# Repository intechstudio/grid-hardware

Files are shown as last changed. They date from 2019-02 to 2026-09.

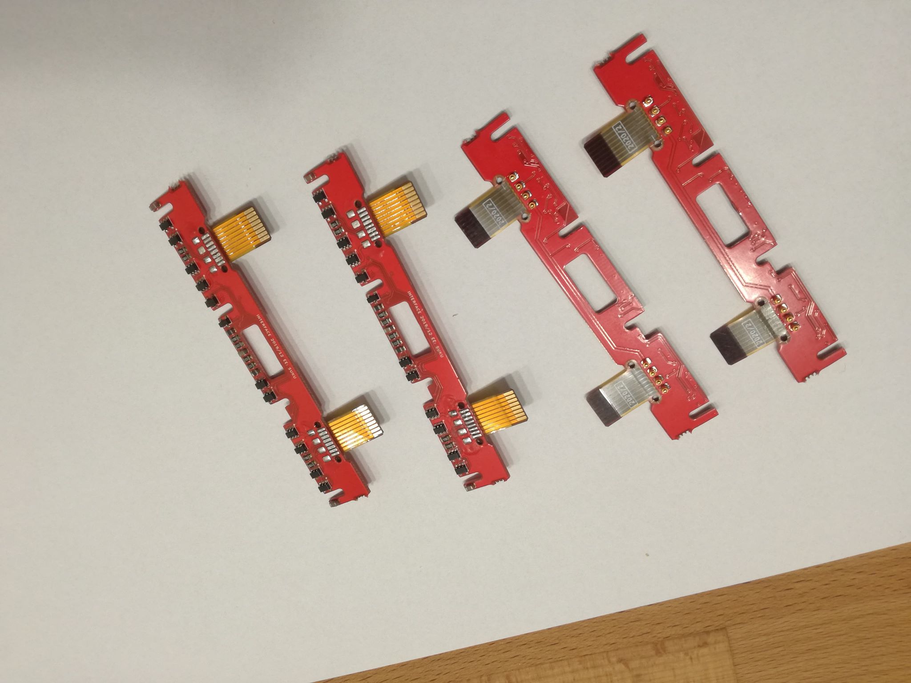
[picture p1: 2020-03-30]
Electrical/Bill Of Materials/Photos/interface.jpg

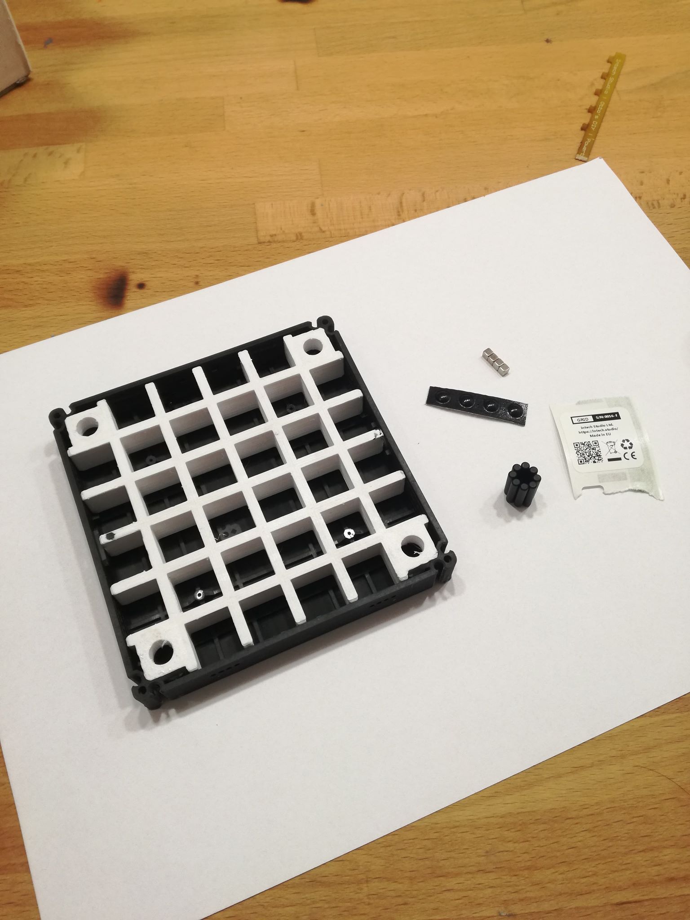
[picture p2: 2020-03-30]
Electrical/Bill Of Materials/Photos/canvas.jpg

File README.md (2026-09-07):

# Open-Source Hardware
https://certification.oshwa.org/hu000001.html

Licence: GPL3

# Mechanical components

| Component | Part number | Type | Preview | Links |
|---|---|---|---|---|
| Lower housing | PLASTIC-CANVAS | Fabricated |  | [[Model tree]](CANVAS.md) [[Download]](https://github.com/intechstudio/grid-hardware/releases/download/nightly-mechanical/PLASTIC-CANVAS.zip) |
| Mapmode button | PLASTIC-MAPMODE | Fabricated |  | [[Download]](https://github.com/intechstudio/grid-hardware/releases/download/nightly-mechanical/PLASTIC-MAPMODE.zip) | 
| Magnet cover | PLASTIC-MAGNET-COVER | Fabricated |  | [[Download]](https://github.com/intechstudio/grid-hardware/releases/download/nightly-mechanical/PLASTIC-MAGNET-COVER.zip) |  
| Rubber foot | RUBBER-FOOT | Fabricated |  | [[Download]](https://github.com/intechstudio/grid-hardware/releases/download/nightly-mechanical/RUBBER-FOOT.zip) |
| D3x14mm N52 neodymium | MAGNET-D3x14 | Fabricated |  | [[Download]](https://github.com/intechstudio/grid-hardware/releases/download/nightly-mechanical/MAGNET-D3x14.zip) |
| 3x3x3mm N52 neodymium | MAGNET-SQ3 | Fabricated |  | [[Download]](https://github.com/intechstudio/grid-hardware/releases/download/nightly-mechanical/MAGNET-SQ3.zip) |
| Crown | SPACER | Fabricated |  | [[Download]](https://github.com/intechstudio/grid-hardware/releases/download/nightly-mechanical/SPACER.zip) |
| Metric corner screw | SCREW-M1.6x16 | Purchased  |  | [[Download]](https://github.com/intechstudio/grid-hardware/releases/download/nightly-mechanical/SCREW-M1.6x16.zip) |
| Metric PCB screw | SCREW-M1.6x8 | Purchased  |  | [[Download]](https://github.com/intechstudio/grid-hardware/releases/download/nightly-mechanical/SCREW-M1.6x8.zip) |
| Metric PCB screw | SCREW-M1.6x5-C | Purchased  |  | [[Download]](https://github.com/intechstudio/grid-hardware/releases/download/nightly-mechanical/SCREW-M1.6x5-C.zip) |
| Brass threaded insert 3mm | INSERT-M1.6x2.5x3 | Purchased  |  | [[Download]](https://github.com/intechstudio/grid-hardware/releases/download/nightly-mechanical/INSERT-M1.6x2.5x3.zip) |
| Brass threaded insert 4mm | INSERT-M1.6x2.5x4 | Purchased  |  | [[Download]](https://github.com/intechstudio/grid-hardware/releases/download/nightly-mechanical/INSERT-M1.6x2.5x4.zip) |
| Lightpipe | PLASTIC-LIGHTPIPE | Purchased  |  | [[Download]](https://github.com/intechstudio/grid-hardware/releases/download/nightly-mechanical/PLASTIC-LIGHTPIPE.zip) |
| Encoder Knob Injection | PLASTIC-KNOB-ENC | Fabricated |  | [[Download]](https://github.com/intechstudio/grid-hardware/releases/download/nightly-mechanical/PLASTIC-KNOB-ENC.zip) |
| Potmeter Knob Injection | PLASTIC-KNOB-POT | Fabricated |  | [[Download]](https://github.com/intechstudio/grid-hardware/releases/download/nightly-mechanical/PLASTIC-KNOB-POT.zip) |
| Encoder | THT-ENC | Purchased  |  | [[Download]](https://github.com/intechstudio/grid-hardware/releases/download/nightly-mechanical/THT-ENC.zip) |
| Potmeter | THT-POT | Purchased  |  | [[Download]](https://github.com/intechstudio/grid-hardware/releases/download/nightly-mechanical/THT-POT.zip) |
| Fader | THT-FADER | Purchased  |  | [[Download]](https://github.com/intechstudio/grid-hardware/releases/download/nightly-mechanical/THT-FADER.zip) |
| Long Fader | THT-LONGFADER | Purchased  |  | [[Download]](https://github.com/intechstudio/grid-hardware/releases/download/nightly-mechanical/THT-LONGFADER.zip) |
| Fader Cap | PLASTIC-CAP-FADER | Purchased  |  | [[Download]](https://github.com/intechstudio/grid-hardware/releases/download/nightly-mechanical/PLASTIC-CAP-FADER.zip) |
| Fader Insert | INSERT-FADER | Fabricated  |  | [[Download]](https://github.com/intechstudio/grid-hardware/releases/download/nightly-mechanical/INSERT-FADER.zip) |
| Button | THT-BUTTON | Purchased  |  | [[Download]](https://github.com/intechstudio/grid-hardware/releases/download/nightly-mechanical/THT-BUTTON.zip) |
| Button Cap | PLASTIC-CAP-BUTTON | Purchased  |  | [[Download]](https://github.com/intechstudio/grid-hardware/releases/download/nightly-mechanical/PLASTIC-CAP-BUTTON.zip) |
| Hall Switch | THT-HALL-SWITCH | Purchased  |  | [[Download]](https://github.com/intechstudio/grid-hardware/releases/download/nightly-mechanical/THT-HALL-SWITCH.zip) |
| Low Profile Keycap | PLASTIC-LOW-PROFILE-KEYCAP | Purchased  |  | [[Download]](https://github.com/intechstudio/grid-hardware/releases/download/nightly-mechanical/PLASTIC-LOW-PROFILE-KEYCAP.zip) |
| Battery Connector | SMT-CONN-BATTERY | Purchased  |  | [[Download]](https://github.com/intechstudio/grid-hardware/releases/download/nightly-mechanical/SMT-CONN-BATTERY.zip) |
| Pogo Connector | SMT-CONN-POGO | Purchased  |  | [[Download]](https://github.com/intechstudio/grid-hardware/releases/download/nightly-mechanical/SMT-CONN-POGO.zip) |

# TEK2 specific components
| Component | Part number | Type | Preview | Links |
|---|---|---|---|---|
| Knob TEK2 | KNOB-TEK2 | Fabricated |  | [[Download]](https://github.com/intechstudio/grid-hardware/releases/download/nightly-mechanical/KNOB-TEK2.zip) |
| Knob interface TEK2 | PLASTIC-TEK2-KNOB-INTERFACE | Fabricated |  | [[Download]](https://github.com/intechstudio/grid-hardware/releases/download/nightly-mechanical/PLASTIC-TEK2-KNOB-INTERFACE.zip) |
| Endless potentiometer | THT-ENDLESSPOT | Purchased  |  | [[Download]](https://github.com/intechstudio/grid-hardware/releases/download/nightly-mechanical/THT-ENDLESSPOT.zip) |

# VSN1 specific components
| Component | Part number | Type | Preview | Links |
|---|---|---|---|---|
| VSN1 Display | SMT-VSN1-DISPLAY | Purchased |  | [[Download]](https://github.com/intechstudio/grid-hardware/releases/download/nightly-mechanical/SMT-VSN1-DISPLAY.zip) |
| VSN1 Display interface | PLASTIC-VSN1-DISPLAY-INTERFACE | Fabricated |  | [[Download]](https://github.com/intechstudio/grid-hardware/releases/download/nightly-mechanical/PLASTIC-VSN1-DISPLAY-INTERFACE.zip) |
| VSN1 Button | PLASTIC-VSN1-BUTTON | Fabricated |  | [[Download]](https://github.com/intechstudio/grid-hardware/releases/download/nightly-mechanical/PLASTIC-VSN1-BUTTON.zip) |

## PCB Frontpanel
| Component | Part number | Preview | Links |
|---|---|---|---|
| XX16 Frontpanel | FP-XX16 |  | [[STEP]](https://github.com/intechstudio/grid-hardware/releases/download/nightly-electrical/FP-XX16-3D.step) [[PCB3D]](https://github.com/intechstudio/grid-hardware/releases/download/nightly-electrical/FP-XX16-blender_export.pcb3d) [[Gerber]](https://github.com/intechstudio/grid-hardware/releases/download/nightly-electrical/FP-XX16-gerber.zip) |
| BU16 Frontpanel | FP-BU16 |  | [[STEP]](https://github.com/intechstudio/grid-hardware/releases/download/nightly-electrical/FP-BU16-3D.step) [[PCB3D]](https://github.com/intechstudio/grid-hardware/releases/download/nightly-electrical/FP-BU16-blender_export.pcb3d) [[Gerber]](https://github.com/intechstudio/grid-hardware/releases/download/nightly-electrical/FP-BU16-gerber.zip) |
| PBF4 Frontpanel | FP-PBF4 |  | [[STEP]](https://github.com/intechstudio/grid-hardware/releases/download/nightly-electrical/FP-PBF4-3D.step) [[PCB3D]](https://github.com/intechstudio/grid-hardware/releases/download/nightly-electrical/FP-PBF4-blender_export.pcb3d) [[Gerber]](https://github.com/intechstudio/grid-hardware/releases/download/nightly-electrical/FP-PBF4-gerber.zip) |
| EF44 Frontpanel | FP-EF44 |  | [[STEP]](https://github.com/intechstudio/grid-hardware/releases/download/nightly-electrical/FP-EF44-3D.step) [[PCB3D]](https://github.com/intechstudio/grid-hardware/releases/download/nightly-electrical/FP-EF44-blender_export.pcb3d) [[Gerber]](https://github.com/intechstudio/grid-hardware/releases/download/nightly-electrical/FP-EF44-gerber.zip) |
| TEK2 Frontpanel | FP-TEK2 |  | [[STEP]](https://github.com/intechstudio/grid-hardware/releases/download/nightly-electrical/FP-TEK2-3D.step) [[PCB3D]](https://github.com/intechstudio/grid-hardware/releases/download/nightly-electrical/FP-TEK2-blender_export.pcb3d) [[Gerber]](https://github.com/intechstudio/grid-hardware/releases/download/nightly-electrical/FP-TEK2-gerber.zip) |
| VSN1-L Frontpanel | FP-VSN1-L |  | [[STEP]](https://github.com/intechstudio/grid-hardware/releases/download/nightly-electrical/FP-VSN1-L-3D.step) [[PCB3D]](https://github.com/intechstudio/grid-hardware/releases/download/nightly-electrical/FP-VSN1-L-blender_export.pcb3d) [[Gerber]](https://github.com/intechstudio/grid-hardware/releases/download/nightly-electrical/FP-VSN1-L-gerber.zip) |
| VSN1-R Frontpanel | FP-VSN1-R |  | [[STEP]](https://github.com/intechstudio/grid-hardware/releases/download/nightly-electrical/FP-VSN1-R-3D.step) [[PCB3D]](https://github.com/intechstudio/grid-hardware/releases/download/nightly-electrical/FP-VSN1-R-blender_export.pcb3d) [[Gerber]](https://github.com/intechstudio/grid-hardware/releases/download/nightly-electrical/FP-VSN1-R-gerber.zip) |
| VSN2 Frontpanel | FP-VSN2 |  | [[STEP]](https://github.com/intechstudio/grid-hardware/releases/download/nightly-electrical/FP-VSN2-3D.step) [[PCB3D]](https://github.com/intechstudio/grid-hardware/releases/download/nightly-electrical/FP-VSN2-blender_export.pcb3d) [[Gerber]](https://github.com/intechstudio/grid-hardware/releases/download/nightly-electrical/FP-VSN2-gerber.zip) |
| OCTV Frontpanel | FP-OCTV |  | [[STEP]](https://github.com/intechstudio/grid-hardware/releases/download/nightly-electrical/FP-OCTV-3D.step) [[PCB3D]](https://github.com/intechstudio/grid-hardware/releases/download/nightly-electrical/FP-OCTV-blender_export.pcb3d) [[Gerber]](https://github.com/intechstudio/grid-hardware/releases/download/nightly-electrical/FP-OCTV-gerber.zip) |
| ZONA Frontpanel | FP-ZONA |  | [[STEP]](https://github.com/intechstudio/grid-hardware/releases/download/nightly-electrical/FP-ZONA-3D.step) [[PCB3D]](https://github.com/intechstudio/grid-hardware/releases/download/nightly-electrical/FP-ZONA-blender_export.pcb3d) [[Gerber]](https://github.com/intechstudio/grid-hardware/releases/download/nightly-electrical/FP-ZONA-gerber.zip) |
| ZONA SPACER Frontpanel | FP-ZONA-SPACER |  | [[STEP]](https://github.com/intechstudio/grid-hardware/releases/download/nightly-electrical/FP-ZONA-SPACER-3D.step) [[PCB3D]](https://github.com/intechstudio/grid-hardware/releases/download/nightly-electrical/FP-ZONA-SPACER-blender_export.pcb3d) [[Gerber]](https://github.com/intechstudio/grid-hardware/releases/download/nightly-electrical/FP-ZONA-SPACER-gerber.zip) |
| ZONA Decor Frontpanel | FP-ZONA-DECOR |  | [[STEP]](https://github.com/intechstudio/grid-hardware/releases/download/nightly-electrical/FP-ZONA-DECOR-3D.step) [[PCB3D]](https://github.com/intechstudio/grid-hardware/releases/download/nightly-electrical/FP-ZONA-DECOR-blender_export.pcb3d) [[Gerber]](https://github.com/intechstudio/grid-hardware/releases/download/nightly-electrical/FP-ZONA-DECOR-gerber.zip) |

## PCB Frontpanel Collaborations
| Component | Part number | Preview | Links |
|---|---|---|---|
| BU16 MIDIGrade Frontpanel | FP-BU16-MIDIGRADE |  | [[STEP]](https://github.com/intechstudio/grid-hardware/releases/download/nightly-electrical/FP-BU16-MIDIGRADE-3D.step) [[PCB3D]](https://github.com/intechstudio/grid-hardware/releases/download/nightly-electrical/FP-BU16-MIDIGRADE-blender_export.pcb3d) [[Gerber]](https://github.com/intechstudio/grid-hardware/releases/download/nightly-electrical/FP-BU16-MIDIGRADE-gerber.zip) |
| BU16 MIDIGrade Frontpanel | FP-EN16-MIDIGRADE |  | [[STEP]](https://github.com/intechstudio/grid-hardware/releases/download/nightly-electrical/FP-EN16-MIDIGRADE-3D.step) [[PCB3D]](https://github.com/intechstudio/grid-hardware/releases/download/nightly-electrical/FP-EN16-MIDIGRADE-blender_export.pcb3d) [[Gerber]](https://github.com/intechstudio/grid-hardware/releases/download/nightly-electrical/FP-EN16-MIDIGRADE-gerber.zip) |
| PBF4 Classic Frontpanel | FP-PBF4-CLASSIC |  | [[STEP]](https://github.com/intechstudio/grid-hardware/releases/download/nightly-electrical/FP-PBF4-CLASSIC-3D.step) [[PCB3D]](https://github.com/intechstudio/grid-hardware/releases/download/nightly-electrical/FP-PBF4-CLASSIC-blender_export.pcb3d) [[Gerber]](https://github.com/intechstudio/grid-hardware/releases/download/nightly-electrical/FP-PBF4-CLASSIC-gerber.zip) |
| TEK2 Classic Frontpanel | FP-TEK2-CLASSIC |  | [[STEP]](https://github.com/intechstudio/grid-hardware/releases/download/nightly-electrical/FP-TEK2-CLASSIC-3D.step) [[PCB3D]](https://github.com/intechstudio/grid-hardware/releases/download/nightly-electrical/FP-TEK2-CLASSIC-blender_export.pcb3d) [[Gerber]](https://github.com/intechstudio/grid-hardware/releases/download/nightly-electrical/FP-TEK2-CLASSIC-gerber.zip) |
| XX16 Test Frontpanel | FP-XX16-TEST |  | [[STEP]](https://github.com/intechstudio/grid-hardware/releases/download/nightly-electrical/FP-XX16-TEST-3D.step) [[PCB3D]](https://github.com/intechstudio/grid-hardware/releases/download/nightly-electrical/FP-XX16-TEST-blender_export.pcb3d) [[Gerber]](https://github.com/intechstudio/grid-hardware/releases/download/nightly-electrical/FP-XX16-TEST-gerber.zip) |

## Electrical components

| Component | Part number | Preview | Links |
|---|---|---|---|
| Debug Acessory | PCBA-DEBUG-ACCESSORY |  | [[Schematic]](https://github.com/intechstudio/grid-hardware/releases/download/nightly-electrical/PCBA-DEBUG-ACCESSORY_Schematic.pdf) [[STEP]](https://github.com/intechstudio/grid-hardware/releases/download/nightly-electrical/PCBA-DEBUG-ACCESSORY-3D.step) [[Gerber]](https://github.com/intechstudio/grid-hardware/releases/download/nightly-electrical/PCBA-DEBUG-ACCESSORY-gerber.zip)  [[PCB3D]](https://github.com/intechstudio/grid-hardware/releases/download/nightly-electrical/PCBA-DEBUG-ACCESSORY-blender_export.pcb3d)  |
| Debug UART | PCBA-DEBUG-UART |  | [[Schematic]](https://github.com/intechstudio/grid-hardware/releases/download/nightly-electrical/PCBA-DEBUG-UART_Schematic.pdf) [[STEP]](https://github.com/intechstudio/grid-hardware/releases/download/nightly-electrical/PCBA-DEBUG-UART-3D.step) [[Gerber]](https://github.com/intechstudio/grid-hardware/releases/download/nightly-electrical/PCBA-DEBUG-UART-gerber.zip)  [[PCB3D]](https://github.com/intechstudio/grid-hardware/releases/download/nightly-electrical/PCBA-DEBUG-UART-blender_export.pcb3d)  |
| Interface Board | PCBA-INTERFACE |  | [[Schematic]](https://github.com/intechstudio/grid-hardware/releases/download/nightly-electrical/PCBA-INTERFACE_Schematic.pdf) [[STEP]](https://github.com/intechstudio/grid-hardware/releases/download/nightly-electrical/PCBA-INTERFACE-3D.step) [[Gerber]](https://github.com/intechstudio/grid-hardware/releases/download/nightly-electrical/PCBA-INTERFACE-gerber.zip)  [[PCB3D]](https://github.com/intechstudio/grid-hardware/releases/download/nightly-electrical/PCBA-INTERFACE-blender_export.pcb3d)  |
| PO16/BU16 Motherboard | PCBA-PO16 |  | [[schematic]](https://github.com/intechstudio/grid-hardware/releases/download/nightly-electrical/PCBA-PO16_Schematic.pdf) [[STEP]](https://github.com/intechstudio/grid-hardware/releases/download/nightly-electrical/PCBA-PO16-3D.step) [[PCB3D]](https://github.com/intechstudio/grid-hardware/releases/download/nightly-electrical/PCBA-PO16-blender_export.pcb3d) [[Gerber]](https://github.com/intechstudio/grid-hardware/releases/download/nightly-electrical/PCBA-PO16-gerber.zip) |
| ZONA Motherboard | PCBA-ZONA |  | [[schematic]](https://github.com/intechstudio/grid-hardware/releases/download/nightly-electrical/PCBA-ZONA_Schematic.pdf) [[STEP]](https://github.com/intechstudio/grid-hardware/releases/download/nightly-electrical/PCBA-ZONA-3D.step) [[PCB3D]](https://github.com/intechstudio/grid-hardware/releases/download/nightly-electrical/PCBA-ZONA-blender_export.pcb3d) [[Gerber]](https://github.com/intechstudio/grid-hardware/releases/download/nightly-electrical/PCBA-ZONA-gerber.zip) |
| BU16 Motherboard | PCBA-BU16 |  | [[schematic]](https://github.com/intechstudio/grid-hardware/releases/download/nightly-electrical/PCBA-BU16_Schematic.pdf) [[STEP]](https://github.com/intechstudio/grid-hardware/releases/download/nightly-electrical/PCBA-BU16-3D.step) [[PCB3D]](https://github.com/intechstudio/grid-hardware/releases/download/nightly-electrical/PCBA-BU16-blender_export.pcb3d) [[Gerber]](https://github.com/intechstudio/grid-hardware/releases/download/nightly-electrical/PCBA-BU16-gerber.zip) |
| BU16 SPACER | PCBA-BU16-SPACER |  | [[schematic]](https://github.com/intechstudio/grid-hardware/releases/download/nightly-electrical/PCBA-BU16-SPACER_Schematic.pdf) [[STEP]](https://github.com/intechstudio/grid-hardware/releases/download/nightly-electrical/PCBA-BU16-SPACER-3D.step) [[PCB3D]](https://github.com/intechstudio/grid-hardware/releases/download/nightly-electrical/PCBA-BU16-SPACER-blender_export.pcb3d) [[Gerber]](https://github.com/intechstudio/grid-hardware/releases/download/nightly-electrical/PCBA-BU16-SPACER-gerber.zip) |
| BU16 PLATE | PCBA-BU16-PLATE |  | [[schematic]](https://github.com/intechstudio/grid-hardware/releases/download/nightly-electrical/PCBA-BU16-PLATE_Schematic.pdf) [[STEP]](https://github.com/intechstudio/grid-hardware/releases/download/nightly-electrical/PCBA-BU16-PLATE-3D.step) [[PCB3D]](https://github.com/intechstudio/grid-hardware/releases/download/nightly-electrical/PCBA-BU16-PLATE-blender_export.pcb3d) [[Gerber]](https://github.com/intechstudio/grid-hardware/releases/download/nightly-electrical/PCBA-BU16-PLATE-gerber.zip) |
| PBF4 SPACER | PCBA-PBF4-SPACER |  | [[schematic]](https://github.com/intechstudio/grid-hardware/releases/download/nightly-electrical/PCBA-PBF4-SPACER_Schematic.pdf) [[STEP]](https://github.com/intechstudio/grid-hardware/releases/download/nightly-electrical/PCBA-PBF4-SPACER-3D.step) [[PCB3D]](https://github.com/intechstudio/grid-hardware/releases/download/nightly-electrical/PCBA-PBF4-SPACER-blender_export.pcb3d) [[Gerber]](https://github.com/intechstudio/grid-hardware/releases/download/nightly-electrical/PCBA-PBF4-SPACER-gerber.zip) |
| PBF4 PLATE | PCBA-PBF4-PLATE |  | [[schematic]](https://github.com/intechstudio/grid-hardware/releases/download/nightly-electrical/PCBA-PBF4-PLATE_Schematic.pdf) [[STEP]](https://github.com/intechstudio/grid-hardware/releases/download/nightly-electrical/PCBA-PBF4-PLATE-3D.step) [[PCB3D]](https://github.com/intechstudio/grid-hardware/releases/download/nightly-electrical/PCBA-PBF4-PLATE-blender_export.pcb3d) [[Gerber]](https://github.com/intechstudio/grid-hardware/releases/download/nightly-electrical/PCBA-PBF4-PLATE-gerber.zip) |
| PBF4 Motherboard | PCBA-PBF4 |  | [[schematic]](https://github.com/intechstudio/grid-hardware/releases/download/nightly-electrical/PCBA-PBF4_Schematic.pdf) [[STEP]](https://github.com/intechstudio/grid-hardware/releases/download/nightly-electrical/PCBA-PBF4-3D.step) [[PCB3D]](https://github.com/intechstudio/grid-hardware/releases/download/nightly-electrical/PCBA-PBF4-blender_export.pcb3d) [[Gerber]](https://github.com/intechstudio/grid-hardware/releases/download/nightly-electrical/PCBA-PBF4-gerber.zip) |
| EN16 Motherboard | PCBA-EN16 |  | [[schematic]](https://github.com/intechstudio/grid-hardware/releases/download/nightly-electrical/PCBA-EN16_Schematic.pdf) [[STEP]](https://github.com/intechstudio/grid-hardware/releases/download/nightly-electrical/PCBA-EN16-3D.step) [[PCB3D]](https://github.com/intechstudio/grid-hardware/releases/download/nightly-electrical/PCBA-EN16-blender_export.pcb3d) [[Gerber]](https://github.com/intechstudio/grid-hardware/releases/download/nightly-electrical/PCBA-EN16-gerber.zip) |
| EF44 Motherboard | PCBA-EF44 |  | [[schematic]](https://github.com/intechstudio/grid-hardware/releases/download/nightly-electrical/PCBA-EF44_Schematic.pdf) [[STEP]](https://github.com/intechstudio/grid-hardware/releases/download/nightly-electrical/PCBA-EF44-3D.step) [[PCB3D]](https://github.com/intechstudio/grid-hardware/releases/download/nightly-electrical/PCBA-EF44-blender_export.pcb3d) [[Gerber]](https://github.com/intechstudio/grid-hardware/releases/download/nightly-electrical/PCBA-EF44-gerber.zip) |
| VSNX Motherboard | PCBA-VSNX |  | [[schematic]](https://github.com/intechstudio/grid-hardware/releases/download/nightly-electrical/PCBA-VSNX_Schematic.pdf) [[STEP]](https://github.com/intechstudio/grid-hardware/releases/download/nightly-electrical/PCBA-VSNX-3D.step) [[PCB3D]](https://github.com/intechstudio/grid-hardware/releases/download/nightly-electrical/PCBA-VSNX-blender_export.pcb3d) [[Gerber]](https://github.com/intechstudio/grid-hardware/releases/download/nightly-electrical/PCBA-VSNX-gerber.zip) |
| VSNX SPACER | PCBA-VSNX-SPACER |  | [[schematic]](https://github.com/intechstudio/grid-hardware/releases/download/nightly-electrical/PCBA-VSNX-SPACER_Schematic.pdf) [[STEP]](https://github.com/intechstudio/grid-hardware/releases/download/nightly-electrical/PCBA-VSNX-SPACER-3D.step) [[PCB3D]](https://github.com/intechstudio/grid-hardware/releases/download/nightly-electrical/PCBA-VSNX-SPACER-blender_export.pcb3d) [[Gerber]](https://github.com/intechstudio/grid-hardware/releases/download/nightly-electrical/PCBA-VSNX-SPACER-gerber.zip) |
| VSNX PLATE | PCBA-VSNX-PLATE |  | [[schematic]](https://github.com/intechstudio/grid-hardware/releases/download/nightly-electrical/PCBA-VSNX-PLATE_Schematic.pdf) [[STEP]](https://github.com/intechstudio/grid-hardware/releases/download/nightly-electrical/PCBA-VSNX-PLATE-3D.step) [[PCB3D]](https://github.com/intechstudio/grid-hardware/releases/download/nightly-electrical/PCBA-VSNX-PLATE-blender_export.pcb3d) [[Gerber]](https://github.com/intechstudio/grid-hardware/releases/download/nightly-electrical/PCBA-VSNX-PLATE-gerber.zip) |
| VSNX LCD MOUNT | PCBA-VSNX-LCDMOUNT |  | [[schematic]](https://github.com/intechstudio/grid-hardware/releases/download/nightly-electrical/PCBA-VSNX-LCDMOUNT_Schematic.pdf) [[STEP]](https://github.com/intechstudio/grid-hardware/releases/download/nightly-electrical/PCBA-VSNX-LCDMOUNT-3D.step) [[PCB3D]](https://github.com/intechstudio/grid-hardware/releases/download/nightly-electrical/PCBA-VSNX-LCDMOUNT-blender_export.pcb3d) [[Gerber]](https://github.com/intechstudio/grid-hardware/releases/download/nightly-electrical/PCBA-VSNX-LCDMOUNT-gerber.zip) |
| OCTV Motherboard | PCBA-OCTV |  | [[schematic]](https://github.com/intechstudio/grid-hardware/releases/download/nightly-electrical/PCBA-OCTV_Schematic.pdf) [[STEP]](https://github.com/intechstudio/grid-hardware/releases/download/nightly-electrical/PCBA-OCTV-3D.step) [[PCB3D]](https://github.com/intechstudio/grid-hardware/releases/download/nightly-electrical/PCBA-OCTV-blender_export.pcb3d) [[Gerber]](https://github.com/intechstudio/grid-hardware/releases/download/nightly-electrical/PCBA-OCTV-gerber.zip) |
| OCTV SPACER | PCBA-OCTV-SPACER |  | [[schematic]](https://github.com/intechstudio/grid-hardware/releases/download/nightly-electrical/PCBA-OCTV-SPACER_Schematic.pdf) [[STEP]](https://github.com/intechstudio/grid-hardware/releases/download/nightly-electrical/PCBA-OCTV-SPACER-3D.step) [[PCB3D]](https://github.com/intechstudio/grid-hardware/releases/download/nightly-electrical/PCBA-OCTV-SPACER-blender_export.pcb3d) [[Gerber]](https://github.com/intechstudio/grid-hardware/releases/download/nightly-electrical/PCBA-OCTV-SPACER-gerber.zip) |
| OCTV PLATE | PCBA-OCTV-PLATE |  | [[schematic]](https://github.com/intechstudio/grid-hardware/releases/download/nightly-electrical/PCBA-OCTV-PLATE_Schematic.pdf) [[STEP]](https://github.com/intechstudio/grid-hardware/releases/download/nightly-electrical/PCBA-OCTV-PLATE-3D.step) [[PCB3D]](https://github.com/intechstudio/grid-hardware/releases/download/nightly-electrical/PCBA-OCTV-PLATE-blender_export.pcb3d) [[Gerber]](https://github.com/intechstudio/grid-hardware/releases/download/nightly-electrical/PCBA-OCTV-PLATE-gerber.zip) |

## Packaging
| Component | Part number | Preview | Links |
|---|---|---|---|
| PO16 Sleeve | PACKAGING-SLEEVE-PO16 |  | [[PDF]](../master/Packaging/PACKAGING-SLEEVE-PO16.pdf) |
| BU16 Sleeve | PACKAGING-SLEEVE-BU16 |  | [[PDF]](../master/Packaging/PACKAGING-SLEEVE-BU16.pdf) |
| PBF4 Sleeve | PACKAGING-SLEEVE-PBF4 |  | [[PDF]](../master/Packaging/PACKAGING-SLEEVE-PBF4.pdf) |
| EN16 Sleeve | PACKAGING-SLEEVE-EN16 |  | [[PDF]](../master/Packaging/PACKAGING-SLEEVE-EN16.pdf) |
| EF44 Sleeve | PACKAGING-SLEEVE-EF44 |  | [[PDF]](../master/Packaging/PACKAGING-SLEEVE-EF44.pdf) |
| TEK2 Sleeve | PACKAGING-SLEEVE-TEK2 |  | [[PDF]](../master/Packaging/PACKAGING-SLEEVE-TEK2.pdf) |
| VSN1-L Sleeve | PACKAGING-SLEEVE-VSN1-L |  | [[PDF]](../master/Packaging/PACKAGING-SLEEVE-VSN1-L.pdf) |
| VSN1-R Sleeve | PACKAGING-SLEEVE-VSN1-R |  | [[PDF]](../master/Packaging/PACKAGING-SLEEVE-VSN1-R.pdf) |

# Desktop Tools Used
- FreeCAD
- KiCAD
# Command-Line Tools Used
- PytonOCC
- OpenSCAD
- KiBOT

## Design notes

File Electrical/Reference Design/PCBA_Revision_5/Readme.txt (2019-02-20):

Filelist:
SAME54_Xplained_Pro_layer_plots_release_rev5.pdf : PCB Layer Plots
BOM\Bill of Materials Print- SAME54_Xplained_Pro_release_rev5.xls : BOM, fitted components
ExportSTEP\SAME54_Xplained_Pro_release_rev5.step : 3D Model of PCBA
NC Drill\SAME54_Xplained_Pro_release_rev5.drl : Drill files, gerber
NC Drill\SAME54_Xplained_Pro_release_rev5.drr : Drill Files Report
Pick Place\Pick Place for SAME54_Xplained_Pro_release_rev5.txt : Pick and Place file, component placement
Test Points\Assembly Testpoint Report for SAME54_Xplained_Pro_release_rev5.txt : Assembly Testpoint report, txt
Test Points\Assembly Testpoint Report for SAME54_Xplained_Pro_release_rev5.csv : Assembly Testpoint report, csv
NC Drill\SAME54_Xplained_Pro_-SlotHoles_release_rev5.txt : Drill files, ASCII-SlotHoles
NC Drill\SAME54_Xplained_Pro_-RoundHoles_release_rev5.txt : Drill files, ASCII-RoundHoles
SAME54_Xplained_Pro_design_documentation_release_rev5.pdf : Design Documentation with Bom
Gerber\SAME54_Xplained_Pro_release_rev5.GP1 : Gerber files for GND
Gerber\SAME54_Xplained_Pro_release_rev5.GP2 : Gerber files for POWER
Gerber\SAME54_Xplained_Pro_release_rev5.GM1 : Gerber files for Board (M1)
Gerber\SAME54_Xplained_Pro_release_rev5.GBO : Gerber files for Bottom Overlay
Gerber\SAME54_Xplained_Pro_release_rev5.GBL : Gerber files for Bottom Layer LF-signals
Gerber\SAME54_Xplained_Pro_release_rev5.GBS : Gerber files for Bottom Solder
Gerber\SAME54_Xplained_Pro_release_rev5.GBP : Gerber files for Bottom Paste
Gerber\SAME54_Xplained_Pro_release_rev5.GTP : Gerber files for Top Paste
Gerber\SAME54_Xplained_Pro_release_rev5.GTS : Gerber files for Top Solder
Gerber\SAME54_Xplained_Pro_release_rev5.GTL : Gerber files for Top Layer LF-signals
Gerber\SAME54_Xplained_Pro_release_rev5.GTO : Gerber files for Top Overlay
NC Drill\SAME54_Xplained_Pro_release_rev5.LDP : Layer Pairs Definition

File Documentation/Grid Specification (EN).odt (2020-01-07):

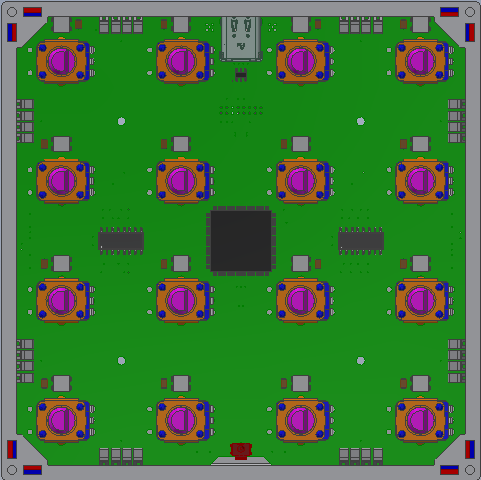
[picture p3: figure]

Grid4 Specification

# Specification Summery

## Grid Features

- Ultra-mobile MIDI controller solution
- Extendable control surface (Grid magnetic interface)
- USB C receptacle
- USB Bus powered device (5V 3A, optional PD)
- USB2.0 compliant composite device (Audio Device Midi, CDC Serial, DFU Bootloader)
- Compatible with Windows, Mac and Linux (No drivers needed)
- Tactile user interface
- Aluminum front-panel
- Full-color RGB LEDs
- Compact size: 106mm x 106mm x 16mm (4.2” x 4.2” x 0.6”)
- Light weight: 200g (7oz)
- Eurorack compatible (21HP)

# Mechanical design

## Form factor

The nominal module dimensions are 106.6mm*106.6mm*16mm.

106.68mm = 21HP = 4.2in

## Plastic housing

The injection molded plastic housing is 106.6mm*106.6mm*14.4mm.

Outer draft angle: 0°

Inner draft angle: 2.5° nominal

Material: ABS or PP

Color: White

## PCB

The main printed circuit-board is 100mm*100mm*1.6mm.

Material: FR4 (TG130-140)

Layer count: 4-layer

Stackup: TBA

Surface: Immersion Gold.

RoHS

# Interface design

The for sides of the controllers have identical interfaces for communication. These are referred to as North, East, South and West going clockwise around the controller.

## Magnets

The modules are held together by the magnets. This provides the mechanical stability of the control surface. Two neodymium magnets are installed on each side of the controller.

Each magnet has a North and South pole (not to be confused with the sides of the controller.) North pole is usually Red, the South pole is usually (Blue or Green)

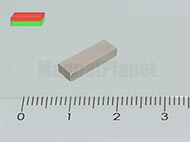
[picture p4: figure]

Illustration 1: B-12-4-2N38 from MagnetPlanet

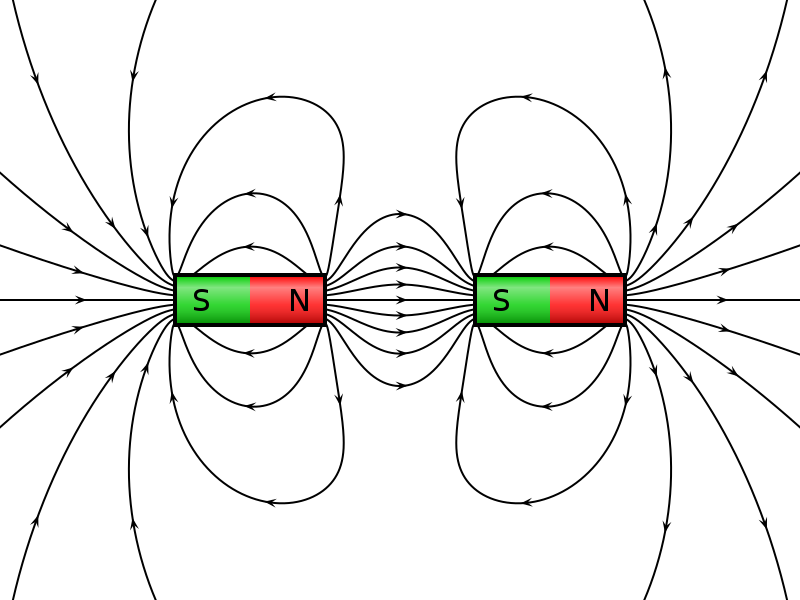
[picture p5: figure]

Illustration 3: Interaction of two permanent magnets (Wiki commons)

NORTH
WEST EAST
SOUTHIllustration 2: Top view of the plastic housing with the magnets installed.

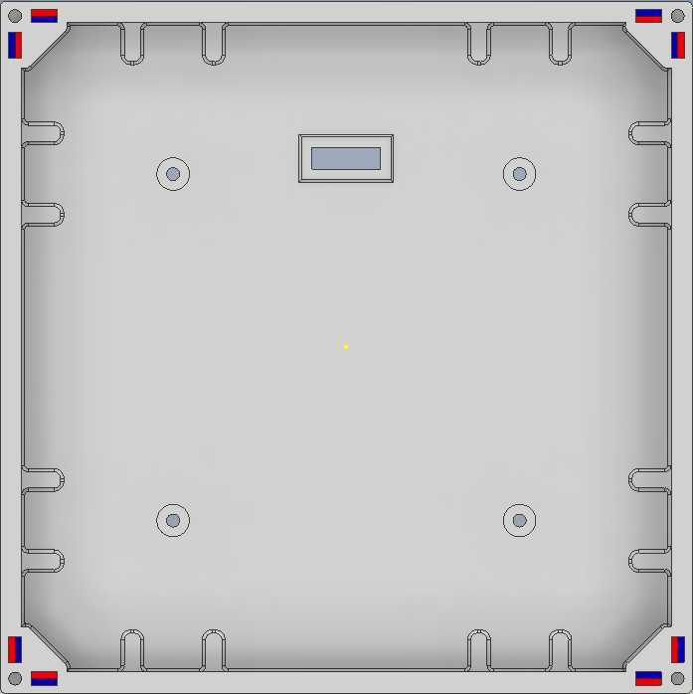
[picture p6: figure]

## Pogo pins

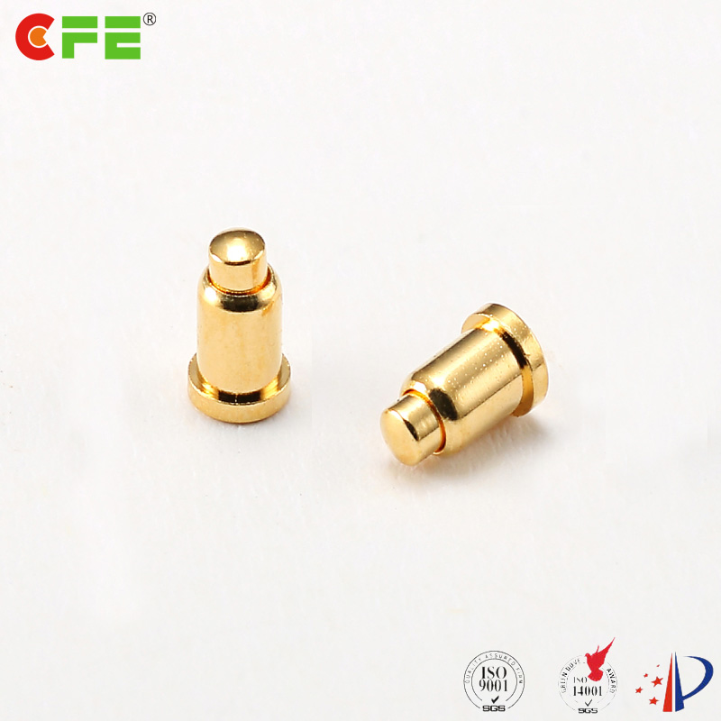
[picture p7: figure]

Illustration 4: Male pogo pin connector

Spring loaded pogo pin connector are used to electrically interface two neighboring module. These connectors provide bidirectional data and power throughout the Grid. Each side of the module has eight pins. All of the pins are spring loaded (male type). Working height has to be as short as possible to reduce the overall stress on the pin during mating.

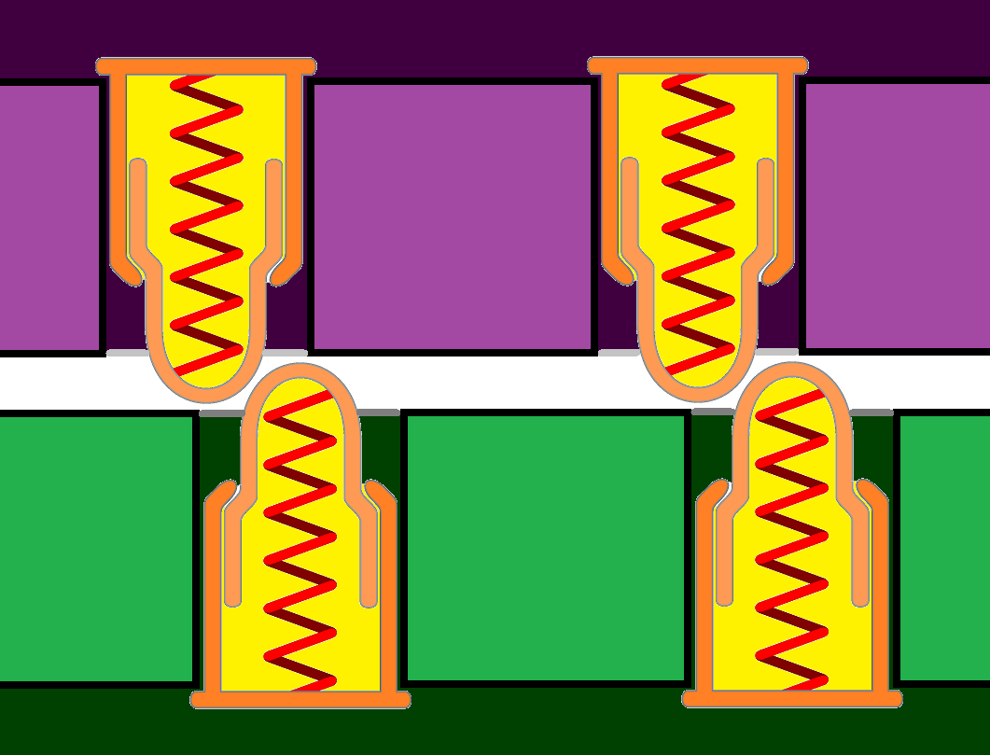
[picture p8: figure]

Illustration 5: Worst case stress on the pogo pins

## Physical composition

Each component in the Grid ecosystem is carefully designed to be reusable in the upcoming designs.

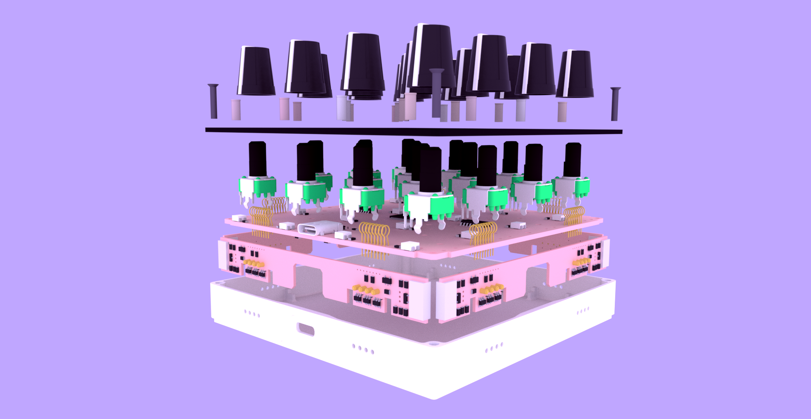
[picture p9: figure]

1 2 3 4 5

1. Injection molded plastic housing

2. Aluminum front-panel

3. Main PCB accommodating the user interface and the main application processor

4. Interface PCB designed to connect to the neighboring modules

5. Potentiometer caps and other tactile components

## Main PCB

There are a number of components on the main PCB that are common across all Grid modules. This allows the reuse of the housing and most of the firmware components.

2 1 3 4 5

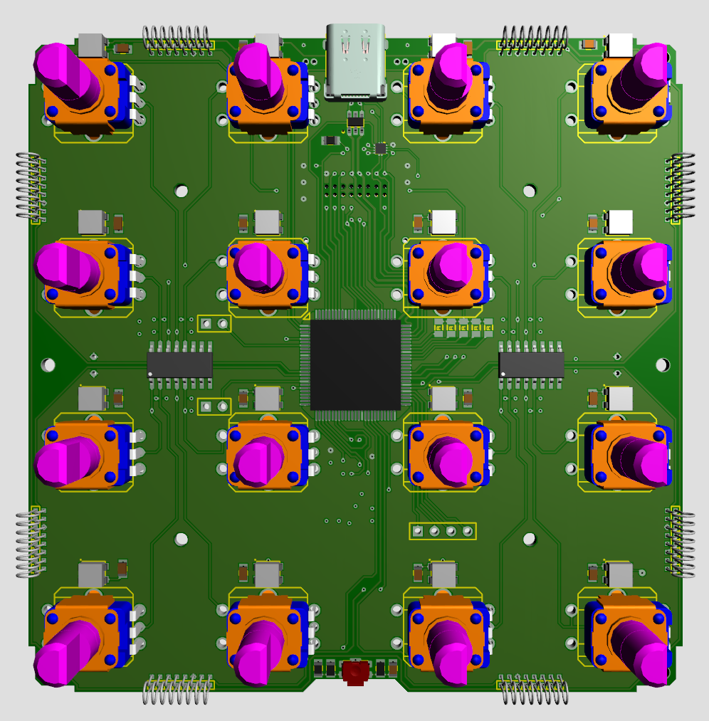
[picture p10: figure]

Figure 1: Main PCB of the P16 module

1. Main application processor

2. USB C connector and support circuitry

3. RGB LEDs

4. Bottom entry docking connector (eurorack)

5. Map mode button

## Interface Board (Sub-assembly) [HW Component]

Source: G4 Project → G4 Elec / Design

Every module has four interface boards designed to accommodate the signal switching, ESD protections and field detection circuitry. The installed pogo pins make contact with the neighboring modules, while the elongated pads on the other side mate with the spring loaded thest points on the modules main PCB.

Nominal parameters of the board:

- 12mm * 96mm dimensions

Requirements for the interface board:

- The finished FR4 PCB must be 1mm thick
- It must fit one 10mm * 6mm * 3mm neodymium magnet on each side
- The SMD components must be on one side of the board (facing away from the module)
- The SMD components must not be higher than 1mm (always check boundary box)
- For production the board must be Lead-Free (RoHS)
- For production the pads must be gold plated (immersion gold)

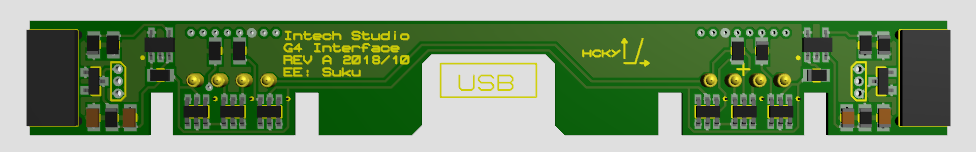
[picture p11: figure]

## Pogo Pin (External) [HW Component]

Source: Grid / Mechanical / Design / Pogo

The Spring loaded connectors that are used on all four sides of the controllers are custom designed by Intech Studio. Design files and requirements can be found in the Mechanical submodule of the Grid4 repository.

Each interface board has 8 pogo pins, a total of 24 pins are required for each Grid4 module. The pins are THT (Through-Hole), but they are only 1mm long so they are flush with the solder side of the Interface board. They can be hand soldered or reflowed (pin-in-paste).

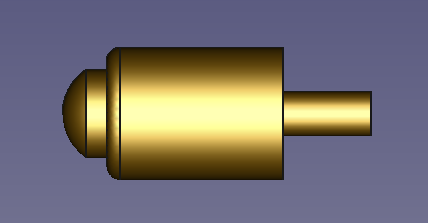
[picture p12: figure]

Figure 2: CFE: Custom manufactured component.

## Pogo Pin (Internal) [HW Component]

Source: Grid / Mechanical / Design / Pogo

Pogo pins are used to connect the interface boards to the main PCB. This allows quick, non-destructive replacement of the interface board (ideal for testing and servicing). Designed for SMD reflow soldering. For production this pins can be replaced with solder fillets to save cost.

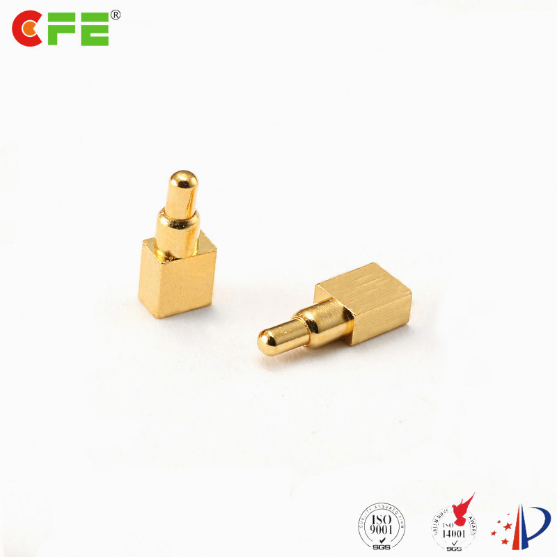
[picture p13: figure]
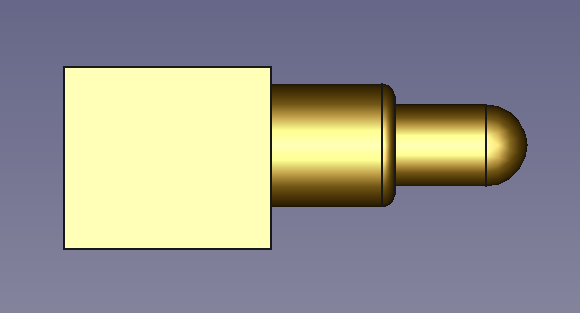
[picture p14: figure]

Figure 3: CFC: BP109621

## Grid Protocol [FW Component]

Source: G4 Project

Grid4 Modules use the Grid protocol to communicate through the magnetic interface. The Grid protocol is optimized for high data throughput, efficient error detection and low latency. The data has to be formatted by the host module (the one connected to the USB port) to match the format of various USB Classes, most importantly the USB Hid MIDI Specification. All addresses and commands have to be mapped to a supported Midi parameter. The Grid4 USB Translation strategy can be configured by the user from the Grid4 Configurator.

## Grid4 USB Composite Device (FW Component)

## Source: G4 Project

## When connected to a USB Host, a Grid4 module shows up as a USB Composite device by default. If the Mapmode button is pressed during the startup, the module enters bootloader mode and enumerates as a USB Mass Storage Device. The binary firmware file can be directly copied to the device.

## Grid4 USB Translator (FW Component)

## Source: G4 Project

## The Grid Translator takes the Grid4 Protocol communication and converts the messages the fit the supported USB Classes and vice versa.

Grid 4 Protocol USB Stack CDC Serial
(Grid4 Protocol) HID Midi
(Translated) HID Keyboard
(Translated)

### CDC Serial (Raw Grid4 Protocol)

The Grid4 Protocol is directly sent over USB through the CDC Serial driver. This allows the most flexible software integration, can be used by a custom Driver Utility to control non MIDI applications like Adobe Photoshop, Premier Pro and More.

### Audio Device - (Translated)

The Midi driver can by used by any Midi compatible application. This does not require additional drivers. The challenge is to map the Grid4 Protocol’s addressing scheme to fit the USB Midistreaming specification.

## Grid4 Configurator (SW Component)

Source: G4 Project

Addressing

- Fixed address (Saved on module)
  - Set CC number per controller
- Relative address (Based on position)
  - CC number is also relative

Input modes

- Button
  - Note On / Not Off (momentary)
  - Note On / Not Off (toggle)
  - Note On / Not Off (stepping increment range)
  - Control Change (on / off = high / low value)
  - Control Change (stepping increment range)
- Potentiometer
  - Control Change (0-127)
  - Control Change (Center dent calibration)
  - Note On / Not Off (Voltage comperator)
- Encoder
  - Button: Note On / Not Off (momentary)
  - Button: Note On / Not Off (toggle)
  - Note On / Not Off (stepping increment range)
  - Rotation: Control Change (Relative/Incremental)
- Analog input
  - CV input: Control Change (Sample rate limiter, resolution limiter, smart noise AI)
  - Gate input: Note On / Note Off (Logic -level comperator)
  - Audio input: Soundcard Driver (Sample rate, Bit depth)

Output modes

- LED
  - Actuator (TBA)
  - Animator (TBA)
- Analog output
  - CV Output: TBA Midi Mode
  - GATE Output: TBA Midi Mode

Intech Studio: Grid4 Specification (Internal use only)

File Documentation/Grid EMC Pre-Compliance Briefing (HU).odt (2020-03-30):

Grid EMC tájékoztató

Grid moduláris vezérlő

# Rövid összefoglaló

A Grid egy USB csatlakozású szorakoztató-elektronikai eszköz, mely kreatív szoftverek hatékony vezérlésére lett kifejlesztve. Több, műszakilag azonos, azonban eltérő felhasználói felülettel (gombok, tolópotméterek, enkóderek) ellátott modul csatlakozik egymáshoz. Így alakul ki egy összefüggő, egységes, a felhasználó aktuális igényeinek megfelelő kezelőfelület. A modulokat a gyors szerelhetőség miatt mágnesek pozícionálják és tartják össze. Az adatátvitelt és tápellátást a modulok oldalán elhelyezett rugós csatlakozósorok biztosítják. A számítógéphez elég egy modult csatlakoztatni, a rendszerben lévő többi modul ezen keresztül tartja a kapcsolatot.

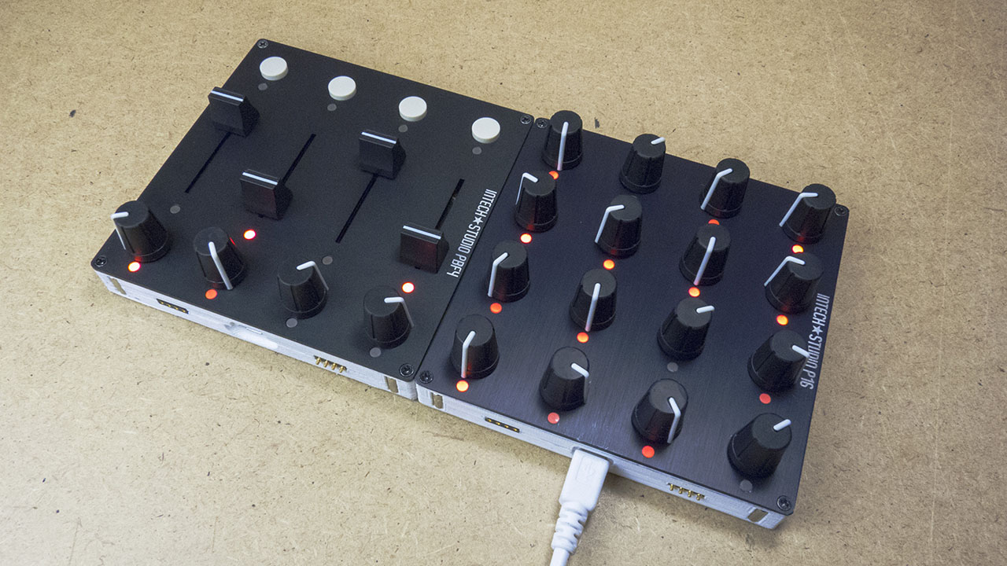
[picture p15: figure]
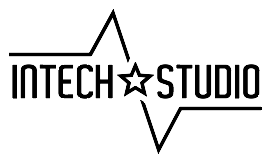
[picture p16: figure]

Céges információk: Kapcsolattartó:

Intech Studio kft Sövény Gergely Máté (technológiai felelős)

6640 Csongrád, Tanya 40 soveny@intech.studio

# A termék relaizációjára vonatkozó műszaki megoldások

## Készülékház

A készülék funkcionális részei egy műanyag alsó héjba vannak beszerelve, a végső összeszereléskor kap a termék egy alumínium fedlapot, mely elektromos kapcsolatban nincs a termékben lévő áramkörökkel.

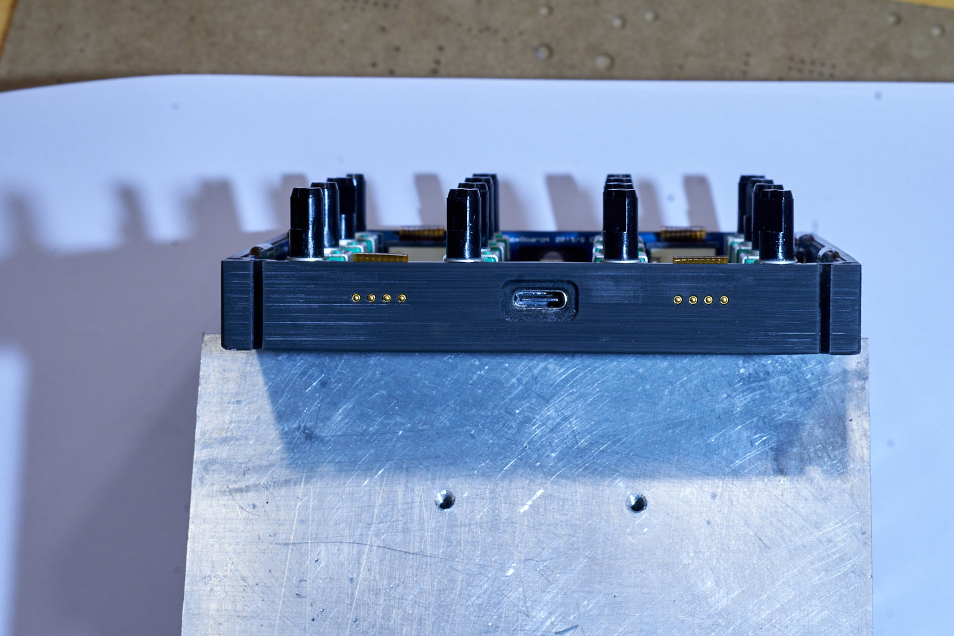
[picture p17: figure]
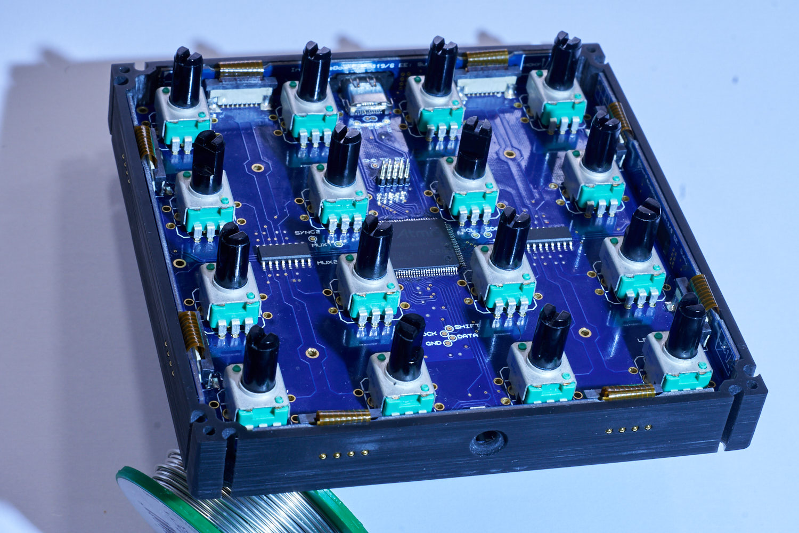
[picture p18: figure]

## Tápellátás

A készüléken USB-C aljzat található, melyen keresztül 5V feszültséget kap a hoszt számítógéptől. A termék áramfelvétele függ a csatlakoztatott kiegészítő modulok számától, az áramfelvétel az USB-C specifikációban feltüntetett 3A-ben van korlátozva.

A termékben akkumulátor vagy egyéb beépített energiaforrás nem található.

## Processzor

A termékben egy darab ATSAMD51N20A (http://ww1.microchip.com/downloads/en/DeviceDoc/60001507C.pdf) típusú Cortex®-M4-es Atmel/Microchip gyártmányú mikrokontroller található. A processzor 120MHz-es órajelen működik, melynek a PLL-eken keresztül történő előállításához egy 32.768kHz-es külső kerámia rezonátort haszál frekvencia referenciaként.

## USB kommunikáció

Az termék USB-C csatlakozón keresztül USB 2.0 Full Speed (12Mbps) kommunikációt folytat a hoszt számítógéppel.

## Egyéb nagysebességű perifériák és buszok

A termék négy irányban 3 Mbaud sebességű full-duplex UART interfésszel van ellátva, mely lehetővé teszi az egymáshoz csatlakoztatott modulok közötti adatáramlást.

A terméken WS2812C-2020 (https://www.tme.eu/Document/e9a11cb1285d7850e97c7bf4ed162c64/WS2812C-2020.pdf) típusú címezhető RGB LED-ek adnak visszajelzést a felhasználó számára. Egy készüléken 12-16 db LED kerül egy láncra fűzve. A 800kbps szimbólumsebességű NZR jelsorozatot egy 3.2Mbps sebességű SPI periféria állítja elő.

A terméken helyet kap egy Winbond W25Q16JVSSIQ (https://datasheet.lcsc.com/szlcsc/Winbond-Elec-W25Q16JVSSIQ_C82317.pdf) 16Mbit-es külső flash memória, mely QSPI interfésszel csatlakozik a processzorhoz, maximális órajele 133MHz.

## ESD Védelem

A termék kívülrűl érinthető, táp- és jelvezetékein SESRV05-4 (https://datasheet.lcsc.com/szlcsc/1812101631_SEMIWARE-SESRV05-4_C294963.pdf) típusú ESD védelemi áramkör végzi a tranziens elnyomást.

# PCB Specifikáció

## Main PCB

A termék processzora, a hozzá tartozó kiegészítő áramkörök és a felhasználói kezelőfelület egy 100mm*100mm-es 1.6mm vastagságú négyrétegű FR4 típusú nyomtatott huzalozású lemezen kap helyet.

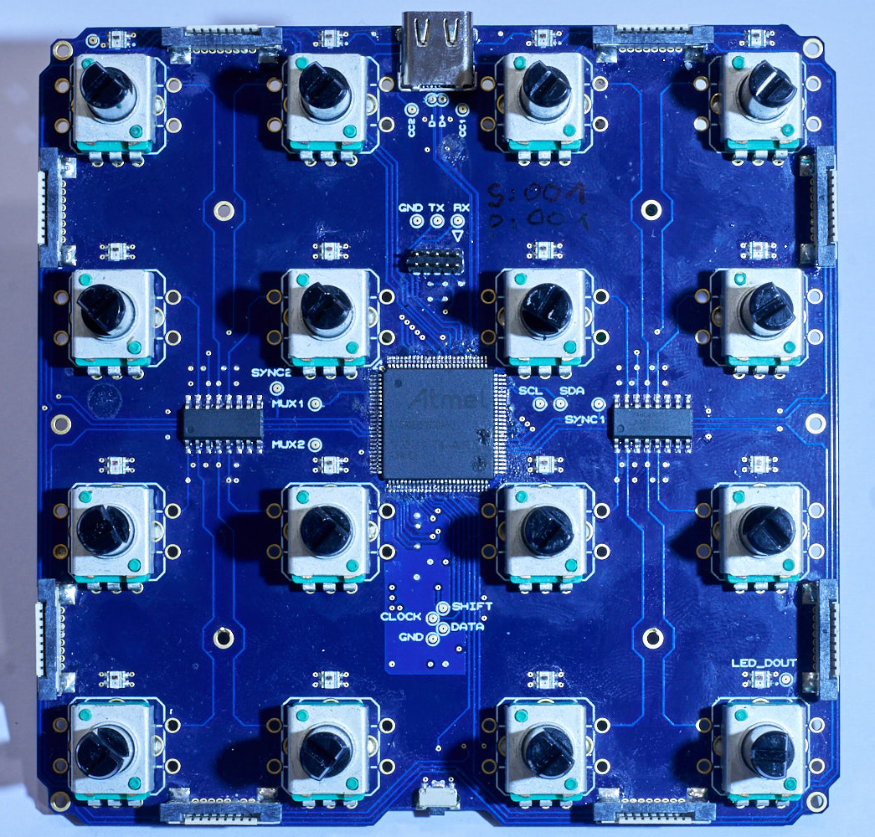
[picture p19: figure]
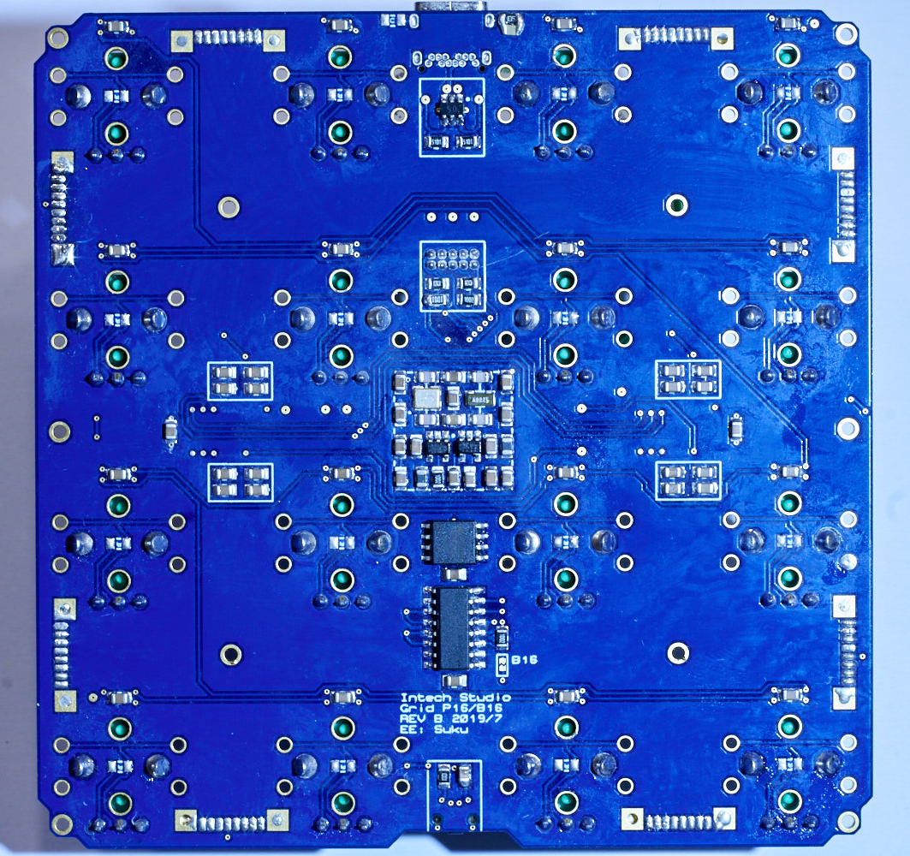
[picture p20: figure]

Réteg kiosztás

Copper Top | 18 um-- plating to 35um | Signal (UART, USB2.0… stb)
Dielectric | 0.11 mm (Er = 4.29)
Copper | 35 um | GND
Dielectric | 1.13 mm (Er = 3.96)
Copper | 35 um | +3V3_UI (Kezelőfelület tápja)
Dielectric | 0.11 mm (Er = 4.29)
Copper | 18 um-- plating to 35um | +5V (USB_VBUS)

A mikrokontrollert ellátó pozitív tápsín (+3V3_UC) a felső rézrétegen kap helyet a processzor körül és alatt.

## Interface PCB

Termék négy oldalán található csatlakozók, illetve az ahhoz tartozó védelmi és szakaszoló áramkörök egy-egy függőlegesen beszerelt interfaceboard-on helyezkednek el. A termékben található szerelt áramköri lemezek 1mm raszterű FFC szalagkábellel és csatlakozóval vannak összekötve.

Az interface board 96mm*12mm-es kétrétegű 1mm vastagságú FR4 típusú hordozón kerül kialakításra.

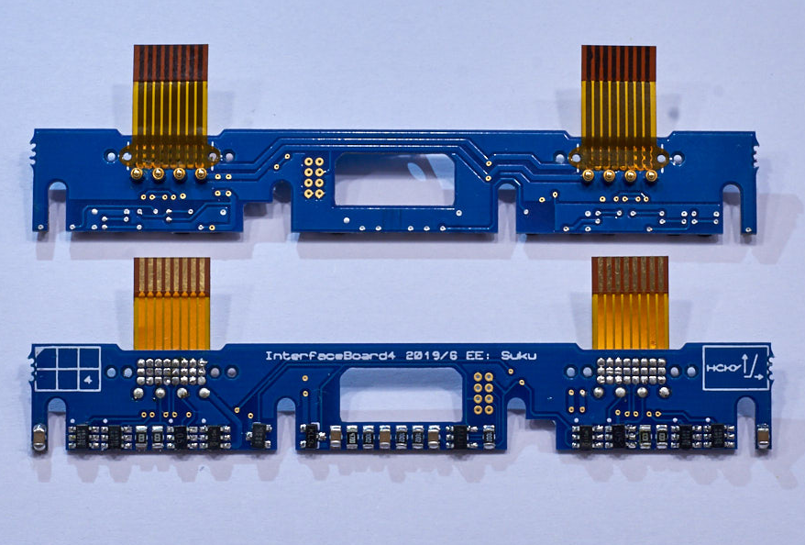
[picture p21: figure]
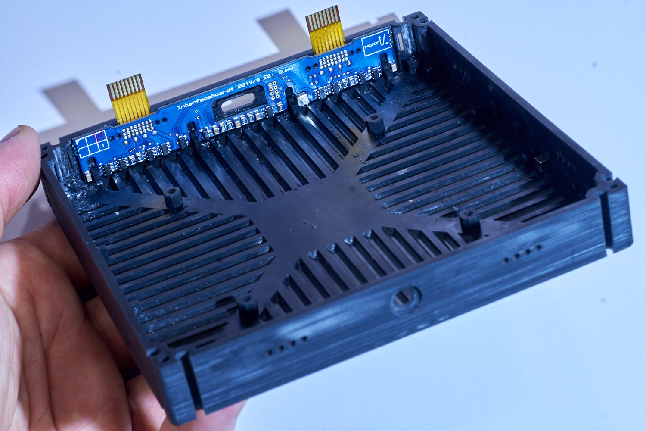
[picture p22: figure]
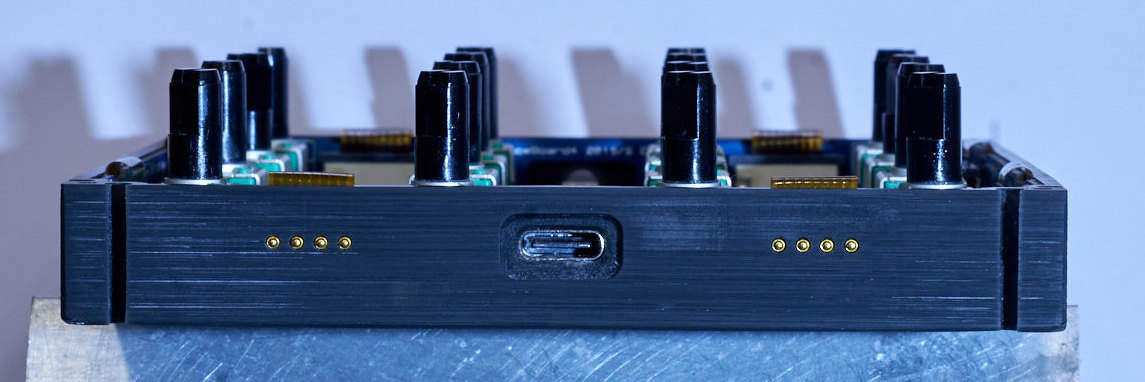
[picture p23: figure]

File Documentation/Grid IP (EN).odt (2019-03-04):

Intech Grid Specification

Top-level Design Overview

## Grid Modules

The Grid Modules are Human Interface Devices designed to provide an affirmative, tactile user experience, allowing creatives to interact with the computer more naturally and efficiently. Grid Modules are 4.2” wide, while user interface components are placed in a 1.05” raster layout. This allows multiple modules to create one seamless user interface. The modules can be connected in any order and orientation using a custom designed magnetic interface. Grid is designed to be portable, affordable and flexible, following the requirements set by the creative community.

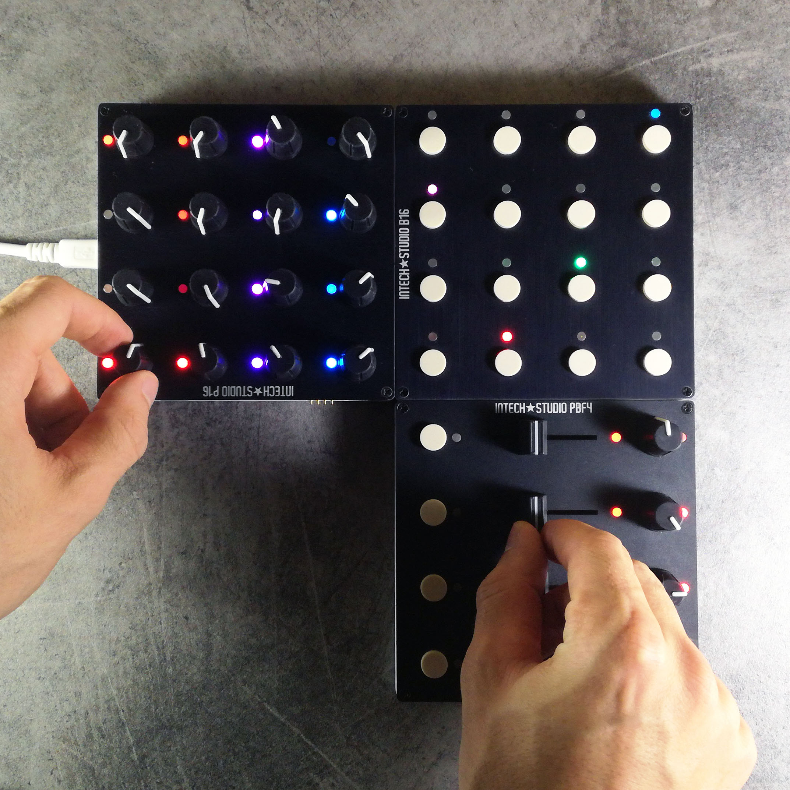
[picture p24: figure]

Figure 1: P16, B16 and PBF4 prototype modules in use.

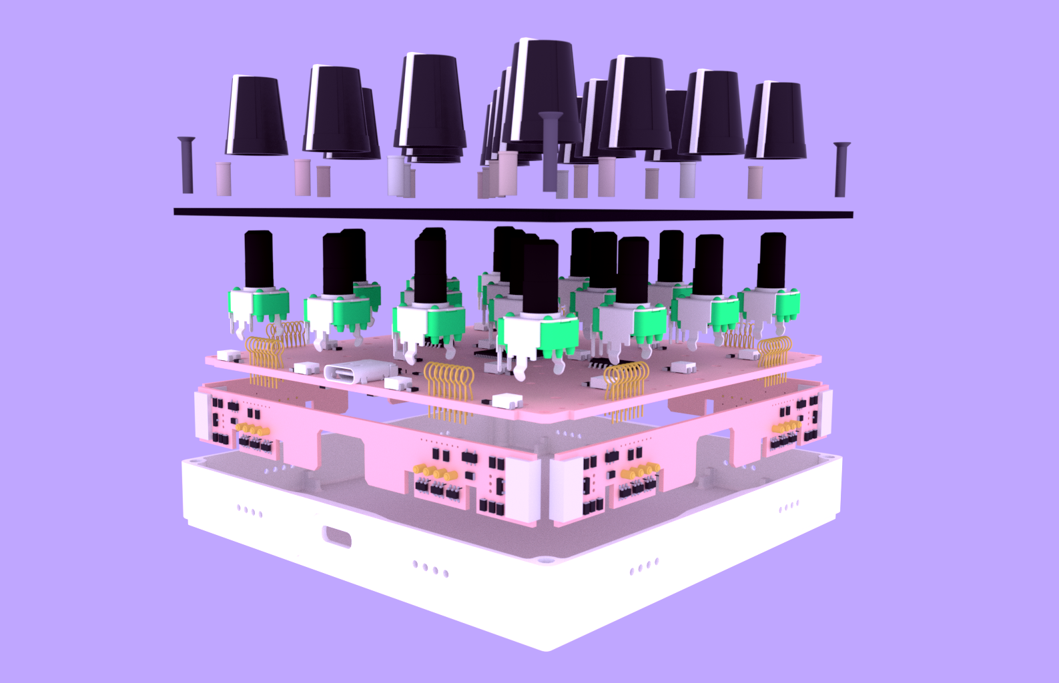
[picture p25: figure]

Figure 2: Assembly drawing of the P16 module.

The modules are designed to be compatible with any other modules that we release in the future, regardless of the user interface. The control surface can be extended as the users needs change.

The challenges in creating Grid ecosystem include:

- Meeting strict design tolerances to ensure reliable functionality
- Maintaining backwards compatibility with new module
- Optimizing the cost of production and logistics
- Building a scalable product ecosystem

## Grid Interface

The modules in the control surface connect to each other using the Grid Interface. Neodymium magnets are place in the corner of the modules, these allow the modules to snap together, making the control surface easy to reconfigure. Spring-loaded pogo pin connectors are installed on the sides of the modules, these provide power and data communication between the modules.


Figure 3: Custom manufactured spring-loaded pogo pin connector.

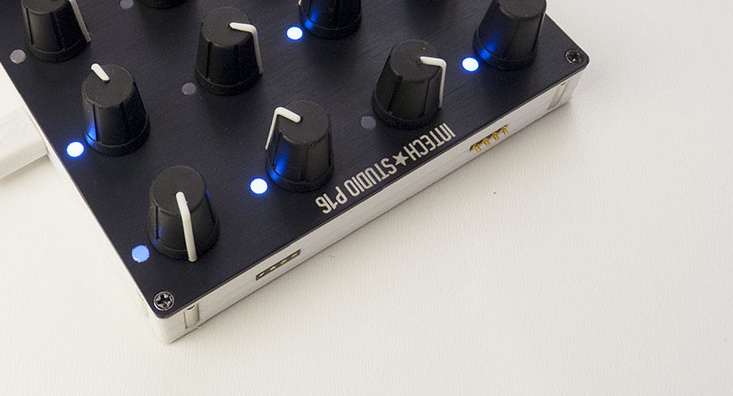
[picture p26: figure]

Figure 4: Pogo pins and magnets on the side of the P16 prototype.

This wired point-to-point data and power interface allows neighboring modules to communicate independently. The Grid Interface also provides two global data lines for timing critical signaling. On this port the modules can broadcast messages to communicate to every other module simultaneously.

The Grid interface is automatically disabled when there is no neighboring module connected. This eliminates the chance of accidentally short circuiting the power supply. The interface detects a connection by recognizing the specific magnetic field produced by the neighboring module. This allows the user to reconfigure the control surface during use.

The Grid control surface connects to a host device via a single USB C cable. The power provided by the host has to be distributed throughout the Grid. Up to 20 modules can be connected to the host using a single USB C cable. The control surface can be extended further by connecting a USB C phone charger as secondary power source to the Grid.

The challenges in creating Grid Interface include:

- Designing suitable pogo pin connectors meeting the bandwidth and current requirements
- Ensuring long term reliability of the product
- Ensuring repeatability in the production.

## Grid Protocol

The Grid Modules communicate using the Grid Protocol over the point-to-point network of full-duplex serial ports that run at 4Mbps. This is the primary data delivery network for the Grid.

The communication between the modules introduces inherent latency. This has to be low enough for the user to be unnoticeable, currently specified to be less than 1ms/link. The module farthest away from the USB Host will have the most round-trip latency, around 4-5ms in a typical configuration.

Two auxiliary channels are provided in the specification. These are half-duplex global data lines reserved for transmitting timing-critical messages, synchronization and global settings.

The challenges in creating such protocol include:

- Delivering all of the messages to every connected module in the control surface
- Implementing the network stack in a memory constrained embedded processor
- Achieving maximum possible data throughput while maintaining minimal latency
- Providing highly reliable error detection and error correction for every interface

## Technical Specification Summery


- Modular control surface
- Tactile user interface
- Full-color RGB LEDs
- High resolution inputs: 10 bit effective
- Aluminum front-panel
- Compact: 106mm x 106mm x 16mm
- 21 HP Eurorack compatible
- Light weight: 200g (7oz)
- USB C bus-powered device
- USB2.0 compliant (Audio Device Midi, CDC Serial, DFU)
- Compatible with Windows, Mac and Linux

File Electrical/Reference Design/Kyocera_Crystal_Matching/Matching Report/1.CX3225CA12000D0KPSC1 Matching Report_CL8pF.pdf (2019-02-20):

TO: Microchip Corporation | Report No． | UKY1C-C3-16833-00(43)N 1/4
| Date Issued

Dear Sirs,
We are pleased to submit a report on the above subject as follows:

Yours faithfully

Board name | SAME54 Xplained Pro kit
IC name | ATSAME54P20A
Specification | CX3225CA12000D0KPSC1
Specification NO. | --
Crystal unit type | CX3225CA
Frequency | 12000 kHz
Frequency tolerance | ±30 PPM
Temperature | -40～+85 ℃
Temperature characteristic | ±50 PPM
Equivalent series resistance | 200 Ω
Load capacitance | 8 pF
Drive level | 200 uW

Circuit examination history
2016.11.25 | First edition UKY1C-C3-16833-00(43)N

The reference about the above
KYOCERA Crystal Device Corporation | Marketing Division
5850 Higashine-koh , Higashine-shi , Yamagata 999-3701 | Tel:+81-237-43-5747 | Fax:+81-237-43-5651

Note:The characteristics of crystal oscillating circuits vary according to a circuit constant, installed condition,etc.
Before use,please conflem matching of the crystal unit with the crystal oscillator circuits.Please also note that the resuits of reviewing the circuits may not meet the characteristics of your product.
Crystal Units design section | Crystal oscillation circuit evaluation section
Approved by Checked by Approved by Checked by | | | | Prepared
T.Nitobe | - | A.Hisako | Y.Yuki | M.Tanigawa

25-Nov-16

## Crystal oscillation circuits report

○Measurement Circuit Diagram | SAME54 Xplained Pro kit
| IC：　 ATSAME54P20A
| Vcc：　 USB (V)
ATSAME54P20A | Xtal(XC301)： CX3225CA 12000kHz | CL= 8pF
XIN | XOUT
Cin(C303) | Xtal(XC301) | Cout(C302)

## ○Characteristics at Present Constants

CL= 8pF

Circuit Constants | Power Voltage (V) | Automatic Loop Control | Negative Resistance （Ω ） | Circuit load Capacitance （pF） | Frequency Deviation (PPM) | Drive Level （μ W） | 3rd Negative Resistance （Ω ）
Cin(C303) | Cout(C302)
12pF | 12pF | USB | Enabled | -3865 | 10.47 | -19.50 | 7 | -410
12pF | 12pF | USB | Disabled | -3864 | 13.02 | -32.17 | 270 | -420
・Negative ｒesistance
<Automatic loop control enabled>
The negative resistance for 12000kHz at the present circuit constants is -3865Ω , ｗhich is enough to assure stable operation of the circuits.
<Automatic loop control disabled>
The negative resistance for 12000kHz at the present circuit constants is -3864Ω , ｗhich is enough to assure stable operation of the circuits.
・Circuit load capacitance and Frequency tolerance
<Automatic loop control enabled>
The load capacitance of the oscillator circuit is 10.47pF with a frequency deviation of -19.50PPM. This is based on the fact that this quartz crystal has a frequency deviation of +/-0
by using a load capacitance of 8pF.
<Automatic loop control disabled>
The load capacitance of the oscillator circuit is 13.02pF with a frequency deviation of -32.17PPM. This is based on the fact that this quartz crystal has a frequency deviation of +/-0
by using a load capacitance of 8pF.
・Drive level
<Automatic loop control enabled>
The drive level of the oscillation circuit is 7μ W.
When a quartz crystal unit with 58.76Ω equivalent series resistance and 64.89Ω load resonance resistance is used. This is a good value without the possibility to cause trouble.
<Automatic loop control disabled>
The drive level of the oscillation circuit is 270μ W.
When a quartz crystal unit with 58.76Ω equivalent series resistance and 63.67Ω load resonance resistance is used. This value is large. This may become the problem.
・3rd Over tone Negative resistance
<Automatic loop control enabled>
The 3rd over tone (= 36000kHz) negative resistance of the oscillation circuit is -410Ω . The value is guaranteed to stable oscillation in the circuit.
<Automatic loop control disabled>
The 3rd over tone (= 36000kHz) negative resistance of the oscillation circuit is -420Ω .
The value is guaranteed to stable oscillation in the circuit.
・Conclusion
Constant and Load Capacitance change is needed because center frequency is at minus side and drive level with automatic loop control disabled is large.
Date Issued | Circuit Diagram | Report No.
Present constants | UKY1C-C3-16833-00(43)N | 2/4
KYOCERA Crystal Device Corporation | 2016.11.25
Measurement Item | Instrument
Frequency | Anritsu MS2661C Spectrum Analyzer
Negative Resistance Anritsu MS2661C Spectrum Analyzer
| Tektronix Digital Oscilloscope TDS5052B Tektronix AC Current Probe P6022 Drive Level

Measurement Point

EXT2 pin 8 (PB15)

○Measurement Circuit Diagram | SAME54 Xplained Pro kit
| IC：　 ATSAME54P20A
| Vcc：　 USB (V)
ATSAME54P20A | Xtal(XC301)： CX3225CA 12000kHz | CL= 8pF
XIN | XOUT
Cin(C303) | Xtal(XC301) | Cout(C302)

## ○Characteristics at Recommended Constants

CL= 8pF

Circuit Constants | Power Voltage (V) | Automatic Loop Control | Negative Resistance （Ω ） | Circuit load Capacitance （pF） | Frequency Deviation (PPM) | Drive Level （μ W） | 3rd Negative Resistance （Ω ）
Cin(C303) | Cout(C302)
5pF | 5pF | USB | Enabled | -7268 | 7.16 | +9.50 | 4.4 | -920
5pF | 5pF | USB | Disabled | -7266 | 8.90 | -8.25 | 192 | -920
・Negative ｒesistance
<Automatic loop control enabled>
The negative resistance for 12000kHz at the present circuit constants is -7268Ω , ｗhich is enough to assure stable operation of the circuits.
<Automatic loop control disabled>
The negative resistance for 12000kHz at the present circuit constants is -7266Ω , ｗhich is enough to assure stable operation of the circuits.
・Circuit load capacitance and Frequency tolerance
<Automatic loop control enabled>
The load capacitance of the oscillator circuit is 7.16pF with a frequency deviation of +9.50PPM. This is based on the fact that this quartz crystal has a frequency deviation of +/-0
by using a load capacitance of 8pF.
<Automatic loop control disabled>
The load capacitance of the oscillator circuit is 8.90pF with a frequency deviation of -8.25PPM. This is based on the fact that this quartz crystal has a frequency deviation of +/-0
by using a load capacitance of 8pF.
・Drive level
<Automatic loop control enabled>
The drive level of the oscillation circuit is 4.4μ W.
When a quartz crystal unit with 58.76Ω equivalent series resistance and 67.84Ω load resonance resistance is used. This is a good value without the possibility to cause trouble.
<Automatic loop control disabled>
The drive level of the oscillation circuit is 192μ W.
When a quartz crystal unit with 58.76Ω equivalent series resistance and 66.01Ω load resonance resistance is used. This is a good value without the possibility to cause trouble.
・3rd Over tone Negative resistance
<Automatic loop control enabled>
The 3rd over tone (= 36000kHz) negative resistance of the oscillation circuit is -920Ω . The value is guaranteed to stable oscillation in the circuit.
<Automatic loop control disabled>
The 3rd over tone (= 36000kHz) negative resistance of the oscillation circuit is -920Ω . The value is guaranteed to stable oscillation in the circuit.
・Conclusion
We recommend use of the product at the present constants.
However, please check whether it is satisfactory enough in your company.
Recommended constants | UKY1C-C3-16833-00(43)N | 3/4
Measurement Item | Instrument
Frequency | Anritsu MS2661C Spectrum Analyzer
Negative Resistance Anritsu MS2661C Spectrum Analyzer
Drive Level | Tektronix Digital Oscilloscope TDS5052B
Tektronix AC Current Probe P6022

KYOCERA Crystal Device Corporation 2016.11.25

Measurement Point

EXT2 pin 8 (PB15)

## ○Temperature Characteristics at Recommended Constants

Circuit Constants | Power Voltage (V) | Temperature (℃) | Automatic Loop Control | Negative Resistance （Ω ） | Drive Level （μ W） | 3rd Negative Resistance （Ω ）
Cin(C303) | Cout(C302)
5pF | 5pF | USB | -40 | Enabled | -7268 | 3 | -910
5pF | 5pF | USB | -40 | Disabled | -7266 | 198 | -910
5pF | 5pF | USB | +85 | Enabled | -7168 | 3 | -900
5pF | 5pF | USB | +85 | Disabled | -7166 | 189 | -900

The results of testing the mounted board we borrowed from you this time are as described above. Please also check and review them on your side before use.

KYOCERA Crystal Device Corporation | 2016.11.25 | Recommended constants | UKY1C-C3-16833-00(43)N | 4/4

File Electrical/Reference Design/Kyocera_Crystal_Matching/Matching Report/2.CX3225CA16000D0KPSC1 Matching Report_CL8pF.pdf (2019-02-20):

TO: Microchip Corporation | Report No． | UKY1C-C3-16834-00(43)N 1/2
| Date Issued

Dear Sirs,
We are pleased to submit a report on the above subject as follows:

Yours faithfully

Board name | SAME54 Xplained Pro kit
IC name | ATSAME54P20A
Specification | CX3225CA16000D0KPSC1
Specification NO. | --
Crystal unit type | CX3225CA
Frequency | 16000 kHz
Frequency tolerance | ±30 PPM
Temperature | -40～+85 ℃
Temperature characteristic | ±50 PPM
Equivalent series resistance | 100 Ω
Load capacitance | 8 pF
Drive level | 200 uW

Circuit examination history
2016.11.25 | First edition UKY1C-C3-16834-00(43)N

The reference about the above
KYOCERA Crystal Device Corporation | Marketing Division
5850 Higashine-koh , Higashine-shi , Yamagata 999-3701 | Tel:+81-237-43-5747 | Fax:+81-237-43-5651

Note:The characteristics of crystal oscillating circuits vary according to a circuit constant, installed condition,etc.
Before use,please conflem matching of the crystal unit with the crystal oscillator circuits.Please also note that the resuits of reviewing the circuits may not meet the characteristics of your product.
Crystal Units design section | Crystal oscillation circuit evaluation section
Approved by Checked by Approved by Checked by | | | | Prepared
T.Nitobe | - | A.Hisako | Y.Yuki | M.Tanigawa

25-Nov-16

## Crystal oscillation circuits report

○Measurement Circuit Diagram | SAME54 Xplained Pro kit
| IC：　 ATSAME54P20A
| Vcc：　 USB (V)
ATSAME54P20A | Xtal(XC301)： CX3225CA 16000kHz | CL= 8pF
XIN | XOUT
Cin(C303) | Xtal(XC301) | Cout(C302)

## ○Characteristics at Recommended Constants

CL= 8pF

Circuit Constants | Power Voltage (V) | Automatic Loop Control | Negative Resistance （Ω ） | Circuit load Capacitance （pF） | Frequency Deviation (PPM) | Drive Level （μ W） | 3rd Negative Resistance （Ω ）
Cin(C303) | Cout(C302)
4pF | 4pF | USB | Enabled | -5230 | 6.68 | +17.75 | 0.3 | -610
4pF | 4pF | USB | Disabled | -5229 | 8.87 | -9.00 | 125 | -610
・Negative ｒesistance
<Automatic loop control enabled>
The negative resistance for 16000kHz at the present circuit constants is -5230Ω , ｗhich is enough to assure stable operation of the circuits.
<Automatic loop control disabled>
The negative resistance for 16000kHz at the present circuit constants is -5229Ω , ｗhich is enough to assure stable operation of the circuits.
・Circuit load capacitance and Frequency tolerance
<Automatic loop control enabled>
The load capacitance of the oscillator circuit is 6.68pF with a frequency deviation of +17.75PPM. This is based on the fact that this quartz crystal has a frequency deviation of +/-0
by using a load capacitance of 8pF.
<Automatic loop control disabled>
The load capacitance of the oscillator circuit is 8.87pF with a frequency deviation of -9.00PPM. This is based on the fact that this quartz crystal has a frequency deviation of +/-0
by using a load capacitance of 8pF.
・Drive level
<Automatic loop control enabled>
The drive level of the oscillation circuit is 0.3μ W.
When a quartz crystal unit with 24.32Ω equivalent series resistance and 29.97Ω load resonance resistance is used. This is a good value without the possibility to cause trouble.
<Automatic loop control disabled>
The drive level of the oscillation circuit is 125μ W.
When a quartz crystal unit with 24.32Ω equivalent series resistance and 28.52Ω load resonance resistance is used. This is a good value without the possibility to cause trouble.
・3rd Over tone Negative resistance
<Automatic loop control enabled>
The 3rd over tone (= 48000kHz) negative resistance of the oscillation circuit is -610Ω . The value is guaranteed to stable oscillation in the circuit.
<Automatic loop control disabled>
The 3rd over tone (= 48000kHz) negative resistance of the oscillation circuit is -610Ω . The value is guaranteed to stable oscillation in the circuit.
・Conclusion
We recommend use of the product at the present constants.
However, please check whether it is satisfactory enough in your company.

The results of testing the mounted board we borrowed from you this time are as described above.
Please also check and review them on your side before use.
| Date Issued | Circuit Diagram | Report No.
KYOCERA Crystal Device Corporation | 2016.11.25 | Recommended constants | UKY1C-C3-16834-00(43)N | 2/2

Tektronix AC Current Probe P6022

Measurement Item | Instrument
Frequency | Anritsu MS2661C Spectrum Analyzer
Negative Resistance Anritsu MS2661C Spectrum Analyzer
Drive Level | Tektronix Digital Oscilloscope TDS5052B

Measurement Point

EXT2 pin 8 (PB15)

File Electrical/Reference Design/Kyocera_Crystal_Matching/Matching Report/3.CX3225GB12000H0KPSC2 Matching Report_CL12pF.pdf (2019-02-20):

TO: Microchip Corporation | Report No． | UKY1C-C3-16832-00(43)N 1/4
| Date Issued

Dear Sirs,
We are pleased to submit a report on the above subject as follows:

Yours faithfully

Board name | SAME54 Xplained Pro kit
IC name | ATSAME54P20A
Specification | CX3225GB12000H0KPSC1
Specification NO. | --
Crystal unit type | CX3225GB
Frequency | 12000 kHz
Frequency tolerance | ±30 PPM
Temperature | -40～+85 ℃
Temperature characteristic | ±50 PPM
Equivalent series resistance | 150 Ω
Load capacitance | 12 pF
Drive level | 100 uW

Circuit examination history
2016.11.25 | First edition UKY1C-C3-16832-00(43)N

The reference about the above
KYOCERA Crystal Device Corporation | Marketing Division
5850 Higashine-koh , Higashine-shi , Yamagata 999-3701 | Tel:+81-237-43-5747 | Fax:+81-237-43-5651

Note:The characteristics of crystal oscillating circuits vary according to a circuit constant, installed condition,etc.
Before use,please conflem matching of the crystal unit with the crystal oscillator circuits.Please also note that the resuits of reviewing the circuits may not meet the characteristics of your product.
Crystal Units design section | Crystal oscillation circuit evaluation section
Approved by Checked by Approved by Checked by | | | | Prepared
T.Nitobe | - | A.Hisako | Y.Yuki | M.Tanigawa

25-Nov-16

## Crystal oscillation circuits report

○Measurement Circuit Diagram | SAME54 Xplained Pro kit
| IC：　 ATSAME54P20A
| Vcc：　 USB (V)
ATSAME54P20A | ： CX3225GB 12000kHz | CL= 12pF
XIN | XOUT
Cin(C303) | Xtal(XC301) | Cout(C302)

## ○Characteristics at Present Constants

CL= 12pF

Circuit Constants | Power Voltage (V) | Automatic Loop Control | Negative Resistance （Ω ） | Circuit load Capacitance （pF） | Frequency Deviation (PPM) | Drive Level （μ W） | 3rd Negative Resistance （Ω ）
Cin(C303) | Cout(C302)
12pF | 12pF | USB | Enabled | -3865 | 10.45 | +8.33 | 7 | -410
12pF | 12pF | USB | Disabled | -3864 | 12.99 | -4.33 | 270 | -420
・Negative ｒesistance
<Automatic loop control enabled>
The negative resistance for 12000kHz at the present circuit constants is -3865Ω , ｗhich is enough to assure stable operation of the circuits.
<Automatic loop control disabled>
The negative resistance for 12000kHz at the present circuit constants is -3864Ω , ｗhich is enough to assure stable operation of the circuits.
・Circuit load capacitance and Frequency tolerance
<Automatic loop control enabled>
The load capacitance of the oscillator circuit is 10.45pF with a frequency deviation of +8.33PPM. This is based on the fact that this quartz crystal has a frequency deviation of +/-0
by using a load capacitance of 12pF.
<Automatic loop control disabled>
The load capacitance of the oscillator circuit is 12.99pF with a frequency deviation of -4.33PPM. This is based on the fact that this quartz crystal has a frequency deviation of +/-0
by using a load capacitance of 12pF.
・Drive level
<Automatic loop control enabled>
The drive level of the oscillation circuit is 7μ W.
When a quartz crystal unit with 58.76Ω equivalent series resistance and 64.91Ω load resonance resistance is used. This is a good value without the possibility to cause trouble.
<Automatic loop control disabled>
The drive level of the oscillation circuit is 270μ W.
When a quartz crystal unit with 58.76Ω equivalent series resistance and 63.68Ω load resonance resistance is used. This value is large. This may become the problem.
・3rd Over tone Negative resistance
<Automatic loop control enabled>
The 3rd over tone (= 36000kHz) negative resistance of the oscillation circuit is -410Ω . The value is guaranteed to stable oscillation in the circuit.
<Automatic loop control disabled>
The 3rd over tone (= 36000kHz) negative resistance of the oscillation circuit is -420Ω .
The value is guaranteed to stable oscillation in the circuit.
・Conclusion
Constant and Load Capacitance change is needed because drive level with automatic loop control disabled is large.
| Date Issued | Circuit Diagram | Report No.
KYOCERA Crystal Device Corporation | 2016.11.25 | Present constants | UKY1C-C3-16832-00(43)N | 2/4

Tektronix AC Current Probe P6022

Measurement Item | Instrument
Frequency | Anritsu MS2661C Spectrum Analyzer
Negative Resistance Anritsu MS2661C Spectrum Analyzer
Drive Level | Tektronix Digital Oscilloscope TDS5052B

Measurement Point

EXT2 pin 8 (PB15)

○Measurement Circuit Diagram | SAME54 Xplained Pro kit
| IC：　 ATSAME54P20A
| Vcc：　 USB (V)
ATSAME54P20A | ： CX3225GB 12000kHz | CL= 12pF
XIN | XOUT
Cin(C303) | Xtal(XC301) | Cout(C302)

## ○Characteristics at Recommended Constants

CL= 12pF

Circuit Constants | Power Voltage (V) | Automatic Loop Control | Negative Resistance （Ω ） | Circuit load Capacitance （pF） | Frequency Deviation (PPM) | Drive Level （μ W） | 3rd Negative Resistance （Ω ）
Rd | Cin(C303) | Cout(C302)
1500Ω | 15pF | 15pF | USB | Enabled | -1764 | 12.04 | -0.17 | 9 | -20
1500Ω | 15pF | 15pF | USB | Disabled | -1765 | 11.14 | +4.33 | 95 | -20
・Negative ｒesistance
<Automatic loop control enabled>
The negative resistance for 12000kHz at the present circuit constants is -1764Ω , ｗhich is enough to assure stable operation of the circuits.
<Automatic loop control disabled>
The negative resistance for 12000kHz at the present circuit constants is -1765Ω , ｗhich is enough to assure stable operation of the circuits.
・Circuit load capacitance and Frequency tolerance
<Automatic loop control enabled>
The load capacitance of the oscillator circuit is 12.04pF with a frequency deviation of -0.17PPM. This is based on the fact that this quartz crystal has a frequency deviation of +/-0
by using a load capacitance of 12pF.
<Automatic loop control disabled>
The load capacitance of the oscillator circuit is 11.14pF with a frequency deviation of +4.33PPM. This is based on the fact that this quartz crystal has a frequency deviation of +/-0
by using a load capacitance of 12pF.
・Drive level
<Automatic loop control enabled>
The drive level of the oscillation circuit is 9μ W.
When a quartz crystal unit with 58.76Ω equivalent series resistance and 64.08Ω load resonance resistance is used. This is a good value without the possibility to cause trouble.
<Automatic loop control disabled>
The drive level of the oscillation circuit is 95μ W.
When a quartz crystal unit with 58.76Ω equivalent series resistance and 64.52Ω load resonance resistance is used. This value is large. This may become the problem.
・3rd Over tone Negative resistance
<Automatic loop control enabled>
The 3rd over tone (= 36000kHz) negative resistance of the oscillation circuit is -20Ω . The value is guaranteed to stable oscillation in the circuit.
<Automatic loop control disabled>
The 3rd over tone (= 36000kHz) negative resistance of the oscillation circuit is -20Ω . The value is guaranteed to stable oscillation in the circuit.
・Conclusion
We recommend use of the product at the present constants.
However, please check whether it is satisfactory enough in your company.
KYOCERA Crystal Device Corporation | 2016.11.25 | Recommended constants | UKY1C-C3-16832-00(43)N | 3/4

Tektronix AC Current Probe P6022

Measurement Item | Instrument
Frequency | Anritsu MS2661C Spectrum Analyzer
Negative Resistance Anritsu MS2661C Spectrum Analyzer
Drive Level | Tektronix Digital Oscilloscope TDS5052B

Measurement Point

EXT2 pin 8 (PB15)

Rd

## ○Temperature Characteristics at Recommended Constants

Circuit Constants | Power Voltage (V) | Temperature (℃) | Automatic Loop Control | Negative Resistance （Ω ） | Drive Level （μ W） | 3rd Negative Resistance （Ω ）
Rd | Cin(C303) | Cout(C302)
1500Ω | 15pF | 15pF | USB | -40 | Enabled | -1764 | 9 | -20
1500Ω | 15pF | 15pF | USB | -40 | Disabled | -1764 | 93 | -20
1500Ω | 15pF | 15pF | USB | +85 | Enabled | -1665 | 12 | -20
1500Ω | 15pF | 15pF | USB | +85 | Disabled | -1665 | 93 | -20

The results of testing the mounted board we borrowed from you this time are as described above. Please also check and review them on your side before use.

Recommended constants | UKY1C-C3-16832-00(43)N | 4/4
KYOCERA Crystal Device Corporation | 2016.11.25

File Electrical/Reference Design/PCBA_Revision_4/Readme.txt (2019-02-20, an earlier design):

Filelist:
SAME54_Xplained_Pro_layer_plots_release_rev4.pdf : PCB Layer Plots
BOM\Bill of Materials Print- SAME54_Xplained_Pro_release_rev4.xls : BOM, fitted components
ExportSTEP\SAME54_Xplained_Pro_release_rev4.step : 3D Model of PCBA
NC Drill\SAME54_Xplained_Pro_release_rev4.drl : Drill files, gerber
NC Drill\SAME54_Xplained_Pro_release_rev4.drr : Drill Files Report
Pick Place\Pick Place for SAME54_Xplained_Pro_release_rev4.txt : Pick and Place file, component placement
Test Points\Assembly Testpoint Report for SAME54_Xplained_Pro_release_rev4.txt : Assembly Testpoint report, txt
Test Points\Assembly Testpoint Report for SAME54_Xplained_Pro_release_rev4.csv : Assembly Testpoint report, csv
NC Drill\SAME54_Xplained_Pro_-SlotHoles_release_rev4.txt : Drill files, ASCII-SlotHoles
NC Drill\SAME54_Xplained_Pro_-RoundHoles_release_rev4.txt : Drill files, ASCII-RoundHoles
SAME54_Xplained_Pro_design_documentation_release_rev4.pdf : Design Documentation with Bom
Gerber\SAME54_Xplained_Pro_release_rev4.GP1 : Gerber files for GND
Gerber\SAME54_Xplained_Pro_release_rev4.GP2 : Gerber files for POWER
Gerber\SAME54_Xplained_Pro_release_rev4.GM1 : Gerber files for Board (M1)
Gerber\SAME54_Xplained_Pro_release_rev4.GBO : Gerber files for Bottom Overlay
Gerber\SAME54_Xplained_Pro_release_rev4.GBL : Gerber files for Bottom Layer LF-signals
Gerber\SAME54_Xplained_Pro_release_rev4.GBS : Gerber files for Bottom Solder
Gerber\SAME54_Xplained_Pro_release_rev4.GBP : Gerber files for Bottom Paste
Gerber\SAME54_Xplained_Pro_release_rev4.GTP : Gerber files for Top Paste
Gerber\SAME54_Xplained_Pro_release_rev4.GTS : Gerber files for Top Solder
Gerber\SAME54_Xplained_Pro_release_rev4.GTL : Gerber files for Top Layer LF-signals
Gerber\SAME54_Xplained_Pro_release_rev4.GTO : Gerber files for Top Overlay
NC Drill\SAME54_Xplained_Pro_release_rev4.LDP : Layer Pairs Definition

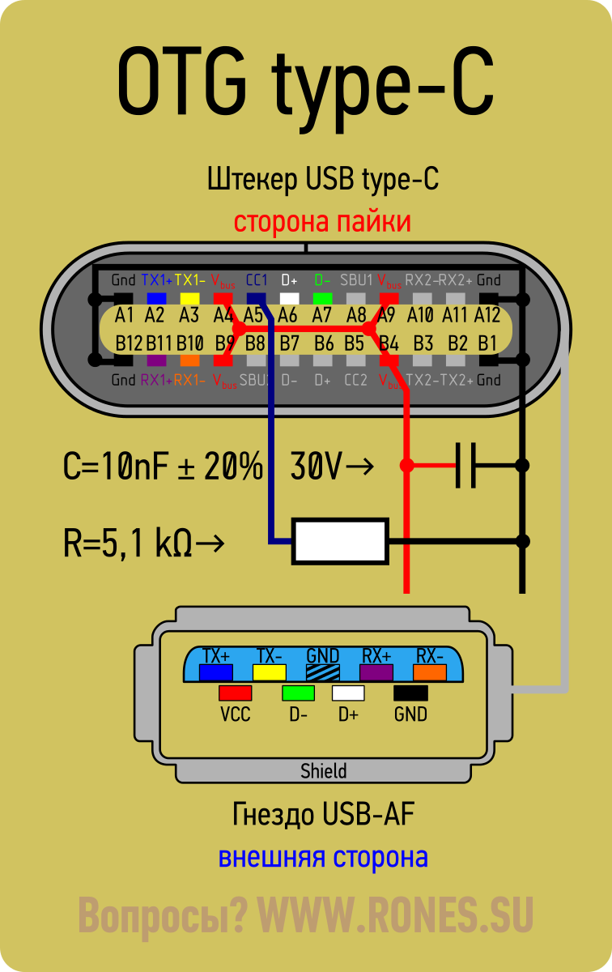
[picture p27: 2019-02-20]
Electrical/Knowledge/Type-C OTG Pinout.png

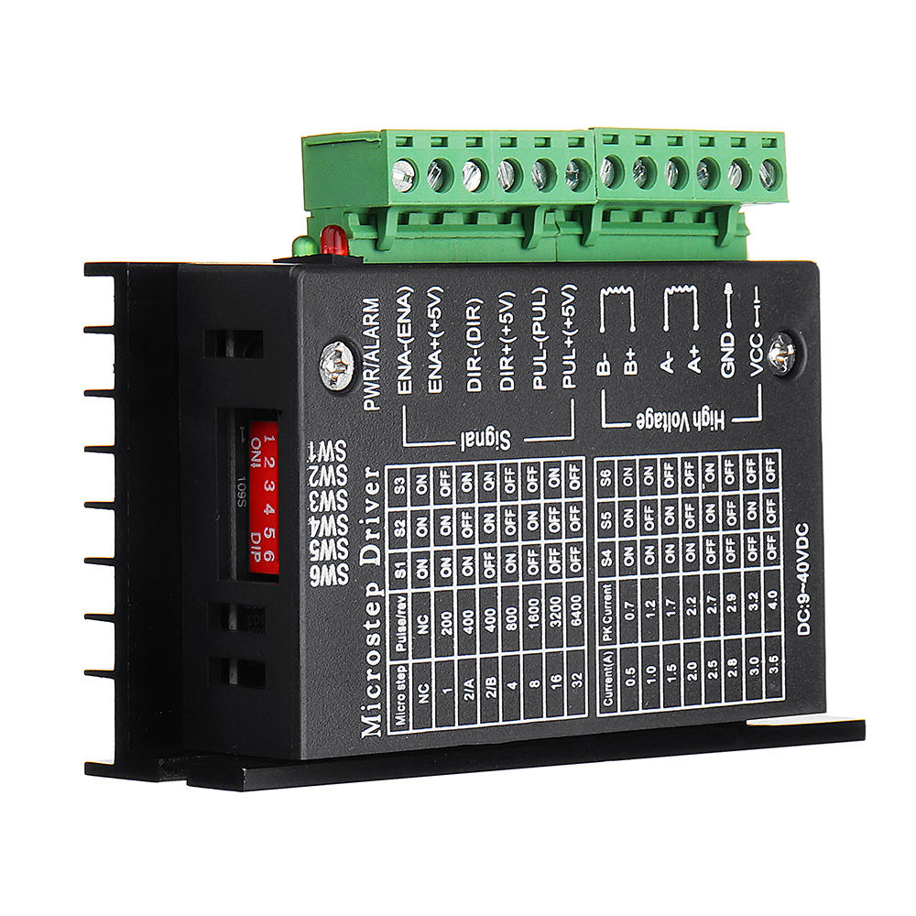
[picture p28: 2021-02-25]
Manufacturing/CNC/Electronics/3c6c15f7-b77c-48b7-af1c-c30efe6068fb.jpg

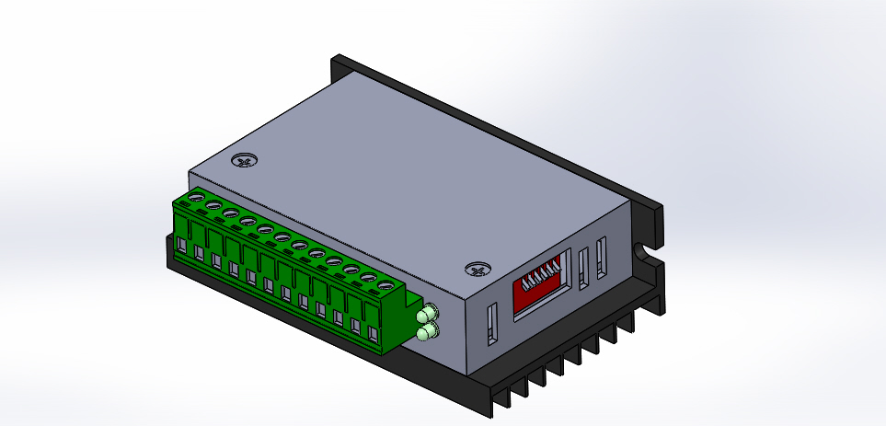
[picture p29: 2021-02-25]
Manufacturing/CNC/Electronics/Driver-3.5A.JPG

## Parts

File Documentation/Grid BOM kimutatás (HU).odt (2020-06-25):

Intech Studio

Grid BOM kimutatás és tervezett

változtatások a következő 12 hónapban.

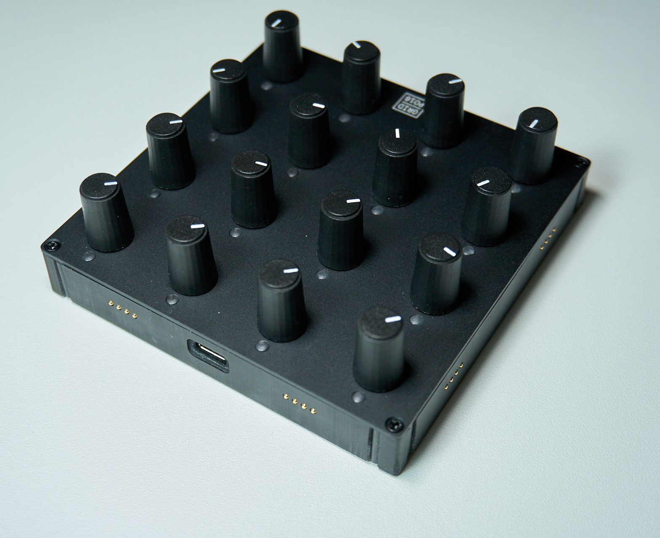
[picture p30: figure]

# Bevezetés

A dokumentum a PO16 típusú termékünk jelenlegi (2020/Q2) előállítási költségét mutatja be részletesen. Terveink szerint a következő 12 hónap DFM/BOM optimalizációs törekvéseink eredményeként a mostani 69 USD előállítási költség lemegy 54 USD-ra.

Az előállítási költségek csökkenése és az Editor kiadását követő áremelés hatására a Gross Margin 30,8 %-ról 50,5%-ra emelkedik majd a PO16 típus esetén.

Előállítási költségek (összefoglaló)

# Canvas [7,62 USD]

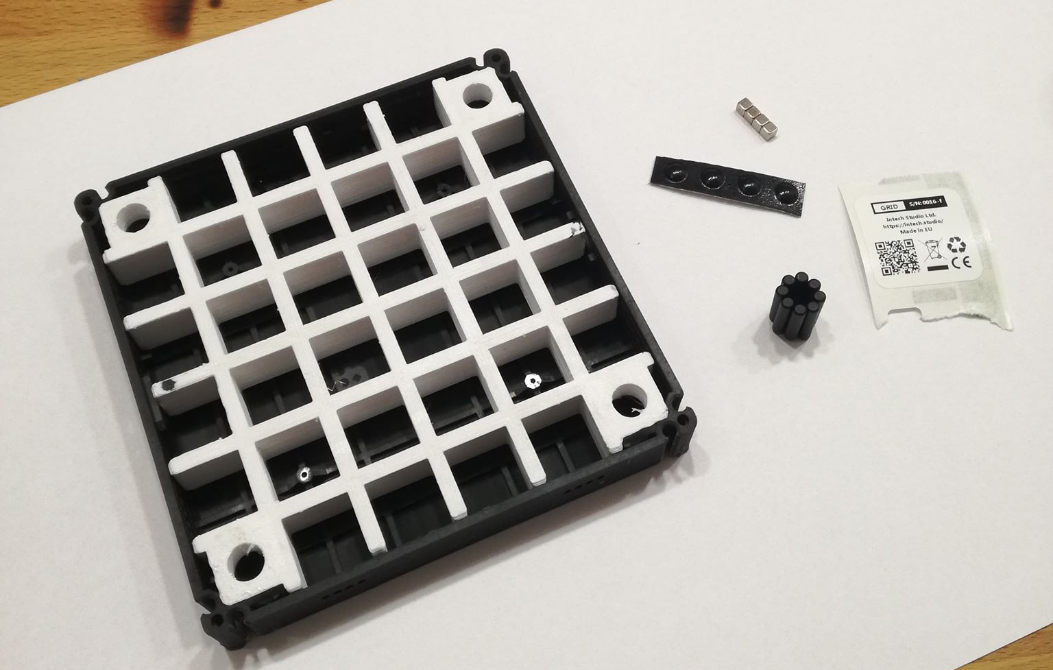
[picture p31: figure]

Az összes típusnál közös műanyag készülékház, és a hozzá tartozó kiegészítő alkatrészek alkotják a Canvas részegységet. A műanyag alkatrész házon belül MSLA 3D nyomtatással készül, a kétféle mágnest egy magyar- és egy kínai beszállítótól szerezzük be. Ebben a részegységben a legnagyobb költség a 3D nyomtatás alapanyagaként használt műgyanta ára, és a hozzá kapcsoló manuális utómunka költsége.

Típus | Beszállító | Darabszám | Darabár [USD] | Ár [USD]
Magnet 3x15mm | NingBu Riseng | 8 | 0.17 | 1.34
Magnet C-3N52 | Magnetplanet | 4 | 0.13 | 0.52
Sticker | Dymobolt | 1 | 0.05 | 0.05
Foot | Mouser | 4 | 0.07 | 0.3
Resin | 3D Prima | 0.04 | 64.9 | 2.27
Print Time | Intech Studio | 2.2 | 0 | 0
Routing | Intech Studio (Manual) | 0.15 | 3.3 | 0.5
Cleaning | Intech Studio (Manual) | 0.15 | 3.3 | 0.5
Magnet/Interface Gluing | Intech Studio (Manual) | 0.25 | 3.3 | 0.83
Testing | Intech Studio (Manual) | 0.2 | 3.3 | 0.66
Motherboard Installation | Intech Studio (Manual) | 0.2 | 3.3 | 0.66

Ragasztás, tisztítás

és tesztelés

Műgyanta

# Interface [12,19 USD]

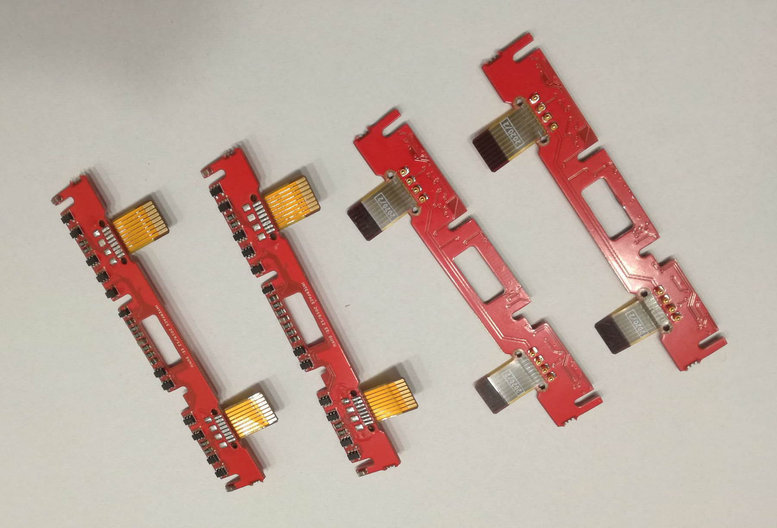
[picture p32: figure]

A modulok négy oldali csatlakozását biztosító Interface részegység jelenleg kézi összeszereléssel készül, 2020 júliusától azonban JLCPCB nevű partnerünk végzi majd az összeszerelését. Várhatóan modulonként 1,5 USD költségcsökkenést eredményez majd az átállás. További javulást az alkatrészek nagyobb tételben történő beszerzése jelent majd, főként a pogo pin rugós csatlakozó árát kell optimalizálni, hiszen ebből 32db kell egy modulba.

Típus | Beszállító | Darabszám | Darabár [USD] | Ár [USD]
LMV321 | LCSC | 8 | 0.06 | 0.46
470R | LCSC | 20 | 0.02 | 0.30
74HC1G66GV | LCSC | 16 | 0.04 | 0.63
WST2011 | LCSC | 8 | 0.11 | 0.87
HALL 39E | LCSC | 4 | 0.17 | 0.70
SESRV05-4 | LCSC | 8 | 0.04 | 0.32
10k | LCSC | 12 | 0.02 | 0.18
BAT54C | LCSC | 4 | 0.02 | 0.07
10u | LCSC | 4 | 0.02 | 0.06
100n | LCSC | 8 | 0.02 | 0.12
1u | LCSC | 8 | 0.02 | 0.12
FFC | PCBWAY | 8 | 0.18 | 1.40
POGO | CFE | 32 | 0.11 | 3.52
PCB | JLCPCB | 1 | 0.64 | 0.64
SMTA | Intech Studio (Manual) | 0.5 | 3.30 | 1.65
THTA | Intech Studio (Manual) | 0.25 | 3.30 | 0.83
TESTING | Intech Studio (Manual) | 0.1 | 3.30 | 0.33

Pogo Pin

Manuális
összeszerelés

# Motherboard [15,06 USD]

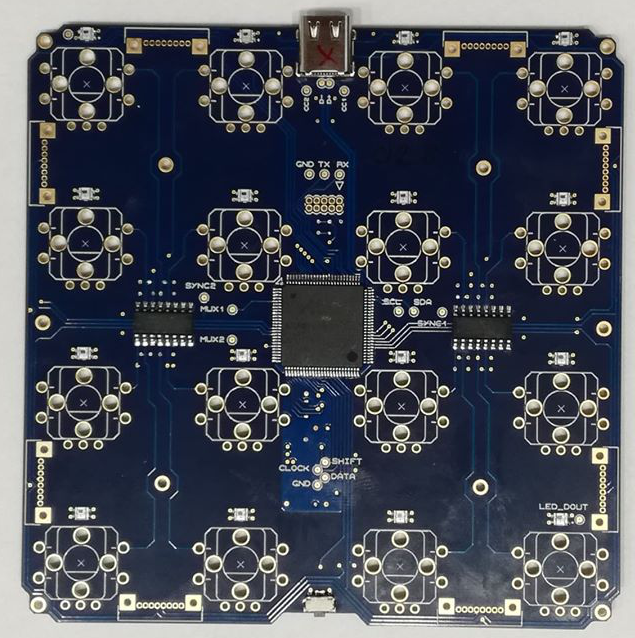
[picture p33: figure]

A Motherboard részegység tekinthető a Grid agyának, a felhasználói interakciók feldolgozását végzi, valamint a modulok közötti kommunikációért felelős. Kiemelkedő költséget ezen a részegységen a SAMD51 típusú processzor és a manuális összeszerelés/tesztelés jelent. Terveink szerint ennek a részegységnek az összeszerelését is JLCPCB nevű partnerünk végzi majd.

Típus | Beszállító | Darabszám | Darabár [USD] | Ár [USD]
100n | LCSC | 44 | 0.01 | 0.44
4n7 | LCSC | 1 | 0.01 | 0.01
10u | LCSC | 2 | 0.01 | 0.02
1u | LCSC | 4 | 0.01 | 0.04
FERRIT | LCSC | 2 | 0.00 | 0.01
USB_C | LCSC | 1 | 0.72 | 0.72
Conn_01x08 | LCSC | 8 | 0.05 | 0.38
5k1 | LCSC | 2 | 0.01 | 0.02
10k | LCSC | 9 | 0.01 | 0.09
1M | LCSC | 1 | 0.01 | 0.01
1k | LCSC | 21 | 0.01 | 0.21
Mapmode | LCSC | 1 | 0.03 | 0.03
74HC165 | LCSC | 1 | 0.06 | 0.06
U_ESD_4ch | LCSC | 1 | 0.04 | 0.04
U_REGULATOR | LCSC | 2 | 0.02 | 0.05
SAMD51N20A | Mouser | 1 | 4.65 | 4.65
U_FLASH | LCSC | 1 | 0.19 | 0.19
PCB | JLCPCB | 1 | 2.32 | 2.32
SMTA | Intech Studio (Manual) | 1 | 3.30 | 3.30
THTA | Intech Studio (Manual) | 0.5 | 3.30 | 1.65
TESTING | Intech Studio (Manual) | 0.25 | 3.30 | 0.83

Processzor

Szerelés/Teszt

# User Interface [30,19 USD]

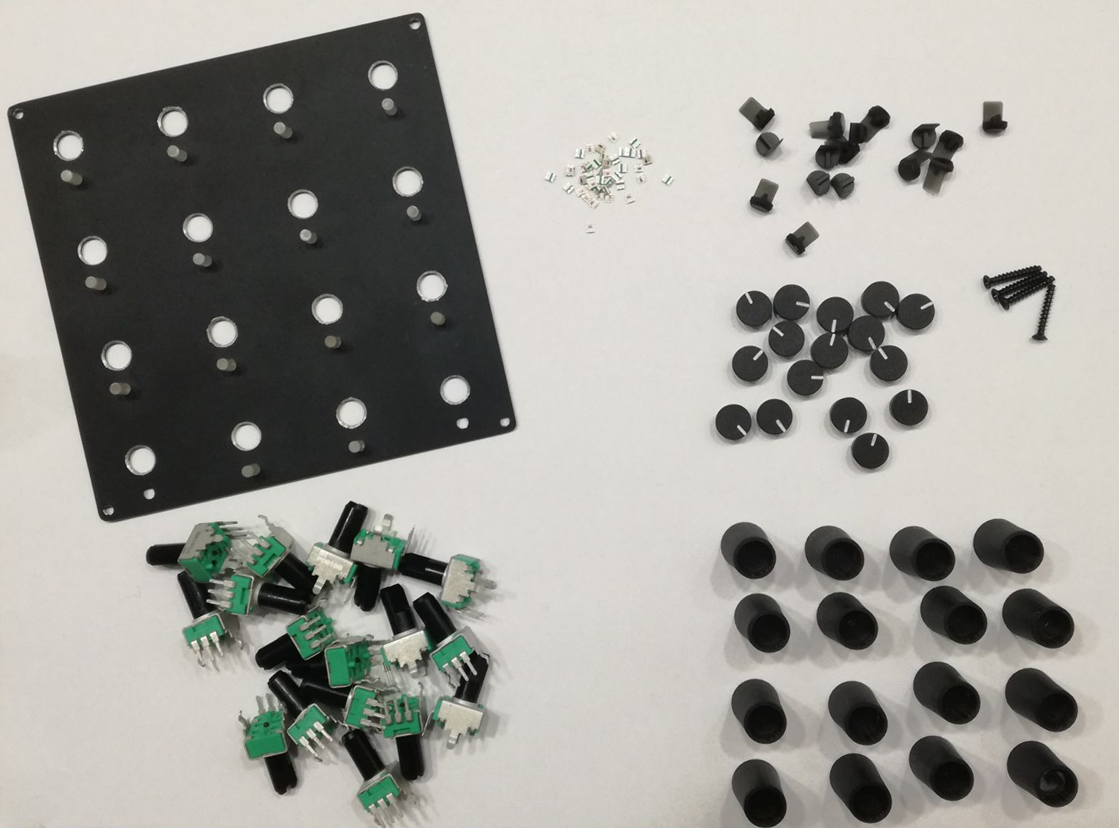
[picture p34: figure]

A User Interface az a részegységbe beletartozik az összes kezelőszerv, a hozzá tartozó műanyag sapkák, LED-ek, optikai alkatrészek, és a termék előlapját képező fémtető. Ennek a részegységnek az előállítási költsége a legnagyobb, itt van legnagyobb lehetőség az optimalizálásra. Első körben fémtető- és a lightpipe beszállítót váltunk, ezt követően kell olcsóbb alternatívát találni a potméterekre és a műanyag potmétersapkákra.

Típus | Beszállító | Darabszám | Darabár [USD] | Ár [USD]
Alu Frontpanel | Starrapid | 1 | 12.2 | 12.20
PZ1 Screw | TME | 4 | 0.03 | 0.10
Lighpipe | Mouser | 16 | 0.17 | 2.67
WS2812C-2020 | TME | 16 | 0.1 | 1.60
Heatshrink | Intech Studio | 16 | 0.02 | 0.32
Potentiometer | Mouser | 16 | 0.35 | 5.58
Pot Cap Body | TME | 16 | 0.21 | 3.36
Pot Cap Top | TME | 16 | 0.19 | 3.04
Pot Cap Insert | Intech Studio | 16 | 0.02 | 0.32
Assembly | Intech Studio (Manual) | 0.3 | 3.3 | 0.99

Potméter sapka

Potméter

Fémtető

# Csomagolás [3,36 USD]

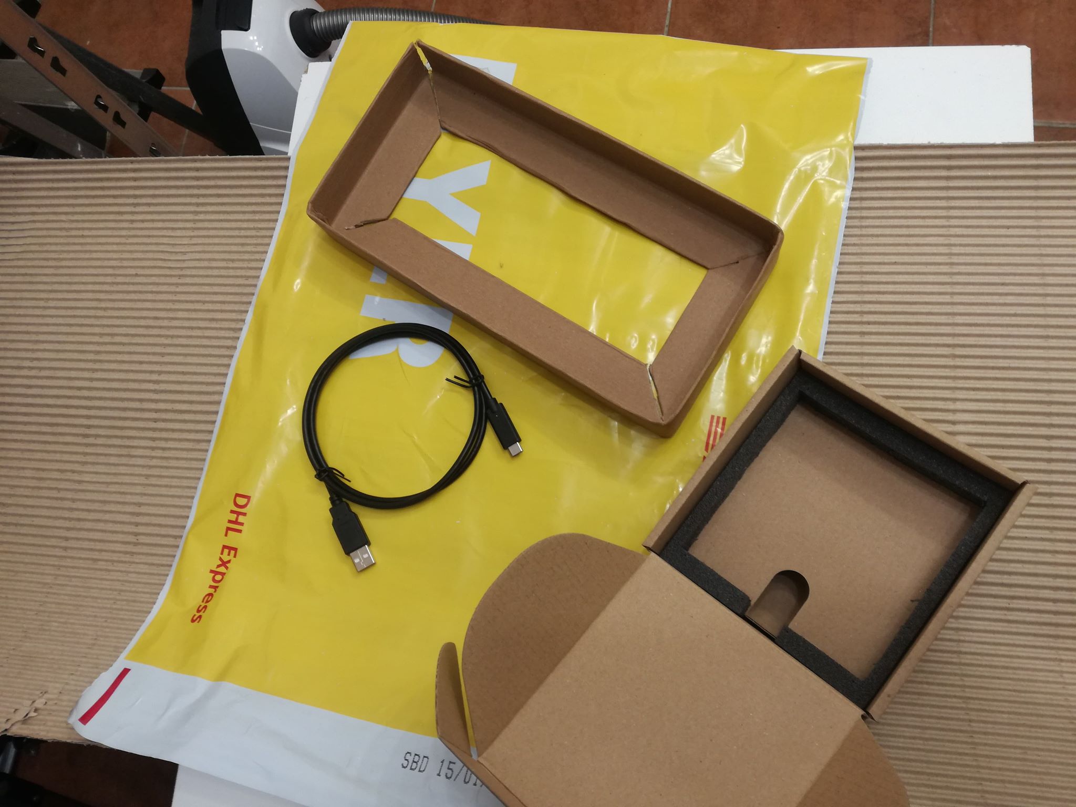
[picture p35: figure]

A csomagoláshoz használt kartondobozt, a bele kerülő habbetétet, a védőcsomagolásként használt élkartont és hullámkartont jelenleg is magyar beszállítóktól vásároljuk. Ennek legfőbb oka, hogy a nagy szállítási térfogat miatt drága lenne külföldről hozatni. A termék mellé tartozékként csomagolt USB C kábelt viszont a későbbiekben mindenképpen közvetlenül Kínából fogjuk beszerezni. Ezen a tartozékon körülbelül 1,2-1,5 USD közötti megtakarítás várható.

Típus | Beszállító | Darabszám | Darabár [USD] | Ár [USD]
USB-C to USB-A cable 1m | TME | 1 | 2.02 | 2.02
Cardboard packaging | Keskeny és Társa | 1 | 0.36 | 0.36
Foam Insert | Polifoambolt | 0.01 | 10.6 | 0.15
Élvédő Karton | BMP Packaging | 0.25 | 0.33 | 0.08
Hullámkarton | BMP Packaging | 0.04 | 6.44 | 0.26
Csomagoló zacskó | DHL | 1 | 0 | 0.00
Stamping | Intech Studio (Manual) | 0.05 | 3.3 | 0.17
Gluing | Intech Studio (Manual) | 0.05 | 3.3 | 0.17
Assembly | Intech Studio (Manual) | 0.05 | 3.3 | 0.17

USB Kábel

# Várható változások részletesen

Inkubáció+ időszak

A termékben a kezelőfelület teszik ki a teljes előállítási költség 44%-át, ami jelenleg 30,19 USD. Ebből a felhasznált potméterek, gombok és a hozzá tartozó gombsapkák 12,3 USD, az fém előlap 12,2 USD, a LED-ek és a hozzá tartozó optika további 4,27 USD.

A potméterek és sapkák beszerzése jelenleg disztributorokon keresztül történik, de a rendelési mennyiségek növelésével már közvetlenül a gyártótól be tudjuk szerezni azokat, így körülbelül 15% árcsökkenés várható. A fémtető gyártásához megkerestünk több kínai céget, közülük kisszérián a JTR Machine Co ajánlata a legkedvezőbb, a Starrapidhoz képest 30%-kal olcsóbban dolgoznak már 100 db-os rendelés esetén is. A LED-eket jelenleg is közvetlenül a gyártótól szerezzük be, azonban a hozzá tartozó optika jelenleg a BIVAR cég terméke. Korábbi kínai beszállítónk jelentősen olcsóbban adta ugyanezt az alkatrészt, azonban a COVID következtében elérhetetlenné váltak. Tervünk, hogy keresünk egy másik kínai gyártót, a várható darabár 0,3 USD helyett 0,1 USD. A PO16 típusú termékünkbe 16 db lightpipe kell, tehát ezen az alkatrészen kb 3,2 USD spórolás várható.

Az Interface és Motherboard részegységeket összekötő FFC csatlakozóból 8 db kell egy modulba. Ennek a gyártási költsége jelenleg 800 db csatlakozóra 175 USD. A mostani gyártónál 4000 db-os rendelés esetén (500 modulra) ez mindössze 375 USD lenne, azaz modulonként 1,65 USD helyett 0,73 USD.

Az USB C kábel beszerzése is Kínából fog történni, itt 2 USD helyett 0,75 USD ár várható.

Emellett jelentős még, hogy az automatizált áramköri összeszerelésnek köszönhetően kevesebb bérmunkára lesz szükség, ennek köszönhetően további 3 USD költségcsökkentés várható.

A felsorolt változtatások összesen 14,17 USD csökkenést eredményeznek a PO16 típus előállításában.

Inkubáció+ időszakot követően

Későbbiekben a gyártási volumen növelésével lesz lehetőség az összes alkatrész/részegység optimalizálására, jelentős költségcsökkenés várható a nyomtatott áramköri lemezek gyártása és összeszerelése, az egyedi mágnesek és rugós csatlakozók gyártása, valamint a fémtető és a műanyag készülékház esetén.

A Gird rendszer egyik legnagyobb előnye, hogy gyárthatóság szempontjából az újonnan bevezetett modellek is öröklik a készülékházat, a mágneseket és az Interface részegységet, így már kiadásukkor jelentős része egy bejáratott gyártási folyamattal készül, ezzel csökkentve a fejlesztési időt, kockázatot és költségeket.

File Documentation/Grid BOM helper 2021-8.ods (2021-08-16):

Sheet: User Interface
Típus | Beszállító | Darabszám | Darabár [USD] |  | Ár [USD]
 |  |  | 2020 | 2021 | 2020 | 2021
Alu Frontpanel | Starrapid JTR Machine | 1 | 12.20 | 5.75 | 12.20 | 5.75
PZ1 Screw | TME | 4 | 0.03 | 0.03 | 0.12 | 0.12
Lighpipe | Mouser HK TIANYE | 16 | 0.17 | 0.07 | 2.72 | 1.12
Heatshrink | Various suppliers | 16 | 0.02 | 0.02 | 0.32 | 0.32
Potentiometer | Mouser TTI | 16 | 0.35 | 0.29 | 5.60 | 4.64
Pot Cap Body | TME Cliff | 16 | 0.21 | 0.13 | 3.36 | 2.08
Pot Cap Top | TME Cliff | 16 | 0.19 | 0.13 | 3.04 | 2.08
Pot Cap Insert | Intech Studio | 16 | 0.02 | 0.02 | 0.32 | 0.32
Bushing | Dakunlun | 16 | 0.00 | 0.07 | 0.00 | 1.12
Assembly | Intech Studio (Manual) | 1 | 0.99 | 0.99 | 0.99 | 0.99
 |  |  | SUBTOTAL: |  | 28.67 | 18.54

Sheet: Csomagolás
Típus | Beszállító | Ár [USD]
 |  | 2020 | 2021 | 2022
USB cable | TME Sin Seader | 3.30 | 0.86 | 0.86
Cardboard packaging | Keskeny és Társa | 0.36 | 0.56 | 0.36
Foam / Cardboard Insert | Polifoambolt Keskeny. | 0.45 | 0.30 | 0.30
Élvédő + Hullámkarton | BMP Packaging | 0.46 | 0.46 | 0.26
Stamping / Plotter | Intech Studio | 0.20 | 0.05 | 0.05
DHL Registration | Intech Studio (Manual) | 0.83 | 0.83 | 0.10
Outbound QA | Intech Studio (Manual) | 1.00 | 0.66 | 0.10
Assembly | Intech Studio (Manual) | 0.66 | 0.66 | 0.66
 | SUBTOTAL: | 7.26 | 4.37 | 2.69

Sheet: Canvas
Típus | Beszállító | Darabszám | Darabár [USD] |  |  | Ár [USD]
 |  |  | 2020 | 2021 | 2022 | 2020 | 2021 | 2022
Magnet 3x15mm | NingBu Riseng | 8 | 0.15 | 0.18 | 0.18 | 1.20 | 1.44 | 1.44
Magnet C-3N52 | Magnetplanet NingBu | 4 | 0.13 | 0.04 | 0.04 | 0.52 | 0.16 | 0.16
Sticker | Dymobolt | 1 | 0.05 | 0.05 | 0.05 | 0.05 | 0.05 | 0.05
Foot | Mouser Hong sheng | 4 | 0.07 | 0.05 | 0.05 | 0.28 | 0.20 | 0.20
Magnet/Interface Gluing | Intech Studio (Manual) | 1 | 0.80 | 0.80 | 0.80 | 0.80 | 0.80 | 0.80
Testing | Intech Studio (Manual) | 1 | 0.60 | 0.60 | 0.40 | 0.60 | 0.60 | 0.40
Motherboard Installation | Intech Studio (Manual) | 1 | 0.60 | 0.60 | 0.40 | 0.60 | 0.60 | 0.40
Canvas Hybrid* |  | 1 | 11.10 | 6.13 | N/A | 11.10 | 6.13 | N/A
Injection moulded canvas** | OEM | 1 | N/A | N/A | 2.41 | N/A | N/A | 2.41
 |  |  | SUBTOTAL: |  |  | 15.15 | 9.98 | 5.86
Canvas Hybrid* tételesen lebontva:
Típus | Beszállító | Darabszám | Darabár [USD] |  |  | Ár [USD]
 |  |  | 2020 | 2021 | 2022 | 2020 | 2021 | 2022
Resin | 3D Prima Anycubic | 0.04 | 64.90 | 28.42 | N/A | 2.60 | 1.14 | N/A
Print Time | Intech Studio (Resin) | 1 | 7.00 | 3.50 | N/A | 7.00 | 3.50 | N/A
Routing | Intech Studio (CNC) | 1 | 1.00 | 1.00 | N/A | 1.00 | 1.00 | N/A
Cleaning | Intech Studio (Manual) | 1 | 0.50 | 0.50 | N/A | 0.50 | 0.50 | N/A
 |  |  | SUBTOTAL: |  |  | 11.10 | 6.14 | N/A
Injection moulded canvas** tételesen lebontva:
Típus | Beszállító | Darabszám | Darabár [USD] |  |  | Ár [USD]
 |  |  | 2020 | 2021 | 2022 | 2020 | 2021 | 2022
Tooling (mould life 50k) | ICO | 0.00002 | N/A | N/A | 10500 | N/A | N/A | 0.21
Part price | ICO | 1 | N/A | N/A | 1.27 | N/A | N/A | 1.27
Shipping & Packaging | Economy air | 1 | N/A | N/A | 0.93 | N/A | N/A | 0.93
 |  |  | SUBTOTAL: |  |  | N/A | N/A | 2.41

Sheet: Canvas Scaling
pcs/yr | Hybrid | Hybrid * | Injection | helper
10 | 11.1 | 11.5
100 | 7 | 8.26491106406735 | 109.77
300 | 5.9 | 8.09089023002067
500 | 5.6 | 8.42842712474619
1000 | 5.5 | 9.5 | 12.7
1500 |  |  | 8
3000 | 5.475 | 12.4032032302755 | 5.33
5000 | 5.45 | 14.3942719099992 | 3.63
10000 | 5.4 | 18.0491106406735 | 2.32
30000 | 5.4 | 27.3089023002066 | 1.62

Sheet: Interface
Típus | Beszállító | Darabszám | Darabár [USD] |  | Ár [USD]
 |  |  | 2020 | 2021 | 2020 | 2021
Components | Sourced / Turnkey | 1 | 3.83 | 2.91 | 3.83 | 2.91
FFC | PCBWAY | 8 | 0.18 | 0.10 | 1.44 | 0.80
POGO | CFE / UPE | 32 | 0.22 | 0.12 | 7.04 | 3.84
PCB | JLCPCB | 1 | 0.64 | 0.54 | 0.64 | 0.54
SMTA | Manual / JLCPCB | 1 | 1.65 | 0.67 | 1.65 | 0.67
THTA | Intech Studio (Manual) | 1 | 0.83 | 0.83 | 0.83 | 0.83
TESTING | Intech Studio (Manual) | 1 | 0.33 | 0.33 | 0.33 | 0.33
 |  |  | SUBTOTAL: |  | 15.76 | 9.92

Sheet: Motherboard
Típus | Beszállító | Darabszám | Darabár [USD] |  | Ár [USD]
 |  |  | 2020 | 2021 | 2020 | 2021
SMT Components | Sourced / Turnkey | 1 | 1.19 | 1.19 | 1.19 | 1.19
USB_C | LCSC | 1 | 0.72 | 0.23 | 0.72 | 0.23
Conn_01x08 | LCSC | 8 | 0.05 | 0.05 | 0.40 | 0.40
Mapmode | LCSC | 1 | 0.03 | 0.03 | 0.03 | 0.03
SAMD51N20A | Mouser | 1 | 4.65 | 5.18 | 4.65 | 5.18
WS2812C-2020 | TME / World Semi | 16 | 0.10 | 0.07 | 1.60 | 1.12
PCB | JLCPCB | 1 | 2.32 | 1.88 | 2.32 | 1.88
PCB Shipping | DHL | 1 | 0.80 | 0.80 | 0.80 | 0.80
SMTA Bottom | Manual / JLCPCB | 1 | 3.30 | 0.81 | 3.30 | 0.81
SMTA Top | Intech Studio (Manual) | 1 | 3.30 | 3.30 | 3.30 | 3.30
THTA | Intech Studio (Manual) | 1 | 1.75 | 1.75 | 1.75 | 1.75
TESTING | Intech Studio (Manual) | 1 | 0.83 | 0.83 | 0.83 | 0.83
 |  |  | SUBTOTAL: |  | 20.89 | 17.52

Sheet: Összefoglaló
 | 2020 | 2021 | 2022
Canvas | 15.15 | 9.98 | 5.86 | Bérmunka | Bérmunka
Interface | 15.76 | 9.92 | 9.92 |  | JLCPCB
Motherboard | 20.89 | 17.52 | 17.52
User Interface | 28.67 | 18.54 | 18.54 | Mouser | Mouser
Packaging | 7.26 | 4.37 | 2.69 |  | TTI
TOTAL: | 87.73 | 60.33 | 54.53 |  | HK TIANYE
 | 68 | 54 |  |  | Hong sheng
 |  |  |  | Starrapid | JTR Machine
 |  |  |  | TME | Sin Seader
 |  |  |  |  | Cliff
 |  |  |  |  | World Semi
 |  |  |  |  | TME
 |  |  |  | LCSC | JLCPCB
 |  |  |  |  | LCSC
 |  |  |  | 3D prima | Anycubic
 |  |  |  | PCBWAY | PCBWAY
 |  |  |  | NingBu Riseng | NingBu Riseng
 |  |  |  | Magnetplanet | NingBu Riseng
 |  |  |  | Keskeny és Társa | Keskeny és Társa
 |  |  |  | BMP Packaging | BMP Packaging
 |  |  |  | Polifoambolt | Keskeny és Társa
 |  |  |  | Dymobolt | Dymobolt
 |  |  |  | DHL | DHL

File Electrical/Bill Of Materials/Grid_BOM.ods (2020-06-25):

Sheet: Summary
Subassembly | Price
Canvas | 7.6205 | USD | Production scale | 100 module / batch
Interface Board | 12.19 | USD | Direct Sale Net. Price | 99 | USD
Motherboard | 15.06 | USD | Cost of Sold Goods | 68.42425 | USD
User Interface | 30.19 | USD
Acc. & Packaging | 3.36 | USD
TOTAL: | 68.42425 | USD | Gross Margin: | 30.88%
Bérmunka | 14.52
Mouser | 13.20
Starrapid | 12.20
TME | 10.12
LCSC | 6.14
CFE | 3.52
JLCPCB | 2.32
3D Prima | 2.27
PCBWAY | 1.40
NingBu Riseng | 1.34
Intech Studio | 0.64
Magnetplanet | 0.52
Keskeny és Társa | 0.36
BMP Packaging | 0.34
Polifoambolt | 0.15
Dymobolt | 0.05
DHL | 0.00
TOTAL: | 69.10425

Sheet: BOM
Id | Designator | Package | Quantity | Designation | Supplier | Link | Order Qty | Price | Extended | Subassembly
14 | M1,M2,M3,M4,M5,M6,M7,M8 | 3x15_dia | 8 | Magnet 3x15mm | NingBu Riseng | Custom Quote | 1000 | 0.168 | 1.344 | Canvas
29 | M9,M10,M11,M12 | 3x3x3 | 4 | Magnet C-3N52 | Magnetplanet | https://magnetplanet.eu/index.php?oldal=magnes_adatlap&cikkszam=C-3N52&tipus=Elemi%20magnesek | 200 | 0.13 | 0.52 | Canvas
 |  |  | 1 | Sticker | Dymobolt | https://www.dymobolt.hu/szalagok-kazettak-cimkek-dymo-nyomtatokhoz-98/etikettcimkek-labelwriter-nyomtatokhoz-138/tartos-cimkek-161/tartos-etikett-cimke-25mmx2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 | 1700 | 0.054 | 0.054 | Canvas
 |  |  | 4 | Foot | Mouser | https://hu.mouser.com/ProductDetail/534-783-B | 250 | 0.074 | 0.296 | Canvas
 |  |  | 0.035 | Resin | 3D Prima | https://www.3dprima.com/filaments/resin/wanhao-3d-printer-uv-resin-1000-ml-black/a-22341/ | 1 | 64.9 | 2.2715 | Canvas
 |  |  | 2.2 | Print Time | Intech Studio |  |  | 0 | 0 | Canvas
 |  |  | 0.15 | Routing | Intech Studio (Manual) |  |  | 3.3 | 0.495 | Canvas
 |  |  | 0.15 | Cleaning | Intech Studio (Manual) |  |  | 3.3 | 0.495 | Canvas
 |  |  | 0.25 | Magnet/Interface Gluing | Intech Studio (Manual) |  |  | 3.3 | 0.825 | Canvas
 |  |  | 0.2 | Testing | Intech Studio (Manual) |  |  | 3.3 | 0.66 | Canvas
 |  |  | 0.2 | Motherboard Installation | Intech Studio (Manual) |  |  | 3.3 | 0.66 | Canvas | TOTAL: | 7.6205 | USD
2 | U9,U4 | SOT-23-5 | 8 | LMV321 | LCSC | https://lcsc.com/product-detail/Operational-Amplifiers_3PEAK-LMV321TP-TR_C90297.html | 50 | 0.057996 | 0.46 | Interface Board
3 | R4,R3,R1,R6,R2 | RES_0805 | 20 | 470R | LCSC | Not Critical |  | 0.015 | 0.30 | Interface Board
4 | U8,U7,U6,U5 | SOT-23-5 | 16 | 74HC1G66GV | LCSC | https://lcsc.com/product-detail/74-Series_Nexperia-74HC1G66GV-125_C89412.html | 500 | 0.039437 | 0.63 | Interface Board
8 | Q4,Q3 | SOT-23-6 | 8 | WST2011 | LCSC | https://lcsc.com/product-detail/MOSFET_Winsok-Semicon-WST2011_C148368.html | 500 | 0.109091 | 0.87 | Interface Board
9 | U3 | SOT-23W | 4 | HALL 39E | LCSC | https://lcsc.com/product-detail/Sensors_OH49E-S_C85573.html | 500 | 0.174242 | 0.70 | Interface Board
10 | U2,U1 | SOT-23-6 | 8 | SESRV05-4 | LCSC | https://lcsc.com/product-detail/Others_SEMIWARE-SESRV05-4_C294963.html | 100 | 0.039773 | 0.32 | Interface Board
11 | R8,R7,R5 | RES_0805 | 12 | 10k | LCSC | Not Critical |  | 0.015 | 0.18 | Interface Board
13 | D1 | SOT-23 | 4 | BAT54C | LCSC | https://lcsc.com/product-detail/Others_Yangzhou-Yangjie-Elec-Tech-BAT54C_C340701.html | 600 | 0.016267 | 0.07 | Interface Board
14 | C5 | CAP_0805 | 4 | 10u | LCSC | Not Critical |  | 0.015 | 0.06 | Interface Board
15 | C4,C3 | CAP_0805 | 8 | 100n | LCSC | Not Critical |  | 0.015 | 0.12 | Interface Board
16 | C2,C1 | CAP_0805 | 8 | 1u | LCSC | Not Critical |  | 0.015 | 0.12 | Interface Board
12 | J4,J2 | FFC | 8 | FFC | PCBWAY | Custom Quote | 800 | 0.175 | 1.40 | Interface Board
7 | J3,J1 | POGO | 32 | POGO | CFE | Custom Quote | 10000 | 0.11 | 3.52 | Interface Board
 |  |  | 1 | PCB | JLCPCB | Custom Quote | 30 | 0.64 | 0.64 | Interface Board
 |  |  | 0.5 | SMTA | Intech Studio (Manual) |  |  | 3.3 | 1.65 | Interface Board
 |  |  | 0.25 | THTA | Intech Studio (Manual) |  |  | 3.3 | 0.83 | Interface Board
 |  |  | 0.1 | TESTING | Intech Studio (Manual) |  |  | 3.3 | 0.33 | Interface Board | TOTAL | 12.19 | USD
4 | C1,C16,C8,C10,C4,C15,C7,C3,C14,C6,C2,C13,C5,C55,C54,C44,C49,C48,C47,C46,C45,C42,C41,C39,C52,C35,C9,C33,C32,C30,C28,C26,C31,C29,C27,C25,C24,C22,C20,C18,C23,C21,C19,C17 | CAP_0805 | 44 | 100n | LCSC | Not Critical |  | 0.01 | 0.44 | Motherboard
29 | C37 | CAP_0805 | 1 | 4n7 | LCSC | Not Critical |  | 0.01 | 0.01 | Motherboard
22 | C43,C38 | CAP_0805 | 2 | 10u | LCSC | Not Critical |  | 0.01 | 0.02 | Motherboard
17 | C53,C36,C40,C34 | CAP_0805 | 4 | 1u | LCSC | Not Critical |  | 0.01 | 0.04 | Motherboard
20 | FB1, FB2 | FERRIT_0805 | 2 | FERRIT | LCSC | https://lcsc.com/product-detail/Ferrite-Beads-And-Chips_600R-25-at100MHz_C21286.html | 500 | 0.004061 | 0.01 | Motherboard
10 | J1 | USB_C_Korean_Hroparts | 1 | USB_C | LCSC | https://lcsc.com/product-detail/USB-Type-C_Korean-Hroparts-Elec-TYPE-C-31-M-04_C129018.html | 100 | 0.719697 | 0.72 | Motherboard
23 | J11,J10,J9,J7,J5,J4,J8,J6 | grid_ffc_8_vertical | 8 | Conn_01x08 | LCSC | https://lcsc.com/product-detail/FFC-FPC-Connectors_Boom-Precision-Elec-FPC-1-0mmpitch-8P-Pull-type-Pick-up_C20110.html | 570 | 0.047367 | 0.38 | Motherboard
26 | R35,R34 | RES_0805 | 2 | 5k1 | LCSC | Not Critical |  | 0.01 | 0.02 | Motherboard
19 | R36,R16,R4,R15,R3,R14,R2,R13,R1 | RES_0805 | 9 | 10k | LCSC | Not Critical |  | 0.01 | 0.09 | Motherboard
11 | R37 | RES_0805 | 1 | 1M | LCSC | Not Critical |  | 0.01 | 0.01 | Motherboard
25 | R39,R38,R40,R42,R41,R32,R30,R28,R26,R31,R29,R27,R25,R24,R22,R20,R18,R23,R21,R19,R17 | RES_0805 | 21 | 1k | LCSC | Not Critical |  | 0.01 | 0.21 | Motherboard
2 | SW1 | SW_HYP_MAPMODE | 1 | Mapmode | LCSC | https://lcsc.com/product-detail/Tactile-Switches_HYP-Hongyuan-Precision-1TS003A-2500-3500A-CT_C255807.html | 100 | 0.028324 | 0.03 | Motherboard
12 | U3 | SOIC-16_3.9x9.9mm_P1.27mm | 1 | 74HC165 | LCSC | https://lcsc.com/product-detail/74-Series_Nexperia_74HC165D-653_74HC165D-653_C5613.html | 150 | 0.056132 | 0.06 | Motherboard
9 | U4 | SOT-23-6 | 1 | U_ESD_4ch | LCSC | https://lcsc.com/product-detail/Others_SEMIWARE-SESRV05-4_C294963.html | 100 | 0.039773 | 0.04 | Motherboard
14 | U6,U5 | SOT-23-5 | 2 | U_REGULATOR | LCSC | https://lcsc.com/product-detail/Low-Dropout-Regulators-LDO_NATLINEAR-LN1134A332MR-G_C141419.html | 300 | 0.024467 | 0.05 | Motherboard
15 | U7 | TQFP-100_14x14mm_P0.5mm | 1 | SAMD51N20A | Mouser | https://www2.mouser.com/ProductDetail/Microchip-Technology/ATSAMD51N20A-AU | 100 | 4.65 | 4.65 | Motherboard
6 | U8 | SOIC-8_WIDE | 1 | U_FLASH | LCSC | https://lcsc.com/product-detail/FLASH_Winbond-Elec-W25Q16JVSSIQ_C82317.html | 100 | 0.192424 | 0.19 | Motherboard
 |  |  | 1 | PCB | JLCPCB | Custom Quote | 25 | 2.32 | 2.32 | Motherboard
 |  |  | 1 | SMTA | Intech Studio (Manual) |  |  | 3.30 USD/h | 3.30 | Motherboard
 |  |  | 0.5 | THTA | Intech Studio (Manual) |  |  | 3.30 USD/h | 1.65 | Motherboard
 |  |  | 0.25 | TESTING | Intech Studio (Manual) |  |  | 3.30 USD/h | 0.83 | Motherboard | TOTAL: | 15.06 | USD
 |  | 106.6x106.6 | 1 | Alu Frontpanel | Starrapid | Custom Quote | 300 | 12.2 | 12.20 | User Interface
 |  | 2.2x14mm | 4 | PZ1 Screw | TME | https://www.tme.eu/hu/details/b2.2x14_bn82427_bk/csavarok/bossard/3860643/ | 1000 | 0.026 | 0.10 | User Interface
 |  |  | 16 | Lighpipe | Mouser | https://hu.mouser.com/ProductDetail/593-LFB025CTP | 1000 | 0.167 | 2.67 | User Interface
 |  |  | 16 | WS2812C-2020 | TME | https://www.tme.eu/hu/details/ws2812c-2020/szines-smd-led-diodak/worldsemi/ | 1000 | 0.1 | 1.60 | User Interface
 |  |  | 16 | Heatshrink | Intech Studio |  | 1 | 0.02 | 0.32 | User Interface
 |  |  | 16 | Potentiometer | Mouser | https://www2.mouser.com/ProductDetail/BI-Technologies-TT-Electronics/P090S-04F20BR10K | 500 | 0.349 | 5.58 | User Interface
 |  |  | 16 | Pot Cap Body | TME | https://www.tme.eu/hu/details/k88-blk-d/axial-potenciometerek-gombok/cliff/cl178862/ | 500 | 0.21 | 3.36 | User Interface
 |  |  | 16 | Pot Cap Top | TME | https://www.tme.eu/hu/details/k85-blk-l/axial-potenciometerek-gombok/cliff/k85-caps-black/ | 500 | 0.19 | 3.04 | User Interface
 |  |  | 16 | Pot Cap Insert | Intech Studio |  |  | 0.02 | 0.32 | User Interface
 |  |  | 0.3 | Assembly | Intech Studio (Manual) |  |  | 3.3 | 0.99 | User Interface | TOTAL: | 30.19 | USD
 | FP1 | Accessories | 1 | USB-C to USB-A cable 1m | TME | https://www.tme.eu/hu/details/qoltec-50487/usb-kabelek-es-adapterek/qoltec/50487/ | 5 | 2.02 | 2.02 | Packaging
 | DOBOZ | Wrapping | 1 | Cardboard packaging | Keskeny és Társa | Custom Quote | 300 | 0.36 | 0.36 | Packaging
 |  | Wrapping | 0.014 | Foam Insert | Polifoambolt | http://polifoambolt.hu/spd/Poli102520-1/Polifoam-hablemez-tekercs-N-3020-PE-szurke-1m-szel | 1 | 10.6 | 0.15 | Packaging
 |  | Packaging | 0.25 | Élvédő Karton | BMP Packaging | https://www.bmp.hu/spd/00005494/Elvedo-papir-35-x-35-x-3-x-2000-mm | 2 | 0.33 | 0.08 | Packaging
 |  | Packaging | 0.04 | Hullámkarton | BMP Packaging | https://www.bmp.hu/spd/web0030/Hullampapir-hullamkarton-tekercs-100-cm-x-25-m | 25 | 6.44 | 0.26 | Packaging
 |  | Packaging | 1 | Csomagoló zacskó | DHL |  | 50 | 0 | 0.00 | Packaging
 |  | Hour | 0.05 | Stamping | Intech Studio (Manual) |  |  | 3.3 | 0.17 | Packaging
 |  | Hour | 0.05 | Gluing | Intech Studio (Manual) |  |  | 3.3 | 0.17 | Packaging
 |  | Hour | 0.05 | Assembly | Intech Studio (Manual) |  |  | 3.3 | 0.17 | Packaging | TOTAL: | 3.36 | USD

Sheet: Pivot Table_BOM_1
Supplier | Sum - Extended
3D Prima | 2.27
Add pcb cost!!!
BMP Packaging | 0.34
CFE | 3.52
DHL | 0.00
Dymobolt | 0.05
Intech Studio | 0.64
Intech Studio (Manual) | 13.20
JLCPCB | 2.32
Keskeny és Társa | 0.36
LCSC | 6.14
Magnetplanet | 0.52
Mouser | 13.20
NingBu Riseng | 1.34
PCBWAY | 1.40
Polifoambolt | 0.15
Starrapid | 12.20
TME | 10.12

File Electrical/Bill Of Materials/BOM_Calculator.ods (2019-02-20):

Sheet: TestBOM
INPUT DATA |  |  |  |  |  |  | HELPER COLUMNS |  | CALCULATOR |  |  |  |  |  | RENDER
Instructions: | Insert BOM from CSV starting at cell A10 in the given format |  |  |  |  |  |  |  |  |  |  | SUM | SUM
 |  |  |  |  |  |  |  |  |  | BOM * X | !!!NEW!!! | 14982.526 | 7491263 | HUF
 |  |  |  |  |  |  |  |  |  | 500 |  |  |  |  |  |  |  |  |  |  |  |  | HIDDEN | HIDDEN
 |  |  |  |  |  |  |  |  |  |  | Price/Piece | Price/Bom | Price/Bulk |  | Original | Original | Original | Original | Original | Calculated | Calculated | Calculated | Calculated | Calculated
Category | Quantity | References | Value | Stock Code | PCB Package |  | Helper | ROW INDEX!! | Quantity | Quantity Bulk | @ quantity | @ quantity | @ quantity |  | Category | Quantity | References | Value | PCB Package | Manufacturer | Stock Code | Supplier Link | Link | Supplier
Integrated Circuits | 1 | U1 | AT SAM D5X/E5X (100PIN) | ATSAMD51N19 | TQFP100 |  | AT SAM D5X/E5X (100PIN) TQFP100 | 70 | 1 | 500 | 1343.68 | 1343.68 | 671840 |  | Integrated Circuits | 1 | U1 | AT SAM D5X/E5X (100PIN) | TQFP100 | Microchip Technology | ATSAMD51N20A-AUT | Mouser | https://hu.mouser.com/ProductDetail/Microchip-Technology/ATSAMD51N20A-AUT | Mouser
Integrated Circuits | 1 | U2 | U FLASH IS25LP016D | IS25LP016D-JNLE-TR | SO8 |  | U FLASH IS25LP016D SO8 | 80 | 1 | 500 | 226.61 | 226.61 | 113305 |  | Integrated Circuits | 1 | U2 | U FLASH IS25LP016D | SO8 | ISSI | IS25LP016D-JNLE-TR | Mouser | https://hu.mouser.com/ProductDetail/870-IS25LP016DJNLETR | Mouser
Integrated Circuits | 2 | U3-U4 | 4051 | 74HC4051D | SO16 |  | 4051 SO16 | 68 | 2 | 1000 | 32.3 | 64.6 | 32300 |  | Integrated Circuits | 2 | U3-U4 | 4051 | SO16 | Nexperia | 74HC4051D,653 | Mouser | https://hu.mouser.com/ProductDetail/Nexperia/74HC4051D653?qs=sGAEpiMZZMvjbjwkTuU2aUi183VoLziY44wW9O7nGig%3d | Mouser
Integrated Circuits | 1 | U100 | FUSB303 | FUSB303TMX | X2QFN12 |  | FUSB303 X2QFN12 | 74 | 1 | 500 | 85.02 | 85.02 | 42510 |  | Integrated Circuits | 1 | U100 | FUSB303 | X2QFN12 | ON Semiconductor | FUSB303TMX | Mouser | https://hu.mouser.com/ProductDetail/863-FUSB303TMX | Mouser
Integrated Circuits | 1 | U101 | USBLC6-2 | USBLC6-2SC6 | SUPERSOT-6 |  | USBLC6-2 SUPERSOT-6 | 76 | 1 | 500 | 63.44 | 63.44 | 31720 |  | Integrated Circuits | 1 | U101 | USBLC6-2 | SUPERSOT-6 | ON Semiconductor | USBLC6-2SC6 | Mouser | https://hu.mouser.com/ProductDetail/STMicroelectronics/USBLC6-2SC6 | Mouser
Integrated Circuits | 2 | U102-U103 | NCV8161BSN330T1G | NCV8161BSN330T1G | TSOP-5 |  | NCV8161BSN330T1G TSOP-5 | 78 | 2 | 1000 | 66.71 | 133.42 | 66710 |  | Integrated Circuits | 2 | U102-U103 | NCV8161BSN330T1G | TSOP-5 | ON Semiconductor | NCV8161BSN330T1G | Mouser | https://hu.mouser.com/ProductDetail/ON-Semiconductor/NCV8161BSN330T1G | Mouser
Resistors | 3 | R1-R2,R101 | 0R |  | 0805_RES |  | 0R 0805_RES | 20 | 3 | 1500 | 2.891 | 8.673 | 4336.5 |  | Resistors | 3 | R1-R2,R101 | 0R | 0805_RES | ROYAL OHM | 0805S8J0000T5E | TME | https://www.tme.eu/hu/details/smd0805-0r/smd-ellenallasok-0805/royal-ohm/0805s8j0000t5e/ | TME
Resistors | 20 | R3,R6,R8,R21-R36,R106 | 10k |  | 0805_RES |  | 10k 0805_RES | 17 | 20 | 10000 | 1.794 | 35.88 | 17940 |  | Resistors | 20 | R3,R6,R8,R21-R36,R106 | 10k | 0805_RES | ROYAL OHM | HP05W3J0103T5E | TME | https://www.tme.eu/en/details/hp05-10k5%25/0805-smd-resistors/royal-ohm/hp05w3j0103t5e/ | TME
Resistors | 10 | R11-R20 | 1k |  | 0805_RES |  | 1k 0805_RES | 19 | 10 | 5000 | 1.794 | 17.94 | 8970 |  | Resistors | 10 | R11-R20 | 1k | 0805_RES | ROYAL OHM | HP05W3J0102T5E | TME | https://www.tme.eu/en/details/hp05-1k5%25/0805-smd-resistors/royal-ohm/hp05w3j0102t5e/ | TME
Resistors | 2 | R100,R102 | 1M |  | 0805_RES |  | 1M 0805_RES | 21 | 2 | 1000 | 4.422 | 8.844 | 4422 |  | Resistors | 2 | R100,R102 | 1M | 0805_RES | ROYAL OHM | CQ05S8F1004T5E | TME | https://www.tme.eu/hu/details/cq0805-1m-1%25/smd-ellenallasok-0805/royal-ohm/cq05s8f1004t5e/ | TME
Resistors | 3 | R103-R105 | 4.7k |  | 0805_RES |  | 4.7k 0805_RES | 23 | 3 | 1500 | 4.422 | 13.266 | 6633 |  | Resistors | 3 | R103-R105 | 4.7k | 0805_RES | ROYAL OHM | CQ05S8F4701T5E | TME | https://www.tme.eu/hu/details/cq0805-4k7-1%25/smd-ellenallasok-0805/royal-ohm/cq05s8f4701t5e/ | TME
Capacitors | 48 | C1,C4-C10,C12,C14,C17-C51,C102-C103,C105 | 100n |  | 0805_CAP |  | 100n 0805_CAP | 33 | 48 | 24000 | 6.21 | 298.08 | 149040 |  | Capacitors | 48 | C1,C4-C10,C12,C14,C17-C51,C102-C103,C105 | 100n | 0805_CAP | Yageo | CC0805ZRY5V9BB104 | Mouser | https://hu.mouser.com/ProductDetail/Yageo/CC0805ZRY5V9BB104?qs=sGAEpiMZZMvsSlwiRhF8qj9NgEuXmwzvSh6j0DMSg5Q%3d | Mouser
Capacitors | 2 | C2-C3 | 22p |  | 0805_CAP |  | 22p 0805_CAP | 28 | 2 | 1000 | 2.469 | 4.938 | 2469 |  | Capacitors | 2 | C2-C3 | 22p | 0805_CAP | Samsung | CL21C220JBANNNC | TME | https://www.tme.eu/hu/details/cl21c220jbannnc/mlcc-smd-0805-kondenzatorok/samsung/ | TME
Capacitors | 2 | C11,C13 | 10u |  | 0805_CAP |  | 10u 0805_CAP | 44 | 2 | 1000 | 6.918 | 13.836 | 6918 |  | Capacitors | 2 | C11,C13 | 10u | 0805_CAP | Samsung | CL21A106KPFNNNE | TME | https://www.tme.eu/hu/details/cl21a106kpfnnne/mlcc-smd-0805-kondenzatorok/samsung/ | TME
Capacitors | 2 | C15,C101 | 4.7u |  | 0805_CAP |  | 4.7u 0805_CAP | 41 | 2 | 1000 | 7.142 | 14.284 | 7142 |  | Capacitors | 2 | C15,C101 | 4.7u | 0805_CAP | Samsung | CL21A475KPFNNNG | TME | https://www.tme.eu/hu/details/cl21a475kpfnnng/mlcc-smd-0805-kondenzatorok/samsung/ | TME
Capacitors | 3 | C16,C104,C106 | 1u |  | 0805_CAP |  | 1u 0805_CAP | 37 | 3 | 1500 | 7.052 | 21.156 | 10578 |  | Capacitors | 3 | C16,C104,C106 | 1u | 0805_CAP | Samsung | CL21A105KOFNNNE | TME | https://www.tme.eu/hu/details/cl21a105kofnnne/mlcc-smd-0805-kondenzatorok/samsung/ | TME
Capacitors | 1 | C100 | 4.7n |  | 0805_CAP |  | 4.7n 0805_CAP | 31 | 1 | 500 | 6.717 | 6.717 | 3358.5 |  | Capacitors | 1 | C100 | 4.7n | 0805_CAP | Samsung | CL21B472KBANNNC | TME | https://www.tme.eu/hu/details/cl21b472kbannnc/mlcc-smd-0805-kondenzatorok/samsung/ | TME
Transistors | 8 | Q1-Q8 | DMP3085LSD-13 | DMP3085LSD-13 | SO8 |  | DMP3085LSD-13 SO8 | 58 | 8 | 4000 | 25.52 | 204.16 | 102080 |  | Transistors | 8 | Q1-Q8 | DMP3085LSD-13 | SO8 | Diodes Incorporated | DMP3085LSD-13 | Mouser | https://hu.mouser.com/ProductDetail/Diodes-Incorporated/DMP3085LSD-13 | Mouser
Diodes | 8 | D1-D8 | NSR0320MW2T1G | NSR0320MW2T1G | SOD-323 |  | NSR0320MW2T1G SOD-323 | 61 | 8 | 4000 | 16.02 | 128.16 | 64080 |  | Diodes | 8 | D1-D8 | NSR0320MW2T1G | SOD-323 | ON Semiconductor | NSR0320MW2T1G | Mouser | https://hu.mouser.com/ProductDetail/ON-Semiconductor/NSR0320MW2T1G | Mouser
Miscellaneous | 3 | FB1,FB100-FB101 | 600R@100MHz |  | 0805_IND |  | 600R@100MHz 0805_IND | 49 | 3 | 1500 | 8.212 | 24.636 | 12318 |  | Miscellaneous | 3 | FB1,FB100-FB101 | 600R@100MHz | 0805_IND | TDK | MMZ2012R601A | TME | https://www.tme.eu/hu/details/mmz2012r601a/ferritek-gyongyok/tdk/ | TME
Miscellaneous | 64 | J4-J67 | J SPRINGPIN | TOBY_TEST-3 | J SPRINGPIN |  | J SPRINGPIN J SPRINGPIN | 56 | 64 | 32000 | 11 | 704 | 352000 |  | Miscellaneous | 64 | J4-J67 | J SPRINGPIN | J SPRINGPIN | Toby | TEST-3 | Toby | https://www.toby.co.uk/pcb-hardware/test-points-and-pins/test-3-valcon-wire-form-test-point-27mm-diameter/ | Toby
Miscellaneous | 1 | J68 | J 2X8 |  | J 2X8 MINI SMT |  | J 2X8 J 2X8 MINI SMT | 55 | 1 | 500 | 114 | 114 | 57000 |  | Miscellaneous | 1 | J68 | J 2X8 | J 2X8 MINI SMT | CONNFLY | DS1065-05-2*8S8BS | TME | https://www.tme.eu/hu/details/ds1065-05-2x8s8bs/tuskesorok-es-aljzatok/connfly/ds1065-05-2_8s8bs/ | TME
Miscellaneous | 1 | J100 | J USBTYPEC |  | J USBTYPEC 10133476-10001LF |  | J USBTYPEC J USBTYPEC 10133476-10001LF | 50 | 1 | 500 | 523.26 | 523.26 | 261630 |  | Miscellaneous | 1 | J100 | J USBTYPEC | J USBTYPEC 10133476-10001LF | Amphenol FCI | 10133476-10001LF | Mouser | https://hu.mouser.com/ProductDetail/Amphenol-FCI/10133476-10001LF | Mouser
Miscellaneous | 1 | L1 | 10u |  | 0805_IND |  | 10u 0805_IND | 48 | 1 | 500 | 26.81 | 26.81 | 13405 |  | Miscellaneous | 1 | L1 | 10u | 0805_IND | TDK | MLZ2012N100LTD25 | Mouser | https://hu.mouser.com/ProductDetail/TDK/MLZ2012N100LTD25 | Mouser
Miscellaneous | 16 | LD1-LD16 | WS2812B-MINI | WS2812B-MINI | PLCC4 |  | WS2812B-MINI PLCC4 | 72 | 16 | 8000 | 32.75 | 524 | 262000 |  | Miscellaneous | 16 | LD1-LD16 | WS2812B-MINI | PLCC4 | WORLDSEMI | WS2812B-MINI | TME | https://www.tme.eu/hu/details/ws2812b-mini/szines-smd-led-diodak/worldsemi/ | TME
Miscellaneous | 1 | S1 | S PUSHBUTTON |  | S KMS221GLFS |  | S PUSHBUTTON S KMS221GLFS | 62 | 1 | 500 | 56.95 | 56.95 | 28475 |  | Miscellaneous | 1 | S1 | S PUSHBUTTON | S KMS221GLFS | C&K | KMS221G LFS | TME | https://www.tme.eu/hu/details/kms221glfs/mikrokapcsolok-tact/ck/kms221g-lfs/ | TME
Miscellaneous | 16 | VR1-VR16 | POT-SW-COMBO |  | POT-SW-COMBO |  | POT-SW-COMBO POT-SW-COMBO | 104 | 16 | 8000 | 76 | 1216 | 608000 |  | Miscellaneous | 16 | VR1-VR16 | POT-SW-COMBO | POT-SW-COMBO | TT/Omron | 0 | 0 | 0 | 0
Miscellaneous | 1 | X1 | 12Mhz | 3225-12M-SR | CRYSTAL ILCX13 |  | 12Mhz CRYSTAL ILCX13 | 10 | 1 | 500 | 52.654 | 52.654 | 26327 |  | Miscellaneous | 1 | X1 | 12Mhz | CRYSTAL ILCX13 | SR PASSIVES | 3225-12M-SR | TME | https://www.tme.eu/en/details/3225-12m-sr/smd-quartz-crystals/sr-passives/ | TME
Modules | 4 | M1,M14-M15,M18 | MECH_B2,2X14_SELFT |  | NULL |  | MECH_B2,2X14_SELFT NULL | 101 | 4 | 2000 | 7.65 | 30.6 | 15300 |  | Modules | 4 | M1,M14-M15,M18 | MECH_B2,2X14_SELFT | NULL | Bossard | 3860643 | TME | https://www.tme.eu/en/details/b2.2x14_bn82427_bk/screws/bossard/3860643/ | TME
Modules | 1 | M2 | MECH_G4_PLASTIC_BOTTOM |  | NULL |  | MECH_G4_PLASTIC_BOTTOM NULL | 92 | 1 | 500 | 549 | 549 | 274500 |  | Modules | 1 | M2 | MECH_G4_PLASTIC_BOTTOM | NULL | Starrapid | MECH_G4_PLASTIC_BOTTOM | China | 0 | China
Modules | 1 | M3 | MECH_G4_PLASTIC_TOP |  | NULL |  | MECH_G4_PLASTIC_TOP NULL | 94 | 1 | 500 | 422 | 422 | 211000 |  | Modules | 1 | M3 | MECH_G4_PLASTIC_TOP | NULL | Starrapid | MECH_G4_PLASTIC_TOP | China | 0 | China
Modules | 8 | M4-M5,M10-M13,M16-M17 | MECH_4X10MM_MAGNET_DIA |  | NULL |  | MECH_4X10MM_MAGNET_DIA NULL | 83 | 8 | 4000 | 84 | 672 | 336000 |  | Modules | 8 | M4-M5,M10-M13,M16-M17 | MECH_4X10MM_MAGNET_DIA | NULL | MagnetPlanet | R-4-10N45D | MagnetPlanet | https://magnetplanet.eu/index.php?oldal=magnes_adatlap&cikkszam=R-4-10N45D&tipus=Elemi%20magnesek | MagnetPlanet
Modules | 4 | M6-M9 | MECH_10X1MM_RUBBER_PAD |  | NULL |  | MECH_10X1MM_RUBBER_PAD NULL | 81 | 4 | 2000 | 10 | 40 | 20000 |  | Modules | 4 | M6-M9 | MECH_10X1MM_RUBBER_PAD | NULL | ??? | MECH_10X1MM_RUBBER_PAD | Alibaba | https://www.alibaba.com/product-detail/3M-silicon-pad-high-adhesive-bumpon_60397139143.html | Alibaba
Modules | 1 | M19 | MECH_FRONTPANEL_P16 |  | NULL |  | MECH_FRONTPANEL_P16 NULL | 100 | 1 | 500 | 2280 | 2280 | 1140000 |  | Modules | 1 | M19 | MECH_FRONTPANEL_P16 | NULL | Gravometal | MECH_FRONTPANEL_P16 | HU | 0 | HU
Modules | 16 | M20-M35 | MECH_LED_LIGHTPIPE |  | NULL |  | MECH_LED_LIGHTPIPE NULL | 87 | 16 | 8000 | 15 | 240 | 120000 |  | Modules | 16 | M20-M35 | MECH_LED_LIGHTPIPE | NULL | HGOK | MECH_LED_LIGHTPIPE | Alibaba | https://hgok.en.alibaba.com/?spm=a2700.8304367.topnav.1.3a8a413c3b7KPx | Alibaba
Modules | 16 | M36-M51 | MECH_POT_CAP |  | NULL |  | MECH_POT_CAP NULL | 89 | 16 | 8000 | 49 | 784 | 392000 |  | Modules | 16 | M36-M51 | MECH_POT_CAP | NULL | Chia Shin | CR-R4-7C6-270D | Chia Shin | http://www.chiashinknobs.com.tw/ | Chia Shin
Modules | 1 | M52 | MECH_G4_PCB |  | NULL |  | MECH_G4_PCB NULL | 96 | 1 | 500 | 577 | 577 | 288500 |  | Modules | 1 | M52 | MECH_G4_PCB | NULL | PCBWay | MECH_G4_PCB | China | 0 | China
 |  |  |  |  |  |  |  | #N/A | 0 | 0 | 0 | 0 | 0 |  | 0 | 0 | 0 | 0 | 0 | #N/A | #N/A | #N/A | #N/A | #N/A
Integrated Circuits | 8 | U3,U7 | USBLC6-2 | USBLC6-2SC6 | SUPERSOT-6 |  | USBLC6-2 SUPERSOT-6 | 76 | 8 | 4000 | 63.44 | 507.52 | 253760 |  | Integrated Circuits | 8 | U3,U7 | USBLC6-2 | SUPERSOT-6 | ON Semiconductor | USBLC6-2SC6 | Mouser | https://hu.mouser.com/ProductDetail/STMicroelectronics/USBLC6-2SC6 | Mouser
Integrated Circuits | 8 | U4,U8 | U OPAMP MCP6001 | MCP6001T-I/OT | SOT23-5 |  | U OPAMP MCP6001 SOT23-5 | 77 | 8 | 4000 | 51.67 | 413.36 | 206680 |  | Integrated Circuits | 8 | U4,U8 | U OPAMP MCP6001 | SOT23-5 | Microchip Technology | MCP6001T-I/OT | Mouser | https://hu.mouser.com/ProductDetail/Microchip-Technology/MCP6001T-I-OT | Mouser
Integrated Circuits | 8 | U5-U6 | U HALL DRV5053 | DRV5053OAQLPGM | TS9011 SOT23 |  | U HALL DRV5053 TS9011 SOT23 | 79 | 8 | 4000 | 114.12 | 912.96 | 456480 |  | Integrated Circuits | 8 | U5-U6 | U HALL DRV5053 | TS9011 SOT23 | Texas Instruments | DRV5053OAQDBZR | Mouser | https://hu.mouser.com/ProductDetail/595-DRV5053OAQDBZR | Mouser
Resistors | 32 | R1-R3,R6,R9-R12 | 10k |  | 0805_RES |  | 10k 0805_RES | 17 | 32 | 16000 | 1.794 | 57.408 | 28704 |  | Resistors | 32 | R1-R3,R6,R9-R12 | 10k | 0805_RES | ROYAL OHM | HP05W3J0103T5E | TME | https://www.tme.eu/en/details/hp05-10k5%25/0805-smd-resistors/royal-ohm/hp05w3j0103t5e/ | TME
Resistors | 16 | R4-R5,R7-R8 | 1k |  | 0805_RES |  | 1k 0805_RES | 19 | 16 | 8000 | 1.794 | 28.704 | 14352 |  | Resistors | 16 | R4-R5,R7-R8 | 1k | 0805_RES | ROYAL OHM | HP05W3J0102T5E | TME | https://www.tme.eu/en/details/hp05-1k5%25/0805-smd-resistors/royal-ohm/hp05w3j0102t5e/ | TME
Capacitors | 16 | C1-C4 | 100n |  | 0805_CAP |  | 100n 0805_CAP | 33 | 16 | 8000 | 6.21 | 99.36 | 49680 |  | Capacitors | 16 | C1-C4 | 100n | 0805_CAP | Yageo | CC0805ZRY5V9BB104 | Mouser | https://hu.mouser.com/ProductDetail/Yageo/CC0805ZRY5V9BB104?qs=sGAEpiMZZMvsSlwiRhF8qj9NgEuXmwzvSh6j0DMSg5Q%3d | Mouser
Transistors | 16 | Q1-Q4 | DMG1023UV-7 | DMG1023UV-7 | SUPERSOT-6 |  | DMG1023UV-7 SUPERSOT-6 | 106 | 16 | 8000 | 28 | 448 | 224000 |  | Transistors | 16 | Q1-Q4 | DMG1023UV-7 | SUPERSOT-6 | Diodes Incorporated | DMG1023UV-7 | Mouser | https://hu.mouser.com/ProductDetail/621-DMG1023UV-7 | Mouser
Miscellaneous | 64 | J1-J16 | J SPRINGPIN | TOBY_TEST-3 | N.F. |  | J SPRINGPIN N.F. | #N/A | 64 | 32000 | 0 | 0 | 0 |  | Miscellaneous | 64 | J1-J16 | J SPRINGPIN | N.F. | #N/A | #N/A | #N/A | #N/A | #N/A
Miscellaneous | 32 | J20-J27 | J POGO 1 |  | J POGO 1 |  | J POGO 1 J POGO 1 | 103 | 32 | 16000 | 30.8 | 985.6 | 492800 |  | Miscellaneous | 32 | J20-J27 | J POGO 1 | J POGO 1 | CFE | 0 | 0 | 0 | 0
Interface Board | QTY*4
 |  | TT Electronics |  |  | POT | P090S-04F20BR10K
 |  | TT Electronics |  |  | FADER | PS30-10MC1BR10K
 |  | TT Electronics |  |  | ENCODER | PEC12R-4020F-S0012
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

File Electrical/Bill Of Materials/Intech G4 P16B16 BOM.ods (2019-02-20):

Category | Qty. | References | Value | PCB Package | Manufacturer | Stock Code | Supplier Link
Capacitors | 56 | C1,C4-C10,C12,C14,C19-C20,C23-C24,C27-C28,C31-C51,C102-C103,C105,C200-C215 | 100n | 0805_CAP | Yageo | CC0805ZRY5V9BB104 | Mouser
Capacitors | 2 | C2-C3 | 22p | 0805_CAP | Samsung | CL21C220JBANNNC | TME
Capacitors | 2 | C11,C13 | 10u | 0805_CAP | Samsung | CL21A106KPFNNNE | TME
Capacitors | 10 | C15,C17-C18,C21-C22,C25-C26,C29-C30,C101 | 4.7u | 0805_CAP | Samsung | CL21A475KPFNNNG | TME
Capacitors | 3 | C16,C104,C106 | 1u | 0805_CAP | Samsung | CL21A105KOFNNNE | TME
Capacitors | 1 | C100 | 4.7n | 0805_CAP | Samsung | CL21B472KBANNNC | TME
Resistors | 5 | R1-R4,R101 | 0R | 0805_RES | ROYAL OHM | 0805S8J0000T5E | TME
Resistors | 60 | R5-R14,R18,R23-R32,R40-R49,R57-R66,R74-R91,R106 | 10k | 0805_RES | ROYAL OHM | HP05W3J0103T5E | TME
Resistors | 8 | R15-R16,R33-R34,R54-R55,R71-R72 | 100k | 0805_RES | ROYAL OHM | CQ05S8F1003T5E | TME
Resistors | 22 | R17,R19-R22,R35-R39,R50-R53,R56,R67-R70,R73,R202-R203 | 1k | 0805_RES | ROYAL OHM | HP05W3J0102T5E | TME
Resistors | 2 | R100,R102 | 1M | 0805_RES | ROYAL OHM | CQ05S8F1004T5E | TME
Resistors | 3 | R103-R105 | 4.7k | 0805_RES | ROYAL OHM | CQ05S8F4701T5E | TME
Integrated Circuits | 1 | U1 | AT SAM D5X/E5X (100PIN) | TQFP100 | Microchip Technology | ATSAMD51N20A-AUT | Mouser
Integrated Circuits | 8 | U2-U3,U6-U7,U10-U11,U14-U15 | U OPAMP MCP6001 | SOT23-5 | Microchip Technology | MCP6001T-I/OT | Mouser
Integrated Circuits | 9 | U4-U5,U8-U9,U12-U13,U16-U17,U101 | USBLC6-2 | SUPERSOT-6 | ON Semiconductor | USBLC6-2SC6 | Mouser
Integrated Circuits | 1 | U18 | U FLASH IS25LP016D | SO8 | ISSI | IS25LP016D-JNLE-TR | Mouser
Integrated Circuits | 2 | U19-U20 |  | SO16 | Nexperia | 74HC4051D,653 | Mouser
Integrated Circuits | 1 | U100 | FUSB303 | X2QFN12 | ON Semiconductor | FUSB303TMX | Mouser
Integrated Circuits | 2 | U102-U103 | NCV8161BSN330T1G | TSOP-5 | ON Semiconductor | NCV8161BSN330T1G | Mouser
Transistors | 4 | Q1,Q4,Q7,Q10 | DMP3085LSD-13 | SO8 | Diodes Incorporated | DMP3085LSD-13 | Mouser
Transistors | 8 | Q2-Q3,Q5-Q6,Q8-Q9,Q11-Q12 | DMN63D8LW-7 | SOT23 | Diodes Incorporated | DMN63D8LW-7 | Mouser
Diodes | 4 | D1-D4 | NSR0320MW2T1G | SOD-323 | ON Semiconductor | NSR0320MW2T1G | Mouser
Diodes | 8 | Z1-Z8 | 3V3 | MINIMELF | Nexperia | BZV55-C3V3.115 | TME
Miscellaneous | 3 | FB1,FB100-FB101 | 600R@100MHz | 0805_IND | TDK | MMZ2012R601A | TME
Miscellaneous | 56 | J1-J56 | J SPRINGPIN | J SPRINGPIN | Toby | TEST-3 | Toby
Miscellaneous | 1 | J100 | J USBTYPEC | J USBTYPEC 10133476-10001LF | Amphenol FCI | 10133476-10001LF | Mouser
Miscellaneous | 1 | J201 | J 2X8 | J 2X8 MINI SMT | CONNFLY | DS1065-05-2*8S8BS | TME
Miscellaneous | 1 | L1 | 10u | 0805_IND | TDK | MLZ2012N100LTD25 | Mouser
Miscellaneous | 16 | LD200-LD215 | WS2812B-MINI | PLCC4 | WORLDSEMI | WS2812B-MINI | TME
Miscellaneous | 1 | S1 | S PUSHBUTTON | S KMS221GLFS | C&K | KMS221G LFS | TME
Miscellaneous | 1 | X1 | 12Mhz | CRYSTAL ILCX13 | SR PASSIVES | 3225-12M-SR | TME
General tolerances:
Resistors | Thick film ±1% min 1/8W
Capacitors | MLCC ±10%, min 10V
Inductors | ±10%, min 300mA DC
Ferrites | ±10%, min 300mA DC

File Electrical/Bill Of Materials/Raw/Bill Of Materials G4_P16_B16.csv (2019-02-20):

Category | Quantity | References | Value | Stock Code | PCB Package
Integrated Circuits | 1 | U1 | AT SAM D5X/E5X (100PIN) | ATSAMD51N19 | TQFP100
Integrated Circuits | 1 | U2 | U FLASH IS25LP016D | IS25LP016D-JNLE-TR | SO8
Integrated Circuits | 2 | U3-U4 | 4051 | 74HC4051D | SO16
Integrated Circuits | 1 | U100 | FUSB303 | FUSB303TMX | X2QFN12
Integrated Circuits | 1 | U101 | USBLC6-2 | USBLC6-2SC6 | SUPERSOT-6
Integrated Circuits | 2 | U102-U103 | NCV8161BSN330T1G | NCV8161BSN330T1G | TSOP-5
Resistors | 3 | R1-R2,R101 | 0R |  | 0805_RES
Resistors | 20 | R3,R6,R8,R21-R36,R106 | 10k |  | 0805_RES
Resistors | 10 | R11-R20 | 1k |  | 0805_RES
Resistors | 2 | R100,R102 | 1M |  | 0805_RES
Resistors | 3 | R103-R105 | 4.7k |  | 0805_RES
Capacitors | 48 | C1,C4-C10,C12,C14,C17-C51,C102-C103,C105 | 100n |  | 0805_CAP
Capacitors | 2 | C2-C3 | 22p |  | 0805_CAP
Capacitors | 2 | C11,C13 | 10u |  | 0805_CAP
Capacitors | 2 | C15,C101 | 4.7u |  | 0805_CAP
Capacitors | 3 | C16,C104,C106 | 1u |  | 0805_CAP
Capacitors | 1 | C100 | 4.7n |  | 0805_CAP
Transistors | 8 | Q1-Q8 | DMP3085LSD-13 | DMP3085LSD-13 | SO8
Diodes | 8 | D1-D8 | NSR0320MW2T1G | NSR0320MW2T1G | SOD-323
Miscellaneous | 3 | FB1,FB100-FB101 | 600R@100MHz |  | 0805_IND
Miscellaneous | 64 | J4-J67 | J SPRINGPIN | TOBY_TEST-3 | J SPRINGPIN
Miscellaneous | 1 | J68 | J 2X8 |  | J 2X8 MINI SMT
Miscellaneous | 1 | J100 | J USBTYPEC |  | J USBTYPEC 10133476-10001LF
Miscellaneous | 1 | L1 | 10u |  | 0805_IND
Miscellaneous | 16 | LD1-LD16 | WS2812B-MINI | WS2812B-MINI | PLCC4
Miscellaneous | 1 | S1 | S PUSHBUTTON |  | S KMS221GLFS
Miscellaneous | 16 | VR1-VR16 | POT-SW-COMBO |  | POT-SW-COMBO
Miscellaneous | 1 | X1 | 12Mhz | 3225-12M-SR | CRYSTAL ILCX13
Modules | 4 | M1,M14-M15,M18 | MECH_B2,2X14_SELFT |  | NULL
Modules | 1 | M2 | MECH_G4_PLASTIC_BOTTOM |  | NULL
Modules | 1 | M3 | MECH_G4_PLASTIC_TOP |  | NULL
Modules | 8 | M4-M5,M10-M13,M16-M17 | MECH_4X10MM_MAGNET_DIA |  | NULL
Modules | 4 | M6-M9 | MECH_10X1MM_RUBBER_PAD |  | NULL
Modules | 1 | M19 | MECH_FRONTPANEL_P16 |  | NULL
Modules | 16 | M20-M35 | MECH_LED_LIGHTPIPE |  | NULL
Modules | 16 | M36-M51 | MECH_POT_CAP |  | NULL
Modules | 1 | M52 | MECH_G4_PCB |  | NULL

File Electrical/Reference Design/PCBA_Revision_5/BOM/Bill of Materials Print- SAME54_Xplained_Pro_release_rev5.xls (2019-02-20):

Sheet: Part List Report
 | Component list |  | Top Level Schematics
 | Source Data From: |  | SAM_E54_Xplained_Pro.PrjPCB
 | Project: |  | SAM_E54_Xplained_Pro.PrjPCB
 | Variant: |  | Default_assembly
 | Report Date: | 16.02.2017 | 12:26:15
 | Print Date: | 16.02.2017 | 12:13:09
# | Designator | Quantity | Value | Manufacturer | MPN | Description
1 | C100, C101, C102, C202, C501, C1201, C1203 | 7 | 4.7uF | WALSIN Technology Corporation | 0603X475K100CT | Ceramic capacitor, SMD 0603, X5R, 10V, 10% (de31036)
2 | C103, C105, C601, C604 | 4 | 22u/10V | Murata | GRM188R61A226ME15D | Ceramic capacitor, SMD 0603, X5R,10V, Â±20%
3 | C104 | 1 | 10n | YAGEO CORP | CC0402KRX7R8BB103 | Ceramic capacitor, SMD 0402, X7R, 25V, +/-10%
4 | C200 | 1 | 4.7n | PHYCOMP | 2238 587 15632 | Ceramic capacitor, SMD 0402, X7R, 25V, +/-10% (de35287)
5 | C201, C203, C204, C205, C207, C208, C209, C210, C211, C212, C213, C214, C215, C216, C502, C503, C600, C603, C605, C606, C607, C613, C700, C701, C703, C705, C806, C810, C811, C812, C813, C1100, C1101, C1104, C1107, C1200, C1204 | 37 | 100n | Kemet | C0402C104K4RACTU | Ceramic capacitor, SMD 0402, X7R, 16V, +/-10%
6 | C206, C217, C704 | 3 | 10uF/10V | AVX | 0603ZD106MAT2A | Ceramic capacitor, SMD 0603, X5R, 10V, 10UF Â± 20%
7 | C300, C301 | 2 | 6.8p | YAGEO CORP | CC0402CRNPO9BN6R8 | Ceramic capacitor, SMD 0402, NP0, 50V, +/-5%
8 | C302, C303 | 2 | 5pF | Murata | GRM1555C1H5R0CA01D | Ceramic capacitor, SMD 0402, NP0, 50V, +/-0.25pF
9 | C304 | 1 | 47mF | Kemet | FC0H473ZFTBR24 | Electric Double-Layer (Supercapacitor), 5.5V, 47mF, SMD, 10.5mm diameter, 50Î© ESR
10 | C500 | 1 | 4.7uF | Murata | GRM21BR61E475KA12L | Ceramic capacitor, SMD 0805, X5R, 25V, Â±10 %
11 | C602, C609 | 2 | 12p | Kemet | C0402C120J5GAC7867 | Ceramic capacitor, SMD 0402, NP0, 50V, +/-5%
12 | C608, C807, C809, C814, C815 | 5 | 2.2uF | Kemet | C0402C225M9PAC | Ceramic capacitor, SMD 0402, X5R, 6.3V, +/-20%
13 | C800, C801 | 2 | 15p | AVX | 04025A150JAT2A | Ceramic capacitor, SMD 0402, NP0, 50V, +/-5%
14 | C802, C803, C808, C1106 | 4 | 1 nF C0G | Murata | GRM1555C1H102JA01D | Ceramic capacitor, SMD 0402, C0G, 50V, +/-5%
15 | C804 | 1 | 10p | AVX | 04025A100JAT2A | Ceramic capacitor, SMD 0402, NP0, 50V, +/-5%
16 | C1102, C1103 | 2 | 1u | Kemet | C0402C105K9PAC | Ceramic capacitor, SMD 0402, X5R, 6.3V, +/-10% (de26942)
17 | C1105 | 1 | 33n | Murata | GRM155R71E333KA88D | Ceramic capacitor, SMD 0402, X7R, 25V, ±10%
18 | C1202, C1206 | 2 | 150p | YAGEO CORP | CC0402KRX7R9BB151 | Ceramic capacitor, SMD 0402, X7R, 50V, +/-10%
19 | D300, D801 | 2 | SML-P11YT | ROHM | SML-P11YT-T86 | LED, SMD 0402, Yellow, Wave length=586nm, 7.6mcd @ (1mA, 1.9Vf)
20 | D301, D802 | 2 | EMI2121MTTAG | ON Semiconductor | EMI2121MTTAG | EMI2121, SZEMI2121 Single Pair Common Mode Filter with ESD Protection
21 | D800 | 1 | SML-P11MT | ROHM | SML-P11MT-T86 | LED, SMD 0402, Green, Wave length=569nm, 2.1mcd @ (1mA, 1.9Vf)
22 | E1, E2, E3, E4 | 4 | SJ-5076 | 3M | SJ-5076 | 2.8mm adhesive feet,diam 8.0mm
23 | FIXTURE1 | 1 | Xplained PRO MCU board Jupiter Test Fixture | ESCATEC | Xplained PRO MCU board Jupiter Test Fixture | Xplained PRO MCU board Jupiter Test Fixture
24 | FW1 | 1 | EDBG secured firmware | ATMEL |  | EDBG secured firmware
25 | J100, J102, J302 | 3 | HMTSW-103-23-F-S-237 | SAMTEC | HMTSW-103-23-F-S-237 | 1x3 pin header, 2.54mm pitch, Pin-in-Paste THM, 1mm hole
26 | J103 | 1 | Pin header 1x2 right angle | Pro-data International Corp | 2213R-2G | 1x2 pin header, right angle, 2.54 mm pitch, through-hole
27 | J303, J800 | 2 | ZX62D-AB-5P8 | HIROSE | ZX62D-AB-5P8(30) | Micro USB AB Connector, Standard SMT + DIP
28 | J400 | 1 | P101-2*02RGF-139-ND | Pro-data International Corp | P101-2*02RGF-139-ND | Pin header, 2x2, Right Angle, 2.54mm, THT, Pin In Paste
29 | J401, J402, J403 | 3 | P101-2*10RGF-139-ND | Pro-data International Corp | P101-2*10RGF-139-ND | Pin header, 2x10, Right Angle, 2.54mm, THM, Pin In Paste
30 | J404 | 1 | PIN HEADER 2x5 | Garry | 176-2-010-0-T-XS0-0730 | 2x5 pin header, 1.27mm pitch, THM
31 | J405 | 1 | FTSH-110-01-F-DV-007-K | SAMTEC | FTSH-110-01-F-DV-007-K | SAMTEC FTSH series 50-mil header, shrouded, pin 7 removed, SMD
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

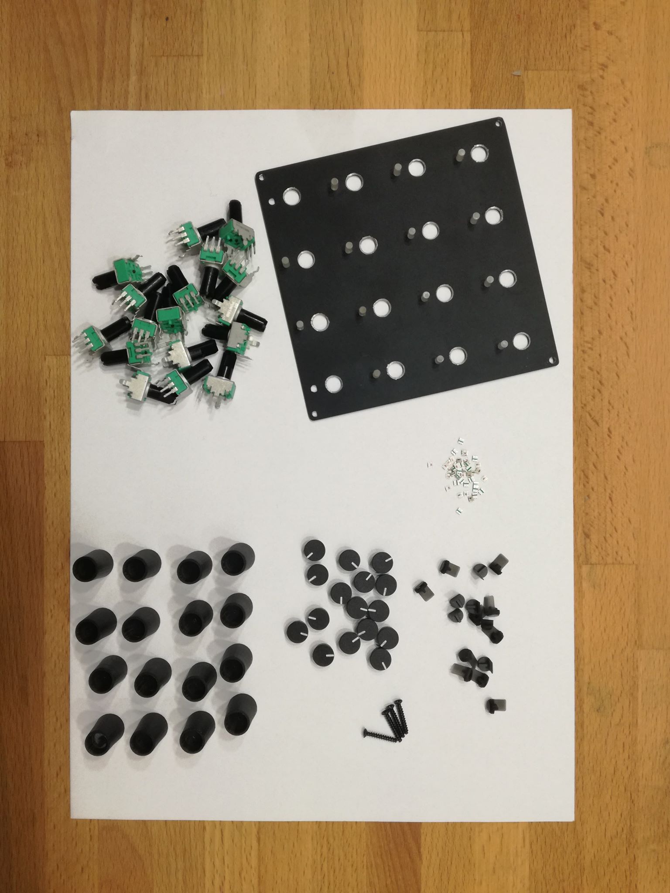
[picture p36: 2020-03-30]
Electrical/Bill Of Materials/Photos/ui.jpg

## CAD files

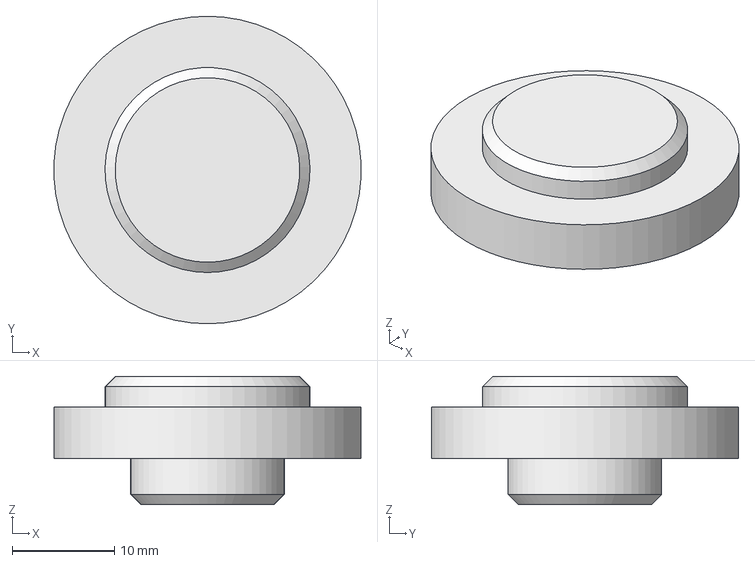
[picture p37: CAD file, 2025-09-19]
Manufacturing/manufacturing_jigs/KNOB-TEK2_assembly_tool_v2.step
30.0 x 30.0 x 12.5 mm

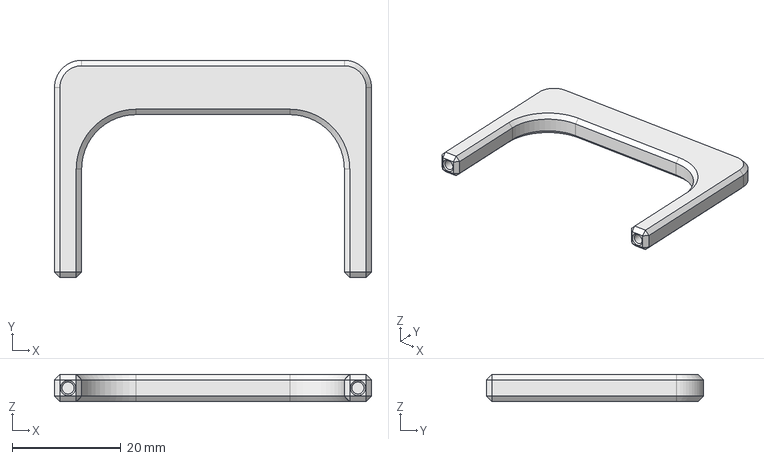
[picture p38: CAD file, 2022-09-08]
Mechanical/Experiment/DisassemblyTool/DisassemblyTool.FCStd
58.3 x 40.0 x 5.00 mm

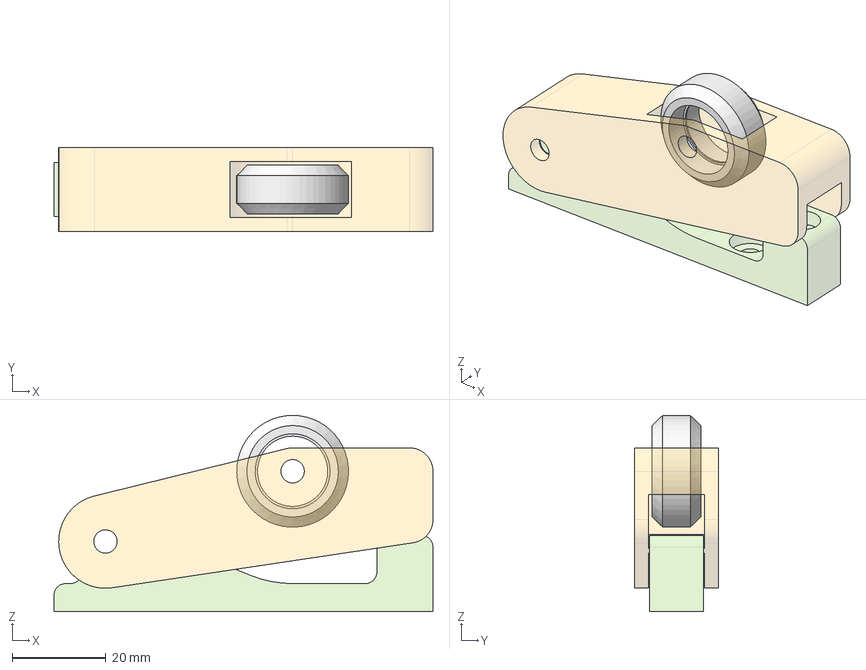
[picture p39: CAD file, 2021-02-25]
Manufacturing/Fumefood/wheel_assembly.FCStd
81.0 x 18.0 x 42.0 mm

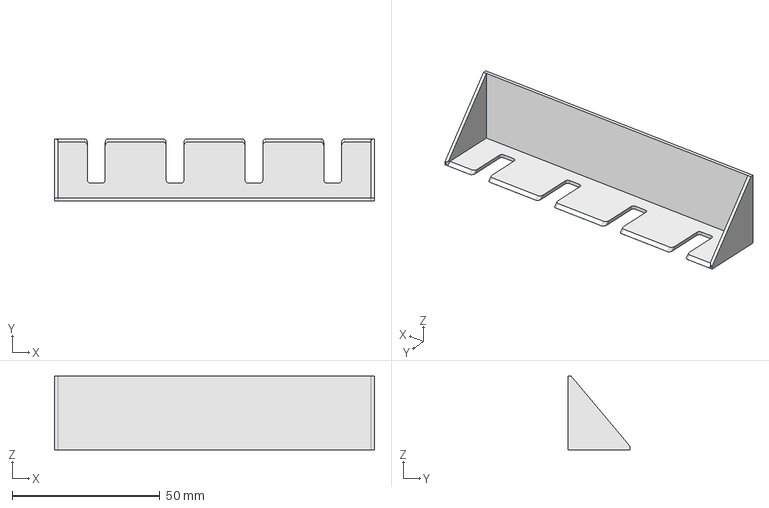
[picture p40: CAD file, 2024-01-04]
Manufacturing/QC_jigs/fader_assembly_jig.FCStd
108.3 x 21.2 x 25.0 mm

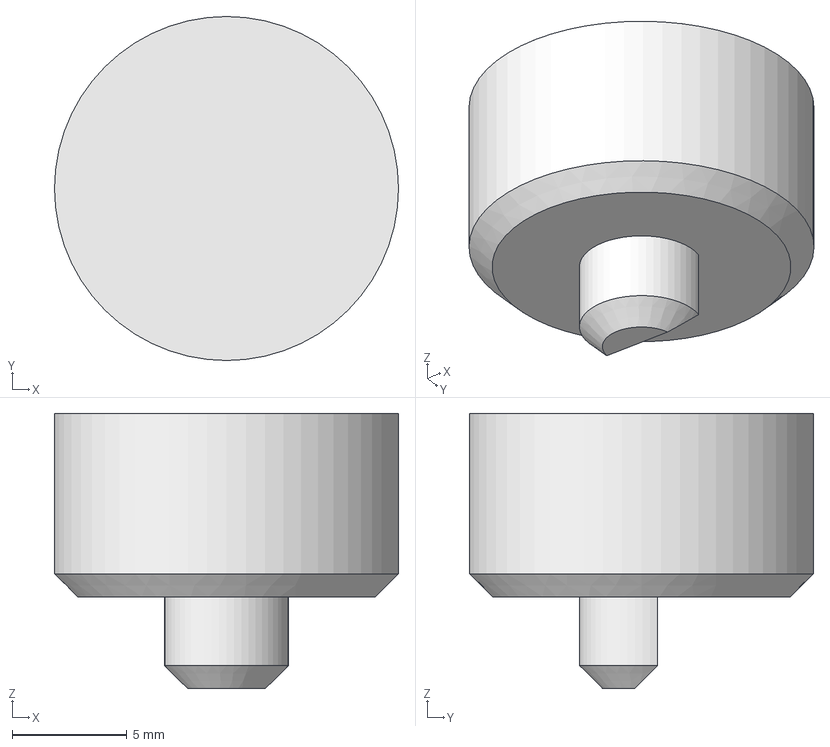
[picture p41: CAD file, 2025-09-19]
Manufacturing/manufacturing_jigs/KNOB-TEK2_assembly_tool.step
15.0 x 15.0 x 12.0 mm

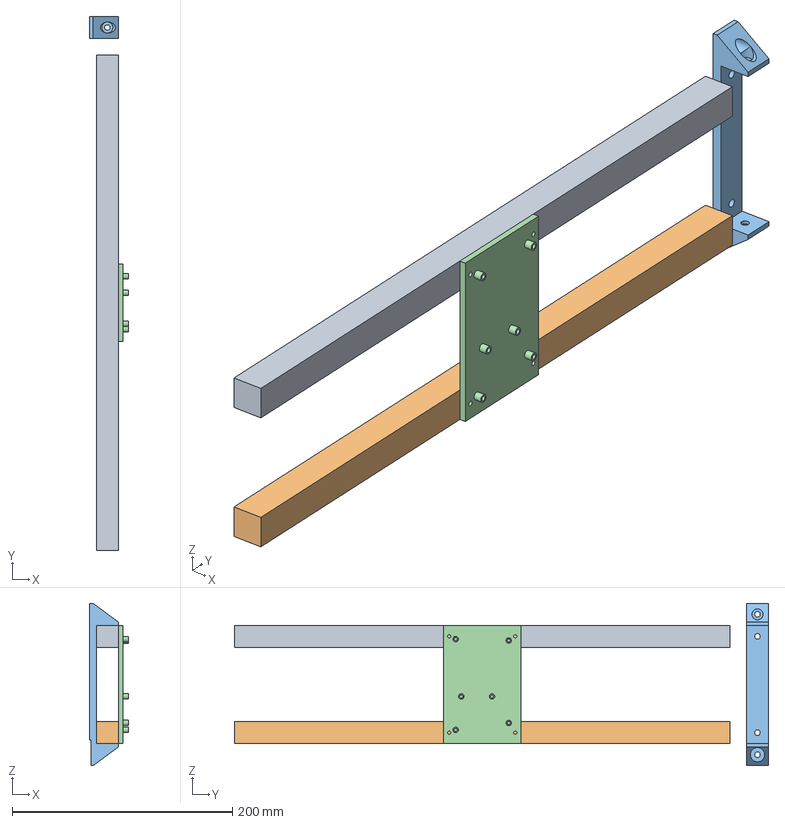
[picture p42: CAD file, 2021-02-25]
Manufacturing/CNC/Electronics/cnc_electronics_asm.FCStd
35.0 x 485.0 x 147.5 mm
Bracket
Mega_Mount

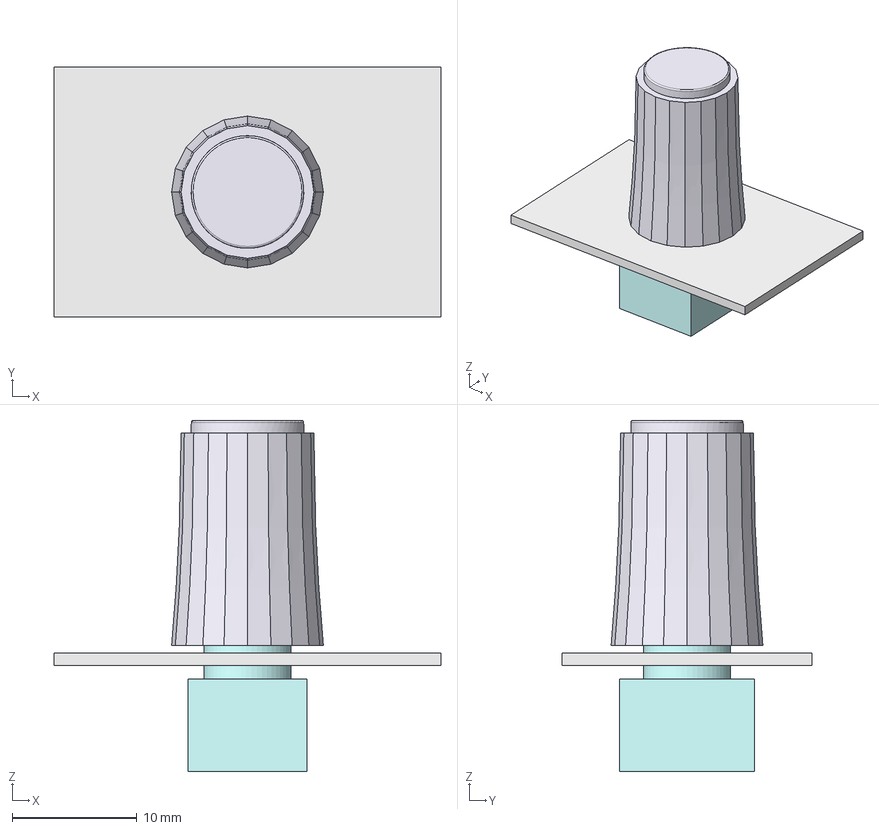
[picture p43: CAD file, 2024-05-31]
Mechanical/Design/PLASTIC-KNOB-POT/POT-ASSY.FCStd
31.0 x 20.0 x 28.1 mm
pcba-pot-RK0952N_001
PLASTIC-KNOB-POT másolata_001

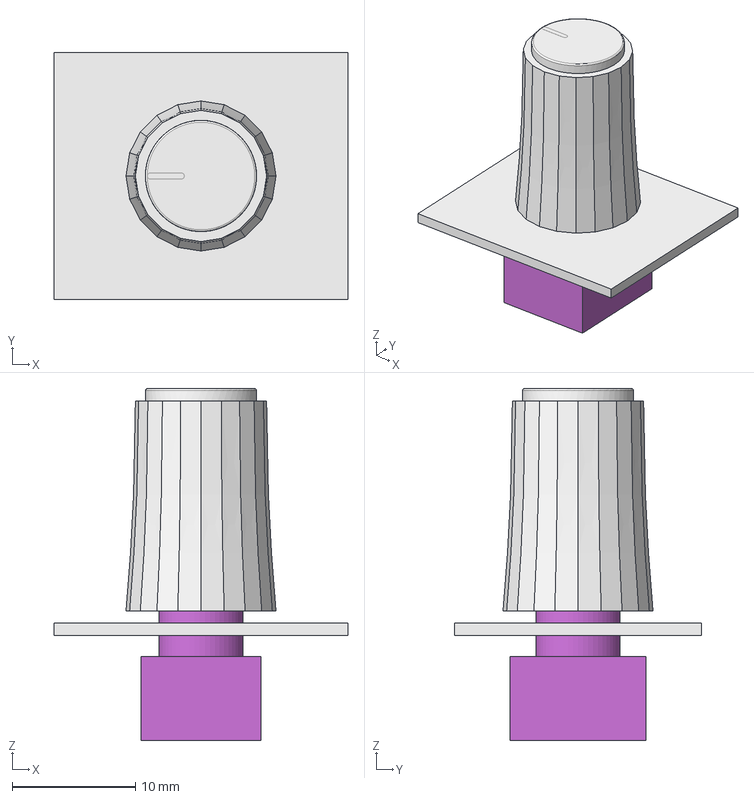
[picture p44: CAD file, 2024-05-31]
Mechanical/Design/PLASTIC-KNOB-POT/POT-ASSY_actual.FCStd
23.8 x 20.0 x 28.5 mm
pcba-pot-R0903N_001
PLASTIC-KNOB-POT_001

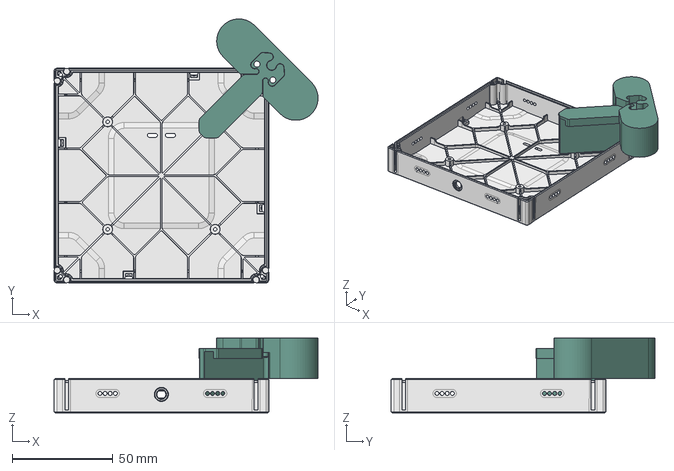
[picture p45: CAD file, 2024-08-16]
Manufacturing/manufacturing_jigs/magnet_press_jig_2 part_assy_v3.FCStd
131.0 x 131.0 x 37.0 mm
PLASTIC-CANVAS_001
magnet_press_jig_side_2 part_v3_001

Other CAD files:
Mechanical/Assembly/ASSEMBLY-CANVAS.FCStd
Manufacturing/manufacturing_jigs/KNOB-TEK2_assembly_tool_assy.FCStd
Mechanical/Assembly/ASSEMBLY-EF44-FRONTPANEL.FCStd
Mechanical/Assembly/ASSEMBLY-TEK2-FRONTPANEL.FCStd
Mechanical/Assembly/ASSEMBLY-VSN1-PCB-TEK2.FCStd
Mechanical/Assembly/ASSEMBLY-VSN1-PCB-RIGHT.FCStd
Mechanical/Assembly/ASSEMBLY-VSN1-FRONTPANEL-LEFT.FCStd
Manufacturing/Fumefood/fumehood1200_asm.FCStd
Mechanical/Assembly/ASSEMBLY-TEK2.FCStd
Electrical/Experiments/# Legacy/FFC/FFC/FFC.step
Electrical/Experiments/# Legacy/G4_Interface/Render/InterfaceBoard.STEP
Electrical/Experiments/# Legacy/G4_Interface/Render/InterfaceBoard2.STEP
Electrical/Experiments/# Legacy/G4_Interface/Render/InterfaceBoard4.STEP
Electrical/Experiments/# Legacy/G4_Interface/Source/InterfaceBoard2.STEP
Electrical/Experiments/# Legacy/G4_Interface/Source/InterfaceBoard2_A.STEP
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

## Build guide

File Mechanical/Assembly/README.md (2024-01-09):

## Used addons for assembly

[A2plus Workbench](https://wiki.freecad.org/A2plus_Workbench)

---

## Installing

It can easily be installed via the FreeCAD Addon Manager from the Tools/Addon Manager menu.

---

## Getting Started

To create an assembly create a new file in FreeCAD. At first this file needs to be saved. It is recommended (but not necessary) to save it in the same folder of the parts you want to assemble.

Now external parts can be added to the assembly by using the toolbar with the "Part icons with a plus sing". The button adds all bodies in the selected file as a single part. When using the button you can choose what part from a file should be imported as part. This way one can for example only import a sketch to assemble further parts using the sketch to determine the part positions.

The first added part gets a fixed position by default. (You can change this later via the part property)

Parts that are already in the assembly can be cloned with the "2 Part icon" button .

To edit a part from the assembly, select it in the model tree and use the "Part icon with a pencil" button . This will open the part into a new tab in FreeCAD or switch to its tab if the file is already opened.

To update changed parts in assemblies click on the "Part with a recycle sign" button. If you select one or some parts in FreeCAD's the tree view, A2plus will ask you to only update the selected parts.

Imported parts will keep their external dependencies and can be edited. For well-defined parts like screws it is however useful that their shape cannot be edited. This can be achieved with the "Yellow and red part icons" button that converts the selected part to a static copy of the original part.

Toggling the "Mouse" button sets the way you can select several several edges, faces etc.: Either with a single click or by Ctrl+click. 

---

## Assembling

Assembling parts is done by adding constraints between parts. After a constraint A2plus will move the parts according to the constraint if possible.

To create a constraint between parts, keep the Ctrl key pressed and select each an edge or face of two parts. Then click the toolbar button of the desired constraint. A dialog will pop up that is descried in section Constraints. The constraint will be added in the model tree attached to the affected parts.

For complex constraints between parts A2plus might fail to solve the constraints. Therefore also have a look at section Troubleshooting for strategies to resolve such cases. 

You can get to know each constrain [here](https://wiki.freecad.org/A2plus_Workbench).

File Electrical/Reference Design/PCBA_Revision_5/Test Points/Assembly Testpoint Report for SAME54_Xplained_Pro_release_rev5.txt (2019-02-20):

Net         Name        X Coord     Y Coord     Side        Hole Size   Type        
PD12_ETH_IRQFree-0      -68.5381mm  -38.0548mm  Bottom          0.65mm  Through hole
PC21_ETH_RESETFree-0       -71.225mm   -47.025mm  Bottom          0.65mm  Through hole
PC20_ETH_GRXDVFree-0      -70.0875mm   -36.225mm  Bottom          0.65mm  Through hole
PB31_USER_BTN_DGI3Free-0      -31.6551mm   -36.325mm  Bottom          0.65mm  Through hole
PB24_S2P1_UART_RXFree-0        -32.66mm    -37.78mm  Bottom          0.65mm  Through hole
PB25_S2P0_UART_TXFree-0        -33.93mm    -37.78mm  Bottom          0.65mm  Through hole
PC19_USB_ID Free-0       -42.025mm   -56.375mm  Bottom          0.65mm  Through hole
PD01_EDBG_SPI_SSFree-0         -20.8mm  -37.7768mm  Bottom          0.65mm  Through hole
PC00_USB_VBUSFree-0       -33.025mm   -45.525mm  Bottom          0.65mm  Through hole
RCT         J600-5        -70.96mm   -17.925mm  Bottom         0.889mm  Through hole
TX_P        J600-1        -65.88mm   -17.925mm  Bottom         0.889mm  Through hole
RX_P        J600-3        -68.42mm   -17.925mm  Bottom         0.889mm  Through hole
TCT         J600-4        -69.69mm   -20.465mm  Bottom         0.889mm  Through hole
TX_N        J600-2        -67.15mm   -20.465mm  Bottom         0.889mm  Through hole
RX_N        J600-6        -72.23mm   -20.465mm  Bottom         0.889mm  Through hole
RJ45_GND    J600-8        -74.77mm   -20.465mm  Bottom         0.889mm  Through hole
PC15_ETH_LEDJ600-12     -76.9544mm    -7.511mm  Bottom         1.016mm  Through hole
NetJ600_9   J600-9      -63.6956mm    -7.511mm  Bottom         1.016mm  Through hole
NetJ600_11  J600-11     -74.4144mm    -7.511mm  Bottom         1.016mm  Through hole
PHY_LED0    J600-10     -66.2356mm    -7.511mm  Bottom         1.016mm  Through hole
PD21_SDHC_WPFree-0       -48.325mm     -59.4mm  Bottom          0.65mm  Through hole
PB20_SDHC_DATA2Free-0       -48.325mm    -82.53mm  Bottom          0.65mm  Through hole
PB21_SDHC_DATA3Free-0       -48.325mm    -80.03mm  Bottom          0.65mm  Through hole
PA20_SDHC_CMDFree-0       -48.325mm    -77.53mm  Bottom          0.65mm  Through hole
PA21_SDHC_CKFree-0       -48.325mm    -70.03mm  Bottom          0.65mm  Through hole
PB18_SDHC_DATA0Free-0       -48.325mm     -65.1mm  Bottom          0.65mm  Through hole
PB19_SDHC_DATA1Free-0       -48.325mm     -63.4mm  Bottom          0.65mm  Through hole
PD20_SDHC_CDFree-0       -48.325mm     -61.4mm  Bottom          0.65mm  Through hole
SHIELD      J800-9       -17.825mm      -4.8mm  Bottom          0.65mm  Through hole
PC31_GPIO_SPI_SS_BJ403-10       -28.73mm    -95.57mm  Bottom             1mm  Through hole
PC03_ADC1_AIN5J403-4        -21.11mm    -95.57mm  Bottom             1mm  Through hole
PC02_ADC1_AIN4J403-3        -21.11mm    -93.03mm  Bottom             1mm  Through hole
PC10_GPIO   J403-6        -23.65mm    -95.57mm  Bottom             1mm  Through hole
PC01_GPIO   J403-5        -23.65mm    -93.03mm  Bottom             1mm  Through hole
PD11_TCC0_WO4J403-8        -26.19mm    -95.57mm  Bottom             1mm  Through hole
PD10_TCC0_WO3J403-7        -26.19mm    -93.03mm  Bottom             1mm  Through hole
PC30_GPIO_EXTINT14J403-9        -28.73mm    -93.03mm  Bottom             1mm  Through hole
PC14_EXT3_SPI_SSJ403-15       -36.35mm    -93.03mm  Bottom             1mm  Through hole
PC23_S1P1_UART_RXJ403-13       -33.81mm    -93.03mm  Bottom             1mm  Through hole
PC22_S1P0_UART_TXJ403-14       -33.81mm    -95.57mm  Bottom             1mm  Through hole
ID3         J403-1        -18.57mm    -93.03mm  Bottom             1mm  Through hole
NetJ100_3   J100-3       -36.696mm    -14.76mm  Bottom             1mm  Through hole
VCC_CM_IN_P3V3J102-1       -41.776mm    -19.84mm  Bottom             1mm  Through hole
ID2         J402-1         -6.97mm    -64.29mm  Bottom             1mm  Through hole
PD08_S7P0_I2C_SDAJ402-11        -6.97mm    -76.99mm  Bottom             1mm  Through hole
PD09_S7P1_I2C_SCLJ402-12        -4.43mm    -76.99mm  Bottom             1mm  Through hole
PB16_S5P0_UART_TXJ402-14        -4.43mm    -79.53mm  Bottom             1mm  Through hole
PB17_S5P1_UART_RXJ402-13        -6.97mm    -79.53mm  Bottom             1mm  Through hole
PC04_S6P0_SPI_MOSIJ402-16        -4.43mm    -82.07mm  Bottom             1mm  Through hole
PC06_S6P2_SPI_SSJ402-15        -6.97mm    -82.07mm  Bottom             1mm  Through hole
PC05_S6P1_SPI_SCKJ402-18        -4.43mm    -84.61mm  Bottom             1mm  Through hole
PC07_S6P3_SPI_MISOJ402-17        -6.97mm    -84.61mm  Bottom             1mm  Through hole
PD00_GPIO_EXTINT0J402-9         -6.97mm    -74.45mm  Bottom             1mm  Through hole
PB14_TCC4_WO0J402-7         -6.97mm    -71.91mm  Bottom             1mm  Through hole
PB15_TCC4_WO1J402-8         -4.43mm    -71.91mm  Bottom             1mm  Through hole
PB01_GPIO   J402-5         -6.97mm    -69.37mm  Bottom             1mm  Through hole
PB06_GPIO   J402-6         -4.43mm    -69.37mm  Bottom             1mm  Through hole
PB00_ADC0_AIN12J402-3         -6.97mm    -66.83mm  Bottom             1mm  Through hole
PA03_ADC0_AIN1J402-4         -4.43mm    -66.83mm  Bottom             1mm  Through hole
PB02_GPIO_SPI_SS_BJ402-10        -4.43mm    -74.45mm  Bottom             1mm  Through hole
TARGET_RESETNJ404-10        -8.24mm    -23.01mm  Bottom          0.65mm  Through hole
PA31_SWDIO  J404-2         -3.16mm    -23.01mm  Bottom          0.65mm  Through hole
PA30_SWCLK  J404-4         -4.43mm    -23.01mm  Bottom          0.65mm  Through hole
PB30_SWO    J404-6          -5.7mm    -23.01mm  Bottom          0.65mm  Through hole
NetJ102_2   J103-2        -38.73mm    -10.95mm  Bottom             1mm  Through hole
VCC_MCU_P3V3J103-1        -41.27mm    -10.95mm  Bottom             1mm  Through hole
ID1         J401-1         -6.97mm    -28.73mm  Bottom             1mm  Through hole
PA22_S3P0_I2C_SDAJ401-11        -6.97mm    -41.43mm  Bottom             1mm  Through hole
PA23_S3P1_I2C_SCLJ401-12        -4.43mm    -41.43mm  Bottom             1mm  Through hole
PA04_S0P0_UART_TXJ401-14        -4.43mm    -43.97mm  Bottom             1mm  Through hole
PA05_S0P1_UART_RXJ401-13        -6.97mm    -43.97mm  Bottom             1mm  Through hole
PB27_S4P0_SPI_MOSIJ401-16        -4.43mm    -46.51mm  Bottom             1mm  Through hole
PB28_S4P2_SPI_SSJ401-15        -6.97mm    -46.51mm  Bottom             1mm  Through hole
PB26_S4P1_SPI_SCKJ401-18        -4.43mm    -49.05mm  Bottom             1mm  Through hole
PB29_S4P3_SPI_MISOJ401-17        -6.97mm    -49.05mm  Bottom             1mm  Through hole
PB07_GPIO_EXTINT7J401-9         -6.97mm    -38.89mm  Bottom             1mm  Through hole
PB08_TC4_WO0J401-7         -6.97mm    -36.35mm  Bottom             1mm  Through hole
PB09_TC4_WO1J401-8         -4.43mm    -36.35mm  Bottom             1mm  Through hole
PA06_GPIO_S0P2_RTSJ401-5         -6.97mm    -33.81mm  Bottom             1mm  Through hole
PA07_GPIO_S0P3_CTSJ401-6         -4.43mm    -33.81mm  Bottom             1mm  Through hole
PB04_ADC1_AIN6J401-3         -6.97mm    -31.27mm  Bottom             1mm  Through hole
PB05_ADC1_AIN7J401-4         -4.43mm    -31.27mm  Bottom             1mm  Through hole
PA27_GPIO_SPI_SS_BJ401-10        -4.43mm    -38.89mm  Bottom             1mm  Through hole
VCC_EXT_P5V0J400-1         -6.97mm    -13.49mm  Bottom             1mm  Through hole
VCC_P5V0    J400-3         -6.97mm    -16.03mm  Bottom             1mm  Through hole
VCC_TARGET_P3V3J400-4         -4.43mm    -16.03mm  Bottom             1mm  Through hole
CANH        J500-1         -77.7mm  -55.7825mm  Bottom             1mm  Through hole
CANL        J500-2         -77.7mm  -53.2425mm  Bottom             1mm  Through hole
VCC_SUPERCAPJ302-1       -23.575mm    -78.24mm  Bottom             1mm  Through hole
PB03_SUPER_CAPJ302-2       -23.575mm     -75.7mm  Bottom             1mm  Through hole
TARGET_USB_SHIELDJ303-6      -44.3465mm    -1.675mm  Bottom         0.825mm  Through hole
PB12_CAN1_TXFree-0       -62.325mm   -55.135mm  Bottom          0.65mm  Through hole
PB13_CAN1_RXFree-0       -62.325mm   -53.865mm  Bottom          0.65mm  Through hole
PC13_CAN_STBYFree-0       -62.325mm   -56.405mm  Bottom          0.65mm  Through hole
PA02_ADC0_AIN0_DAC0J408-1         -4.43mm    -56.67mm  Bottom             1mm  Through hole
QCS         Free-0       -20.725mm   -43.705mm  Bottom          0.65mm  Through hole
QIO1        Free-0       -20.725mm   -42.435mm  Bottom          0.65mm  Through hole
QIO2        Free-0       -20.725mm   -41.165mm  Bottom          0.65mm  Through hole
QIO3        Free-0       -31.425mm   -42.435mm  Bottom          0.65mm  Through hole
QSCK        Free-0       -31.425mm   -41.165mm  Bottom          0.65mm  Through hole
QIO0        Free-0       -31.425mm   -39.895mm  Bottom          0.65mm  Through hole
VCC_MCU_VDDIOBFree-0       -24.325mm   -50.275mm  Bottom          0.65mm  Through hole
PC18_PDEC2_DGI2_LEDJ407-3       -41.995mm   -44.245mm  Bottom             1mm  Through hole
PC17_PDEC1_DGI1J407-2       -39.455mm   -44.245mm  Bottom             1mm  Through hole
PC16_PDEC0_DGI0J407-1       -36.915mm   -44.245mm  Bottom             1mm  Through hole
NetJ406_9   J406-9        -64.73mm   -41.705mm  Bottom             1mm  Through hole
NetJ406_10  J406-10       -64.73mm   -44.245mm  Bottom             1mm  Through hole
PA14_ETH_GTXCKJ406-7        -62.19mm   -41.705mm  Bottom             1mm  Through hole
PA15_ETH_GRXERJ406-8        -62.19mm   -44.245mm  Bottom             1mm  Through hole
PA12_ETH_GRX1J406-5        -59.65mm   -41.705mm  Bottom             1mm  Through hole
PA13_ETH_GRX0J406-6        -59.65mm   -44.245mm  Bottom             1mm  Through hole
NetJ406_12  J406-12       -67.27mm   -44.245mm  Bottom             1mm  Through hole
PA18_ETH_GTX0J406-14       -69.81mm   -44.245mm  Bottom             1mm  Through hole
PA19_ETH_GTX1J406-13       -69.81mm   -41.705mm  Bottom             1mm  Through hole
PA16_PCC_D00_PTCXY10J406-16       -72.35mm   -44.245mm  Bottom             1mm  Through hole
PA17_ETH_GTXENJ406-15       -72.35mm   -41.705mm  Bottom             1mm  Through hole
PC11_ETH_GMDCJ406-20       -77.43mm   -44.245mm  Bottom             1mm  Through hole
PC12_ETH_GMDIOJ406-19       -77.43mm   -41.705mm  Bottom             1mm  Through hole
NetJ406_11  J406-11       -67.27mm   -41.705mm  Bottom             1mm  Through hole
NetR300_1   TP300-1          -33mm      -1.5mm  Bottom             0mm  Surface mount
VCC_P3V3    J101-2         -27.9mm    -12.15mm  Bottom             0mm  Surface mount
NetR201_1   TP200-1          -26mm      -1.5mm  Bottom             0mm  Surface mount
GND         TP800-1        -41.6mm      -1.5mm  Bottom             0mm  Surface mount
EDBG_FORCE_BOOTTP801-1        -38.6mm      -1.5mm  Bottom             0mm  Surface mount
EDBG_JTAG_TCKTP802-1        -41.6mm      -3.5mm  Bottom             0mm  Surface mount
EDBG_JTAG_TDITP803-1        -41.6mm      -5.5mm  Bottom             0mm  Surface mount
EDBG_JTAG_TDOTP804-1        -38.6mm      -5.5mm  Bottom             0mm  Surface mount
EDBG_JTAG_TMSTP805-1        -41.6mm      -7.5mm  Bottom             0mm  Surface mount
EDBG_RESET_NTP806-1        -38.6mm      -3.5mm  Bottom             0mm  Surface mount
VCC_EDBG_P3V3TP807-1        -38.6mm      -7.5mm  Bottom             0mm  Surface mount
NetQ100_5   Free-3       -15.675mm   -13.975mm  Bottom             0mm  Surface mount
CM_PA03_VREFAFree-3         -40.3mm   -39.425mm  Bottom             0mm  Surface mount
NetQ1001_3  Free-3      -44.2749mm   -21.725mm  Bottom             0mm  Surface mount
NetQ1000_3  Free-3      -40.2087mm     -21.3mm  Bottom             0mm  Surface mount
NetC100_1   Free-3       -29.525mm   -4.4235mm  Bottom             0mm  Surface mount
NetQ1200_2  Free-3        -46.83mm    -15.42mm  Bottom             0mm  Surface mount
NetC104_2   Free-3        -30.65mm     -7.75mm  Bottom             0mm  Surface mount
VCC_PRE_AMP_P5V0Free-3       -58.575mm    -17.85mm  Bottom             0mm  Surface mount
NetC1206_1  Free-3        -57.95mm   -24.175mm  Bottom             0mm  Surface mount
CM_PA15_GPIOFree-3      -50.6488mm  -27.1238mm  Bottom             0mm  Surface mount
NetQ1201_3  Free-3       -51.375mm   -21.175mm  Bottom             0mm  Surface mount
VCC_CM_CORE Free-3        -37.55mm    -33.35mm  Bottom             0mm  Surface mount
VCC_FILTER_P3V3Free-3       -52.625mm   -21.725mm  Bottom             0mm  Surface mount
NetC1202_1  Free-3        -56.15mm   -32.775mm  Bottom             0mm  Surface mount
NetQ900_2   Free-3       -48.125mm   -15.425mm  Bottom             0mm  Surface mount
NetQ1201_2  Free-3       -58.675mm   -21.575mm  Bottom             0mm  Surface mount
NetQ901_3   Free-3      -51.3361mm     -10.5mm  Bottom             0mm  Surface mount
NetC804_1   Free-3      -18.7574mm   -19.575mm  Bottom             0mm  Surface mount
NetQ800_6   Free-3          -2.8mm   -12.775mm  Bottom             0mm  Surface mount
NetQ800_3   Free-3        -2.575mm      -6.3mm  Bottom             0mm  Surface mount
NetQ1002_3  Free-3      -47.8499mm  -21.7001mm  Bottom             0mm  Surface mount
EDBG_SPI_DGI_SCKFree-3      -31.3798mm  -28.8247mm  Bottom             0mm  Surface mount
EDBG_SPI_DGI_MOSIFree-3      -30.1048mm  -28.8247mm  Bottom             0mm  Surface mount
EDBG_SPI_DGI_MISOFree-3      -28.8298mm  -28.8247mm  Bottom             0mm  Surface mount
EDBG_SPI_DGI_SSFree-3      -27.5548mm  -28.8247mm  Bottom             0mm  Surface mount
TARGET_RESET_SENSEFree-3      -26.2799mm  -28.8247mm  Bottom             0mm  Surface mount
CM_PA08_AIN16Free-3       -53.975mm     -33.5mm  Bottom             0mm  Surface mount
NetQ1201_1  Free-3      -56.5485mm    -20.95mm  Bottom             0mm  Surface mount
NetC807_1   Free-3       -24.525mm   -13.525mm  Bottom             0mm  Surface mount
NetC806_1   Free-3       -32.125mm    -17.25mm  Bottom             0mm  Surface mount
VCC_CM_VDDANAFree-3         -55.9mm     -34.3mm  Bottom             0mm  Surface mount
VREF_FB     Free-3       -48.575mm    -41.35mm  Bottom             0mm  Surface mount
NetQ104_2   Free-3         -20.9mm   -6.8262mm  Bottom             0mm  Surface mount
NetQ103_3   Free-3       -15.925mm     -10.2mm  Bottom             0mm  Surface mount
NetQ100_2   Free-3       -9.4464mm   -7.7786mm  Bottom             0mm  Surface mount
PHY_MDIO    Via            -73.6mm  -35.2165mm  Bottom          0.25mm  Through hole
PC27_TRACE_CLKVia           -34.96mm   -80.845mm  Bottom          0.25mm  Through hole
PC28_TRACE_DATA0Via           -36.23mm   -80.845mm  Bottom          0.25mm  Through hole
PC26_TRACE_DATA1Via            -37.5mm   -80.845mm  Bottom          0.25mm  Through hole
PC25_TRACE_DATA2Via           -38.77mm   -80.845mm  Bottom          0.25mm  Through hole
PC24_TRACE_DATA3Via           -40.04mm   -80.845mm  Bottom          0.25mm  Through hole
CM_PA14_GCLK0Via          -36.175mm    -32.65mm  Bottom          0.25mm  Through hole
CM_PA22_SERCOM3_PAD0_SPI_MOSIVia            -37.8mm   -32.075mm  Bottom          0.25mm  Through hole
CM_PA24_SERCOM3_PAD2_SPI_MISOVia           -38.13mm   -30.095mm  Bottom          0.25mm  Through hole
CM_PA23_SERCOM3_PAD1_SPI_SCKVia              -37mm   -30.825mm  Bottom          0.25mm  Through hole
CM_RESET_N  Via         -39.3269mm     -29.5mm  Bottom          0.25mm  Through hole
CM_PA25_SPI_SSVia          -40.525mm    -28.95mm  Bottom          0.25mm  Through hole
PHY_REFCLK  Via            -62.9mm   -37.475mm  Bottom          0.25mm  Through hole
PHY_RXD1    Via           -58.65mm   -38.875mm  Bottom          0.25mm  Through hole
PHY_RXD0    Via          -60.775mm   -38.875mm  Bottom          0.25mm  Through hole
POWER_LED_CTRLVia             -6.8mm    -9.825mm  Bottom          0.25mm  Through hole
VCC_TARGET_USB_P5V0Via            -31.2mm   -15.275mm  Bottom          0.25mm  Through hole
NetQ100_1   Via          -12.975mm   -16.175mm  Bottom          0.25mm  Through hole
PHY_RXER    Via          -63.075mm  -33.9235mm  Bottom          0.25mm  Through hole
CM_PA17_SERCOM1_SCLVia          -35.925mm    -24.25mm  Bottom          0.25mm  Through hole
CM_PA16_SERCOM1_SDAVia            -37.2mm    -24.25mm  Bottom          0.25mm  Through hole
VCC_EDBG_USB_P5V0Via          -16.725mm    -16.05mm  Bottom          0.25mm  Through hole
NetQ902_3   Via          -39.225mm   -24.975mm  Bottom          0.25mm  Through hole
CM_PA05_AIN5Via           -52.75mm  -32.7986mm  Bottom          0.25mm  Through hole
CM_PA09_AIN17Via          -36.275mm   -21.825mm  Bottom          0.25mm  Through hole
VCC_CM_P3V3 Via         -33.7174mm   -3.8788mm  Bottom          0.25mm  Through hole
CM_PA01_GPIOVia            -39.7mm   -26.675mm  Bottom          0.25mm  Through hole
CM_PA18_CMP0Via            -44.2mm   -20.225mm  Bottom          0.25mm  Through hole
NetD800_1   Via             -6.8mm     -11.1mm  Bottom          0.25mm  Through hole
CM_PA10_GPIOVia         -56.1059mm  -13.7479mm  Bottom          0.25mm  Through hole
EDBG_CDC_USART_RXVia           -33.93mm  -28.8247mm  Bottom          0.25mm  Through hole
EDBG_CDC_USART_TXVia         -32.6549mm  -28.8247mm  Bottom          0.25mm  Through hole
CM_PA11_GCLK5Via          -28.075mm    -25.75mm  Bottom          0.25mm  Through hole
NetD801_1   Via            -1.25mm    -6.825mm  Bottom          0.25mm  Through hole
STATUS_LED_CTRLVia            -1.25mm     -12.8mm  Bottom          0.25mm  Through hole
NetC802_1   Via           -16.05mm    -8.775mm  Bottom          0.25mm  Through hole
NetD300_2   Via          -36.625mm    -11.45mm  Bottom          0.25mm  Through hole
CM_PA31_SWDIOVia          -39.725mm     -37.9mm  Bottom          0.25mm  Through hole
CM_PA30_SWCLKVia           -38.65mm   -37.075mm  Bottom          0.25mm  Through hole
EDBG_DGI_SCLVia              -22mm  -28.8247mm  Bottom          0.25mm  Through hole
EDBG_DGI_SDAVia            -23.3mm  -28.8247mm  Bottom          0.25mm  Through hole
DGI_GPIO3   Via            -16.8mm  -28.8247mm  Bottom          0.25mm  Through hole
EDBG_TARGET_SWOVia            -15.5mm  -28.8247mm  Bottom          0.25mm  Through hole
EDBG_TARGET_SWCLKVia         -14.2248mm  -28.8247mm  Bottom          0.25mm  Through hole
EDBG_TARGET_SWDIOVia           -12.95mm  -28.8247mm  Bottom          0.25mm  Through hole
EDBG_TARGET_RESETVia         -11.6744mm  -28.8247mm  Bottom          0.25mm  Through hole
DGI_GPIO2   Via            -18.1mm  -28.8247mm  Bottom          0.25mm  Through hole
DGI_GPIO1   Via            -19.4mm  -28.8247mm  Bottom          0.25mm  Through hole
DGI_GPIO0   Via            -20.7mm  -28.8247mm  Bottom          0.25mm  Through hole
VCC_MCU_VDDCOREVia              -31mm     -75.9mm  Bottom          0.25mm  Through hole
NetR304_1   Via          -59.625mm    -90.25mm  Bottom          0.25mm  Through hole
NetQ300_1   Via            -56.8mm    -90.75mm  Bottom          0.25mm  Through hole
NetQ300_3   Via            -56.8mm   -92.575mm  Bottom          0.25mm  Through hole
VCC_MCU_VSW Via            -29.7mm     -75.9mm  Bottom          0.25mm  Through hole
VCC_P1V2    Via         -65.8611mm       -27mm  Bottom          0.25mm  Through hole
NetC600_1   Via         -69.1619mm  -25.7369mm  Bottom          0.25mm  Through hole
PHY_TXEN    Via           -67.84mm  -32.4896mm  Bottom          0.25mm  Through hole
PHY_TXD0    Via         -66.9497mm  -31.3546mm  Bottom          0.25mm  Through hole
PHY_TXD1    Via          -66.275mm   -32.475mm  Bottom          0.25mm  Through hole
VCC_MCU_VDDANAVia          -27.225mm     -60.6mm  Bottom          0.25mm  Through hole
NetJ303_4   Via            -32.5mm    -8.925mm  Bottom          0.25mm  Through hole
NetQ103_2   Via          -17.875mm    -7.775mm  Bottom          0.25mm  Through hole
NetR604_2   Via          -72.675mm  -29.8796mm  Bottom          0.25mm  Through hole
CM_PA00_GPIOVia              -41mm  -38.3254mm  Bottom          0.25mm  Through hole
PHY_MDC     Via          -73.525mm  -38.1172mm  Bottom          0.25mm  Through hole

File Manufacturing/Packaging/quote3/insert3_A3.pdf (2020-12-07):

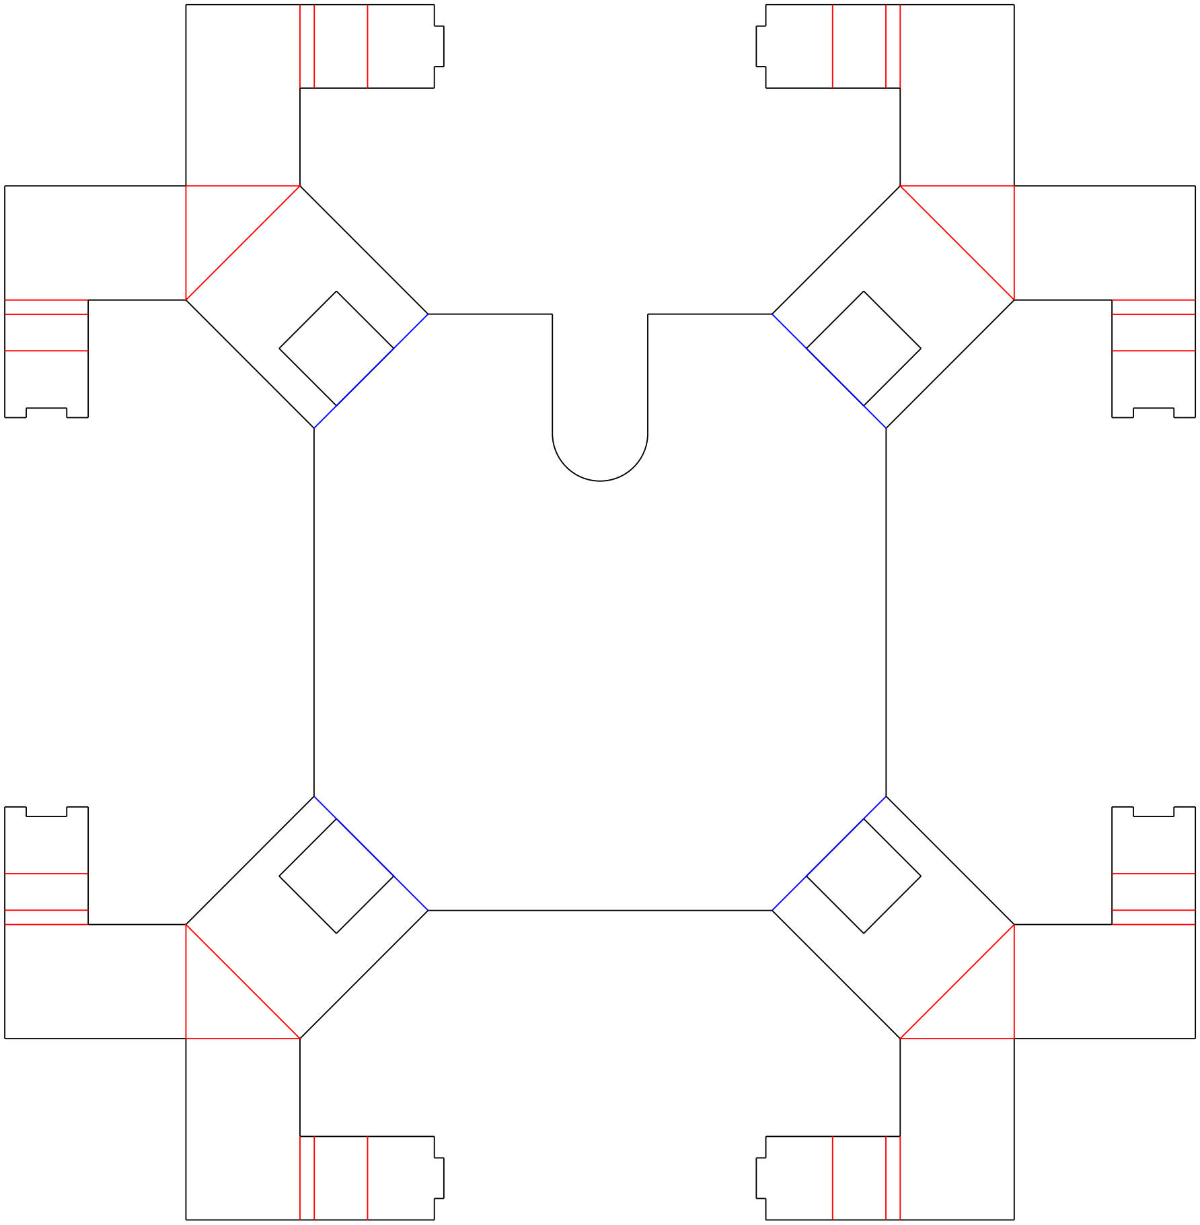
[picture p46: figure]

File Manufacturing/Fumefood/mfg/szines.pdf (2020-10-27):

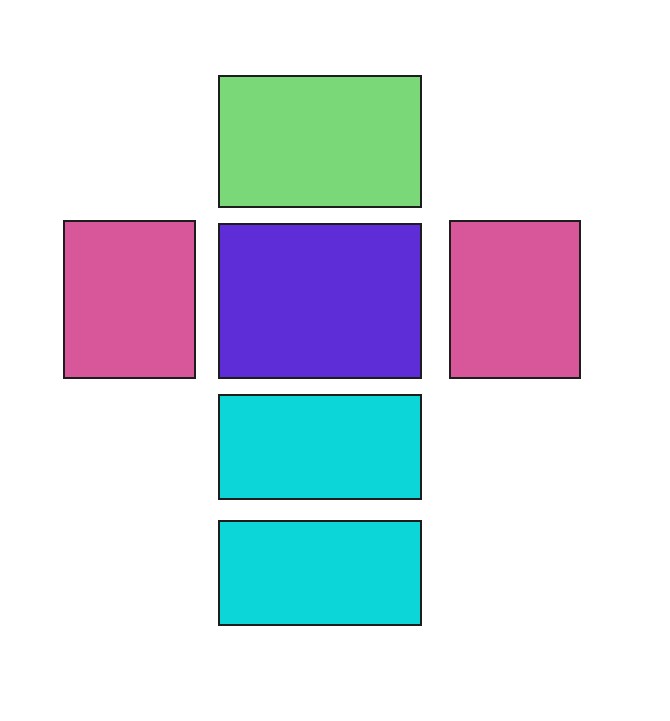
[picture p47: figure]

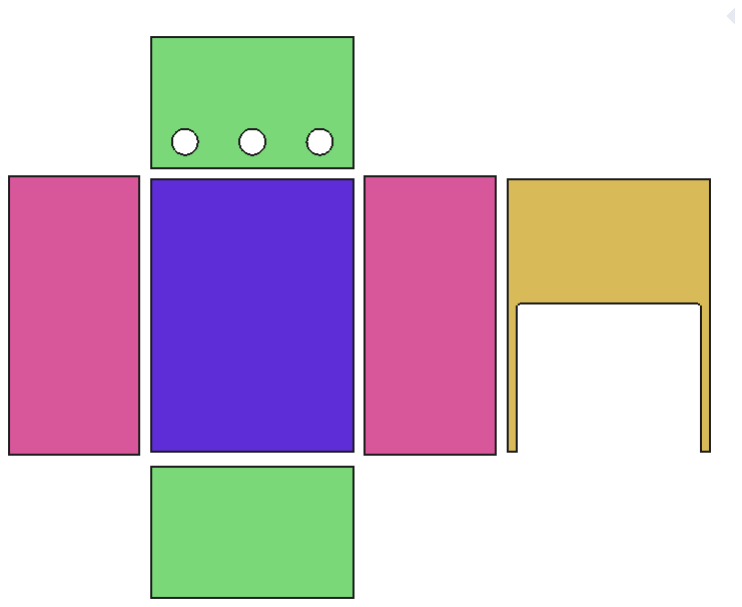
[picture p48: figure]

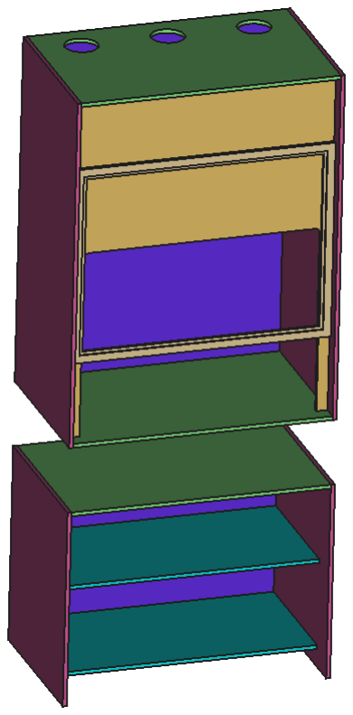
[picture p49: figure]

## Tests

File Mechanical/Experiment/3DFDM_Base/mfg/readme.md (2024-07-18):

## How to print the 3DFDM_Base

- Import 3DFDM_Base.stl into PrusaSlicer (any other should work as well)
- This was designed to be printable at this original orientation, so it doesn't need change
- Scale every direction to 100.5%, when printing in PLA or PETG
- Set infill to 10-20% rectlinear
- Support will only be needed on the build plate

## How to print the 3DFDM_Attachment_tool

- Import 3DFDM_Attachment_tool.stl into PrusaSlicer (any other should work as well)
- You can use the original orientation, or you can rotate it +90° along the X axis
- Scale every direction to 100.5%, when printing in PLA or PETG
- Set infill to 10-20% rectlinear
- Support will not be needed

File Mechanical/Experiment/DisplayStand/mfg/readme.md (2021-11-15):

## How to print

### Stand
- Import Stand.stl into prusa slicer
- Rotate +125°along the X axis
- Rotate +90°along the Y axis
- Scale X & Y (not Z) to 100.5% when printing in PLA or PETG
- Set infill to 20% rectlinear

 slicer_stand.stp 

### Leg

- Import Leg.stl into prusa slicer
- Rotate +125°along the X axis
- Rotate +90°along the Z axis
- Scale X & Y (not Z) to 100.5% when printing in PLA or PETG
- Set infill to 30% (Honey)

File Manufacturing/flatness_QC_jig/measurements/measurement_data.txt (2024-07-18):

=~=~=~=~=~=~=~=~=~=~=~= PuTTY log 2024.06.13 14:09:39 =~=~=~=~=~=~=~=~=~=~=~=
Jig Started!
-0.43,-0.39,-0.27,0.97,0.13,FAIL
-0.09,-0.23,-0.05,0.41,-0.02,PASS
0.08,-0.36,0.01,0.20,0.05,PASS
-18.55,-19.08,-18.58,74.79,-18.59,INVALID MEASUREMENT
0.14,-0.39,0.11,0.03,0.09,PASS
-0.09,0.03,-0.08,0.58,-0.44,FAIL
0.13,-0.29,0.11,0.27,-0.23,PASS
0.10,-0.23,0.14,0.36,-0.38,PASS
-0.06,-0.09,-0.06,0.55,-0.32,FAIL
-0.09,-0.09,-0.04,0.55,-0.33,FAIL
-0.18,-0.04,-0.15,0.56,-0.19,FAIL
0.18,-0.37,0.13,0.10,-0.04,PASS
-0.03,-0.12,-0.14,0.37,-0.10,PASS
-0.19,0.08,-0.21,0.62,-0.29,FAIL
0.08,-0.36,0.24,0.37,-0.34,PASS
-0.09,-0.08,-0.03,0.55,-0.34,FAIL
-0.08,0.00,-0.16,0.61,-0.38,FAIL
0.25,-0.55,0.07,0.09,0.14,PASS
0.19,-0.40,0.20,0.09,-0.07,PASS
-0.04,-0.19,-0.01,0.38,-0.13,PASS
-0.15,-0.02,-0.18,0.57,-0.21,FAIL
-0.17,-0.02,-0.14,0.55,-0.23,FAIL
-0.12,0.01,-0.10,0.64,-0.42,FAIL
5828.12,-1457.30,-1456.76,-1456.63,-1457.42,INVALID MEASUREMENT
0.19,-0.35,0.19,0.31,-0.33,PASS
-1.04,-1.70,-0.85,4.89,-1.32,INVALID MEASUREMENT
0.18,-0.49,0.36,0.06,-0.11,PASS
0.05,-0.27,0.04,0.24,-0.05,PASS
-0.01,-0.15,-0.08,0.39,-0.14,PASS
-0.14,0.02,-0.10,0.52,-0.30,FAIL
-0.09,-0.02,-0.01,0.51,-0.38,FAIL
0.01,-0.05,0.04,0.54,-0.52,FAIL
0.05,-0.34,0.15,0.37,-0.21,PASS
-0.23,0.07,-0.12,0.53,-0.25,FAIL
-0.14,-0.05,-0.15,0.49,-0.16,PASS
-0.04,-0.15,0.01,0.54,-0.37,FAIL
-0.12,-0.05,-0.01,0.49,-0.32,PASS
0.11,-0.18,-0.15,0.33,-0.13,PASS
-0.01,-0.11,-0.04,0.43,-0.26,PASS
-0.08,-0.13,-0.04,0.50,-0.27,FAIL
0.14,-0.33,0.20,0.18,-0.19,PASS
-1022.68,-1022.96,-1022.80,4091.23,-1022.79,INVALID MEASUREMENT
0.05,-0.23,-0.07,0.33,-0.06,PASS
-0.14,-0.17,-0.11,0.43,-0.03,PASS
-287.92,-288.53,-287.91,-288.03,1152.39,INVALID MEASUREMENT
918.93,918.32,918.94,-3674.70,918.50,INVALID MEASUREMENT
0.23,-0.38,0.24,0.13,-0.20,PASS
0.10,-0.28,0.12,0.16,-0.08,PASS
0.05,-0.31,-0.06,0.33,-0.02,PASS
-0.10,-0.08,-0.10,0.42,-0.14,PASS
1.47,0.97,1.44,-5.02,1.13,INVALID MEASUREMENT
0.18,-0.32,0.15,0.14,-0.16,PASS
0.05,-0.15,-0.05,0.37,-0.20,PASS
0.30,-0.41,0.21,0.14,-0.24,PASS
0.10,-0.21,0.09,0.37,-0.37,PASS
-295.79,-296.39,-295.95,-302.37,1190.49,INVALID MEASUREMENT
0.25,-0.35,0.09,0.15,-0.12,PASS
0.04,-0.08,0.12,0.45,-0.52,PASS

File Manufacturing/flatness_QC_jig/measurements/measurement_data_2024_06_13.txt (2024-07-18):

=~=~=~=~=~=~=~=~=~=~=~= PuTTY log 2024.06.13 14:50:52 =~=~=~=~=~=~=~=~=~=~=~=
Jig Started!
Jig Started!
0.00,0.02,0.02,-0.02,-0.02,PASS
-0.09,0.03,-0.07,0.60,-0.45,FAIL
-0.30,0.10,-0.24,0.70,-0.28,FAIL
-0.14,0.05,-0.12,0.35,-0.14,PASS
-0.14,0.05,-0.12,0.35,-0.14,PASS
-0.14,0.05,-0.12,0.35,-0.14,PASS
-0.12,0.00,-0.15,0.40,-0.14,PASS
525.32,-2102.04,525.35,525.79,525.60,INVALID MEASUREMENT
-0.16,-0.16,-0.13,0.31,0.12,PASS
0.01,-0.00,-0.14,0.15,-0.00,PASS
-0.06,0.05,-0.10,0.47,-0.35,PASS
-144.39,-144.25,576.96,-143.88,-144.43,INVALID MEASUREMENT
-0.12,0.03,-0.13,0.40,-0.16,PASS
-0.01,0.04,-0.14,0.44,-0.33,PASS
-0.04,-0.05,-0.03,0.39,-0.28,PASS
-0.14,0.11,-0.20,0.47,-0.25,PASS
-0.04,-0.01,-0.02,0.35,-0.27,PASS
-0.10,0.06,-0.09,0.36,-0.24,PASS
1.04,0.98,-4.22,1.44,0.76,INVALID MEASUREMENT
-0.01,-0.07,-0.02,0.39,-0.28,PASS
-0.03,0.05,-0.14,0.36,-0.23,PASS
-0.02,-0.08,-0.02,0.34,-0.22,PASS
1140.45,-285.15,-284.96,-284.80,-285.56,INVALID MEASUREMENT
0.09,-0.05,0.13,0.29,-0.47,PASS
0.30,-0.32,0.09,-0.01,-0.06,PASS
0.14,-0.17,0.10,0.22,-0.31,PASS
0.34,-0.39,0.23,-0.01,-0.19,PASS
0.12,-0.13,-0.06,0.21,-0.14,PASS
-653.97,-654.48,-654.02,2616.76,-654.29,INVALID MEASUREMENT
0.22,-0.29,0.17,0.00,-0.10,PASS
-0.04,-0.04,-0.10,0.27,-0.09,PASS
0.12,-0.28,-0.06,0.19,0.03,PASS
0.15,-0.25,0.13,0.01,-0.02,PASS
0.26,-0.35,0.24,-0.02,-0.14,PASS
-0.07,-0.13,-0.11,0.28,0.03,PASS
0.11,-0.20,-0.07,0.18,-0.02,PASS
0.19,-0.30,0.22,0.03,-0.12,PASS
0.04,-0.07,-0.03,0.28,-0.20,PASS
0.14,-0.19,0.00,0.15,-0.11,PASS
-482.25,-482.20,1928.75,-481.85,-482.44,INVALID MEASUREMENT
525.45,525.50,525.52,-2101.72,525.26,INVALID MEASUREMENT
-308.62,-308.57,-308.55,1234.54,-308.81,INVALID MEASUREMENT
-0.06,-0.02,0.00,0.34,-0.26,PASS
2540.17,-75.45,-75.57,-2313.61,-75.54,INVALID MEASUREMENT
-0.06,-0.02,-0.14,0.35,-0.11,PASS
0.09,-0.32,0.15,0.22,-0.16,PASS
0.04,-0.13,-0.07,0.23,-0.09,PASS
1.33,0.87,-4.51,1.21,1.11,INVALID MEASUREMENT
0.19,-0.26,0.02,0.08,-0.03,PASS
0.24,-0.45,0.37,-0.09,-0.05,PASS
0.23,-0.32,0.20,0.16,-0.29,PASS
-523.11,-523.28,2092.48,-522.91,-523.18,INVALID MEASUREMENT
0.01,-0.16,-0.00,0.22,-0.06,PASS
0.24,-0.37,0.22,-0.07,-0.03,PASS
0.38,-0.41,-0.00,-0.15,0.19,PASS
0.13,-0.32,0.28,0.21,-0.28,PASS
0.03,-0.08,-0.13,0.23,-0.04,PASS
-0.03,-0.19,-0.04,0.25,0.02,PASS
0.23,-0.32,0.16,-0.06,0.01,PASS
0.17,-0.20,0.16,0.21,-0.34,PASS
-1206.95,-1207.39,4828.68,-1207.02,-1207.33,INVALID MEASUREMENT
0.19,-0.25,0.13,0.12,-0.18,PASS
1.25,0.69,1.18,-4.33,1.19,INVALID MEASUREMENT
0.20,-0.36,0.13,-0.12,0.15,PASS
0.15,-0.31,0.03,0.05,0.10,PASS
=~=~=~=~=~=~=~=~=~=~=~= PuTTY log 2024.06.13 15:41:51 =~=~=~=~=~=~=~=~=~=~=~=
Jig Started!
Jig Started!
6282.25,-1570.82,-1570.40,-1570.18,-1570.86,INVALID MEASUREMENT
0.19,-0.18,0.04,0.14,-0.20,PASS
0.13,-0.22,0.08,0.20,-0.18,PASS
0.08,-0.10,0.02,0.18,-0.16,PASS
0.04,-0.12,-0.13,0.19,0.04,PASS
0.11,-0.03,0.21,0.13,-0.44,PASS
-0.23,0.14,-0.20,0.26,0.04,PASS
0.32,-0.29,0.33,0.20,-0.55,PASS
0.17,-0.12,0.13,0.26,-0.43,PASS
0.10,-0.06,0.05,0.24,-0.31,PASS
-0.27,0.68,-0.18,-0.17,-0.04,FAIL
-19.21,76.44,-19.27,-18.95,-18.99,INVALID MEASUREMENT
-1153.87,-1153.77,-1153.93,4615.22,-1153.64,INVALID MEASUREMENT
-0.10,-0.01,-0.18,0.16,0.13,PASS
1.07,-0.78,0.56,-0.50,-0.34,FAIL
-311.53,1246.26,-311.65,-311.61,-311.46,INVALID MEASUREMENT
0.08,-0.18,-0.03,-0.00,0.15,PASS
-0.28,0.07,-0.37,0.41,0.18,PASS
657.68,657.55,652.18,-2625.00,657.58,INVALID MEASUREMENT
-0.05,-0.17,0.09,0.26,-0.15,PASS
0.10,-0.38,-0.03,0.37,-0.07,PASS
0.04,-0.11,0.02,0.18,-0.15,PASS
0.09,-0.08,0.10,0.29,-0.38,PASS

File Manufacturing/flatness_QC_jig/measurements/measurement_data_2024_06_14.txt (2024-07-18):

=~=~=~=~=~=~=~=~=~=~=~= PuTTY log 2024.06.14 11:00:56 =~=~=~=~=~=~=~=~=~=~=~=
Jig Started!
0.00,0.00,0.00,0.00,0.00,PASS
0.00,0.00,0.00,0.00,0.00,PASS
0.00,-0.01,0.00,0.00,0.00,PASS
0.00,-0.01,0.00,0.00,0.00,PASS
0.00,-0.01,0.00,0.00,0.00,PASS
0.00,-0.01,0.00,0.00,0.00,PASS
0.00,0.00,0.00,0.00,0.00,PASS
0.00,0.00,0.00,0.00,0.00,PASS
-0.01,-0.01,0.00,0.00,0.00,PASS
-0.01,-0.01,0.00,0.00,0.00,PASS
0.00,-0.01,0.00,0.00,0.00,PASS
0.00,-0.01,0.00,-0.01,0.00,PASS
-11.35,31.49,-10.64,1.80,-11.32,INVALID MEASUREMENT
1174.08,-294.22,-293.34,-293.14,-293.36,INVALID MEASUREMENT
0.08,-0.72,0.16,0.36,0.14,PASS
0.08,-0.72,0.16,0.36,0.14,PASS
0.07,-0.73,0.15,0.36,0.13,PASS
0.07,-0.73,0.15,0.36,0.13,PASS
180.25,179.45,-720.57,180.54,180.31,INVALID MEASUREMENT
0.07,-0.73,0.15,0.36,0.13,PASS
0.08,-0.72,0.16,0.36,0.14,PASS
0.08,-0.72,0.16,0.36,0.14,PASS
0.74,-0.97,-1.07,0.74,0.58,FAIL
0.01,-0.00,-0.00,0.01,-0.00,PASS
0.00,-0.01,0.00,0.00,0.00,PASS
0.00,-0.01,0.00,0.00,0.00,PASS
0.00,-0.01,0.00,0.00,0.00,PASS
0.00,-0.01,0.00,0.00,0.00,PASS
0.00,0.00,0.00,0.00,0.00,PASS
0.00,0.00,0.00,0.00,0.00,PASS
0.00,-0.01,0.00,0.00,0.00,PASS
0.00,-0.01,0.00,0.00,0.00,PASS
0.00,-0.01,0.00,0.00,0.00,PASS
0.00,-0.01,0.00,0.00,0.00,PASS
0.00,-0.01,0.00,0.00,0.00,PASS
0.00,-0.01,0.00,0.00,0.00,PASS
0.08,-0.73,0.15,0.36,0.13,PASS
0.07,-0.73,0.15,0.36,0.13,PASS
0.07,-0.73,0.15,0.36,0.13,PASS
0.07,-0.73,0.15,0.36,0.13,PASS
0.07,-0.73,0.15,0.36,0.13,PASS
0.07,-0.73,0.15,0.36,0.13,PASS
-2.50,-3.30,-2.42,10.64,-2.44,INVALID MEASUREMENT
0.08,-0.72,0.16,0.36,0.14,PASS
0.08,-0.72,0.16,0.36,0.14,PASS
0.08,-0.72,0.16,0.36,0.14,PASS
0.08,-0.72,0.16,0.36,0.14,PASS
0.07,-0.73,0.15,0.36,0.13,PASS
0.08,-0.73,0.15,0.36,0.13,PASS
0.08,-0.73,0.15,0.36,0.13,PASS
0.08,-0.73,0.15,0.36,0.13,PASS
0.08,-0.73,0.15,0.36,0.13,PASS
0.07,-0.73,0.15,0.36,0.13,PASS
0.07,-0.73,0.15,0.36,0.13,PASS
0.07,-0.73,0.15,0.36,0.13,PASS
0.08,-0.72,0.16,0.36,0.14,PASS
0.08,-0.72,0.16,0.36,0.14,PASS
0.08,-0.72,0.16,0.36,0.14,PASS
0.08,-0.72,0.16,0.36,0.14,PASS
0.08,-0.72,0.16,0.36,0.14,PASS
0.08,-0.72,0.16,0.36,0.14,PASS
-0.51,-1.31,-0.43,-0.23,2.48,INVALID MEASUREMENT
-1.45,-2.25,-1.37,1.18,3.89,INVALID MEASUREMENT
-0.96,-1.76,0.53,3.08,-0.90,INVALID MEASUREMENT
0.84,0.04,-0.99,-0.79,0.90,FAIL
-1.40,1.49,-1.32,-1.12,2.35,INVALID MEASUREMENT
-0.51,-1.31,1.03,1.23,-0.45,FAIL
-0.04,-3.19,1.50,1.70,0.02,INVALID MEASUREMENT
-0.02,-0.35,0.06,0.26,0.04,PASS
0.64,-3.00,0.72,0.92,0.70,INVALID MEASUREMENT
-0.62,-1.42,-0.54,-0.34,2.94,INVALID MEASUREMENT
-0.37,1.06,-0.29,-0.09,-0.31,FAIL
0.57,-2.72,0.65,0.85,0.63,INVALID MEASUREMENT
0.08,-0.72,0.16,0.36,0.14,PASS
-1.69,0.45,1.33,-1.41,1.31,INVALID MEASUREMENT
-0.86,-2.84,2.15,-0.58,2.13,INVALID MEASUREMENT
0.08,-0.72,0.16,0.36,0.14,PASS
0.66,-0.14,0.74,-1.98,0.72,INVALID MEASUREMENT
2.77,-1.55,-0.67,0.13,-0.69,INVALID MEASUREMENT
0.08,-0.72,0.16,0.36,0.14,PASS
0.07,-0.73,0.15,0.36,0.13,PASS
0.07,-0.73,0.15,0.36,0.13,PASS
0.08,-0.72,0.16,0.36,0.14,PASS
0.08,-0.72,0.16,0.36,0.14,PASS
196.64,195.84,196.72,196.92,-786.10,INVALID MEASUREMENT
0.08,-0.73,0.15,0.35,0.13,PASS
0.08,-0.73,0.15,0.36,0.13,PASS
0.08,-0.72,0.16,0.36,0.14,PASS
0.08,-0.73,0.15,0.35,0.13,PASS
0.08,-0.73,0.15,0.35,0.13,PASS
0.08,-0.72,0.16,0.36,0.14,PASS
0.08,-0.72,0.16,0.36,0.14,PASS
0.08,-0.72,0.16,0.36,0.14,PASS
0.08,-0.72,0.16,0.36,0.14,PASS
2345.79,-587.15,-586.27,-586.07,-586.29,INVALID MEASUREMENT
0.00,-0.01,0.00,-0.01,0.00,PASS
0.01,-0.00,-0.00,-0.00,-0.00,PASS
0.01,-0.00,-0.00,0.01,-0.00,PASS
0.01,-0.00,-0.00,0.01,-0.00,PASS
0.01,-0.00,-0.00,0.01,-0.00,PASS
0.01,-0.00,-0.00,-0.00,-0.00,PASS
0.01,-0.00,-0.00,-0.00,-0.00,PASS
0.01,-0.00,-0.00,0.01,-0.00,PASS
0.01,-0.00,-0.00,-0.00,-0.00,PASS
0.01,-0.00,-0.00,-0.00,-0.00,PASS
0.01,-0.00,-0.00,-0.00,-0.00,PASS
0.01,-0.00,-0.00,0.01,-0.00,PASS
0.01,-0.00,-0.00,-0.00,-0.00,PASS
0.01,-0.00,-0.00,-0.00,-0.00,PASS
0.01,-0.00,-0.00,-0.00,-0.00,PASS
0.01,-0.00,-0.00,0.01,-0.00,PASS
0.01,-0.00,-0.00,0.01,-0.00,PASS
0.01,-0.00,-0.00,0.01,-0.00,PASS
0.01,-0.00,-0.00,0.01,-0.00,PASS
-0.02,-0.03,-0.03,0.13,-0.03,PASS
0.01,-0.00,-0.00,0.01,-0.00,PASS
0.01,-0.00,-0.00,-0.00,-0.00,PASS
0.02,-0.00,-0.00,-0.00,-0.00,PASS
0.01,-0.00,-0.00,-0.00,-0.01,PASS
0.01,-0.00,-0.00,-0.00,-0.00,PASS
0.01,-0.00,-0.01,0.01,-0.01,PASS
0.00,-0.01,-0.00,0.01,-0.00,PASS
0.01,-0.00,-0.01,0.00,-0.01,PASS
0.00,-0.00,-0.00,0.01,-0.00,PASS
0.01,-0.00,-0.00,0.01,-0.00,PASS
0.01,-0.00,-0.01,0.00,-0.00,PASS
0.01,-0.00,-0.00,-0.00,-0.00,PASS
0.01,-0.00,-0.00,-0.00,-0.00,PASS
0.01,-0.00,-0.00,-0.00,-0.00,PASS
0.01,-0.00,-0.00,-0.00,-0.00,PASS
0.01,-0.00,-0.00,-0.00,-0.00,PASS
0.01,-0.00,-0.00,-0.00,-0.00,PASS
0.01,-0.00,-0.00,-0.00,-0.00,PASS
0.01,-0.00,-0.00,-0.00,-0.00,PASS
0.01,-0.00,-0.00,-0.00,-0.00,PASS
0.01,-0.00,-0.00,-0.00,-0.00,PASS
0.01,-0.00,-0.00,-0.00,-0.00,PASS
0.08,-0.73,0.15,0.35,0.13,PASS
0.08,-0.72,0.16,0.36,0.14,PASS
0.08,-0.72,0.16,0.36,0.14,PASS
0.08,-0.72,0.16,0.36,0.14,PASS
11.48,-3.58,-2.70,-2.50,-2.72,INVALID MEASUREMENT
0.08,-0.72,0.16,0.36,0.14,PASS
0.08,-0.72,0.16,0.36,0.14,PASS
0.08,-0.73,0.15,0.35,0.13,PASS
0.08,-0.73,0.15,0.35,0.13,PASS
38.85,-10.42,-9.54,-9.34,-9.56,INVALID MEASUREMENT
0.08,-0.73,0.15,0.35,0.13,PASS
0.08,-0.73,0.15,0.35,0.13,PASS
586.17,-147.25,-146.37,-146.17,-146.39,INVALID MEASUREMENT
0.08,-0.73,0.15,0.35,0.13,PASS
0.08,-0.72,0.16,0.36,0.14,PASS
0.08,-0.72,0.16,0.36,0.14,PASS
0.08,-0.72,0.16,0.36,0.14,PASS
-1181.19,-522.75,-1181.11,-1180.91,4065.95,INVALID MEASUREMENT
0.08,-0.72,0.16,0.36,0.14,PASS
0.08,-0.72,0.16,0.36,0.14,PASS
0.08,-0.72,0.16,0.36,0.14,PASS
-361.95,-362.75,1448.27,-361.67,-361.89,INVALID MEASUREMENT
0.08,-0.72,0.16,0.36,0.14,PASS
0.08,-0.72,0.16,0.36,0.14,PASS
0.08,-0.72,0.16,0.36,0.14,PASS
1.25,-2.49,1.33,1.53,-1.63,INVALID MEASUREMENT
1174.08,-294.22,-293.34,-293.14,-293.36,INVALID MEASUREMENT
0.08,-0.72,0.16,0.36,0.14,PASS
0.08,-0.72,0.16,0.36,0.14,PASS
-262.65,-263.45,-262.57,1051.25,-262.59,INVALID MEASUREMENT
-4.09,0.81,1.27,1.28,0.74,INVALID MEASUREMENT
0.26,-0.28,0.18,0.20,-0.35,PASS
-0.02,0.08,0.03,0.47,-0.57,PASS
0.02,-0.13,-0.08,0.26,-0.09,PASS
0.22,-0.45,0.24,-0.02,0.03,PASS
0.31,-0.33,0.20,-0.01,-0.18,PASS
-15.78,-16.22,-15.85,-16.02,63.87,INVALID MEASUREMENT
0.27,-0.17,0.21,0.03,-0.32,PASS
-0.15,0.14,-0.23,0.48,-0.23,PASS
0.36,-0.30,0.31,-0.09,-0.27,PASS
0.19,-0.36,0.12,0.10,-0.07,PASS
-482.17,1928.77,-482.18,-481.89,-482.53,INVALID MEASUREMENT
0.02,0.03,0.01,0.30,-0.34,PASS
0.15,-0.13,0.16,0.25,-0.44,PASS
0.07,-0.02,0.02,0.40,-0.45,PASS
0.00,-0.01,-0.02,0.33,-0.31,PASS
0.09,-0.08,-0.02,0.19,-0.20,PASS
0.21,-0.21,0.05,0.09,-0.14,PASS
-785.18,-785.21,-785.29,3140.79,-785.09,INVALID MEASUREMENT
-18.34,-18.37,73.05,-18.08,-18.24,INVALID MEASUREMENT
-0.04,-0.07,-0.15,0.22,0.06,PASS
0.00,-0.01,-0.15,0.31,-0.17,PASS
0.16,-0.27,-0.00,0.11,0.02,PASS
0.14,-0.18,0.02,0.14,-0.14,PASS
-0.03,-0.36,0.11,-0.05,0.34,PASS
-0.15,-0.02,-0.24,0.23,0.18,PASS
0.05,-0.11,-0.13,0.16,0.01,PASS
-0.12,-0.15,-0.06,0.33,-0.02,PASS
0.01,-0.09,-0.02,0.35,-0.26,PASS
0.11,-0.14,-0.01,0.15,-0.09,PASS
0.17,-0.13,-0.01,0.24,-0.29,PASS
0.01,-0.09,-0.11,0.17,0.04,PASS
0.32,-0.32,0.16,0.03,-0.19,PASS
0.01,-0.23,-0.01,0.17,0.06,PASS
0.13,-0.31,0.06,-0.01,0.11,PASS
-0.05,-0.02,-0.15,0.37,-0.17,PASS
0.10,-0.06,0.10,0.38,-0.51,PASS
0.31,-0.28,0.25,0.01,-0.31,PASS
-0.19,-0.16,-0.02,0.51,-0.16,FAIL
-66.82,267.93,-66.83,-66.85,-67.41,INVALID MEASUREMENT
0.20,-0.11,0.16,0.20,-0.43,PASS
1207.68,-301.88,-302.04,-301.68,-302.06,INVALID MEASUREMENT
-695.13,2780.55,-695.25,-694.89,-695.27,INVALID MEASUREMENT
-0.01,0.04,-0.13,0.23,-0.15,PASS
-0.32,0.08,-0.27,0.50,0.00,FAIL
-0.30,0.09,-0.27,0.49,0.01,PASS
-0.30,0.09,-0.28,0.49,0.01,PASS
0.04,-0.07,0.01,0.35,-0.31,PASS
0.04,-0.07,0.01,0.35,-0.31,PASS
0.04,-0.07,0.01,0.35,-0.31,PASS
0.04,-0.07,0.01,0.35,-0.31,PASS
0.04,-0.07,0.01,0.35,-0.31,PASS
-0.63,0.11,-0.59,0.97,0.15,FAIL
-0.33,0.06,-0.31,0.49,0.07,PASS
-0.33,0.06,-0.31,0.49,0.07,PASS
-0.32,0.06,-0.30,0.48,0.08,PASS
0.02,-0.10,-0.00,0.35,-0.25,PASS
0.02,-0.10,-0.00,0.35,-0.25,PASS
0.03,-0.10,-0.01,0.35,-0.25,PASS
-3.79,0.93,0.57,1.36,0.95,INVALID MEASUREMENT
-0.32,0.06,-0.31,0.49,0.07,PASS

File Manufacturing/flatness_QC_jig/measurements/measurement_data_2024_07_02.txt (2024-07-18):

=~=~=~=~=~=~=~=~=~=~=~= PuTTY log 2024.07.02 09:37:28 =~=~=~=~=~=~=~=~=~=~=~=
Jig Started!
-0.13,-0.13,-0.02,0.37,-0.07,PASS
0.16,-0.16,0.15,0.21,-0.38,PASS
0.17,-0.15,0.14,0.20,-0.38,PASS
0.16,-0.15,0.15,0.20,-0.38,PASS
0.16,-0.15,0.15,0.20,-0.38,PASS
0.16,-0.15,0.15,0.20,-0.38,PASS

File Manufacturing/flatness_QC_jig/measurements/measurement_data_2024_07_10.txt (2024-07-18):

=~=~=~=~=~=~=~=~=~=~=~= PuTTY log 2024.07.10 13:44:26 =~=~=~=~=~=~=~=~=~=~=~=
Jig started!
5.78, 5.43, 5.75, 5.79, 5.22,     0.19, -0.16, 0.16, 0.20, -0.37,     0

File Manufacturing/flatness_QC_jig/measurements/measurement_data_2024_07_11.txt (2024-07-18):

=~=~=~=~=~=~=~=~=~=~=~= PuTTY log 2024.07.11 14:02:27 =~=~=~=~=~=~=~=~=~=~=~=
Jig started!
Jig started!
5.81, 5.88, 5.99, 5.71, 5.37,     0.06, 0.13, 0.24, -0.04, -0.38,     PASS
6.00, 6.38, 6.06, 6.17, 6.04,     -0.13, 0.25, -0.07, 0.04, -0.09,     PASS
6.14, 5.86, 6.31, 5.80, 5.74,     0.17, -0.11, 0.34, -0.17, -0.23,     PASS
5.87, 6.21, 5.97, 6.23, 5.93,     -0.17, 0.17, -0.07, 0.19, -0.11,     PASS
6.38, 6.22, 6.52, 6.21, 6.54,     0.01, -0.15, 0.15, -0.16, 0.17,     PASS
6.18, 6.26, 6.37, 6.30, 6.40,     -0.12, -0.04, 0.07, -0.00, 0.10,     PASS
6.21, 5.90, 6.27, 5.89, 5.87,     0.18, -0.13, 0.24, -0.14, -0.16,     PASS
6.21, 6.43, 6.32, 6.34, 6.43,     -0.14, 0.08, -0.03, -0.01, 0.08,     PASS
6.04, 6.08, 6.05, 6.06, 5.74,     0.05, 0.09, 0.06, 0.07, -0.25,     PASS
6.20, 6.29, 6.32, 6.23, 6.18,     -0.04, 0.05, 0.08, -0.01, -0.06,     PASS
5.79, 6.02, 5.93, 6.06, 5.66,     -0.10, 0.13, 0.04, 0.17, -0.23,     PASS
5.92, 6.22, 6.24, 6.33, 6.17,     -0.26, 0.04, 0.06, 0.15, -0.01,     PASS
6.18, 6.35, 6.22, 6.28, 6.32,     -0.09, 0.08, -0.05, 0.01, 0.05,     PASS
6.15, 6.62, 6.30, 6.52, 6.65,     -0.30, 0.17, -0.15, 0.07, 0.20,     PASS
6.49, 6.46, 6.85, 6.45, 7.03,     -0.17, -0.20, 0.19, -0.21, 0.37,     PASS
6.19, 6.22, 6.33, 6.18, 6.08,     -0.01, 0.02, 0.13, -0.02, -0.12,     PASS
6.42, 6.30, 6.51, 6.36, 6.44,     0.01, -0.11, 0.10, -0.05, 0.03,     PASS
6.02, 6.34, 6.09, 6.30, 6.01,     -0.13, 0.19, -0.06, 0.15, -0.14,     PASS
6.29, 6.59, 6.41, 6.53, 6.54,     -0.18, 0.12, -0.06, 0.06, 0.07,     PASS
6.11, 6.01, 6.13, 5.94, 5.90,     0.09, -0.01, 0.11, -0.08, -0.12,     PASS
5.99, 6.17, 6.08, 6.03, 5.85,     -0.03, 0.15, 0.06, 0.01, -0.17,     PASS
5.84, 6.15, 6.00, 6.08, 5.65,     -0.10, 0.21, 0.06, 0.14, -0.29,     PASS
5.72, 5.96, 5.84, 5.99, 5.32,     -0.05, 0.19, 0.07, 0.22, -0.45,     PASS
5.80, 5.85, 6.00, 5.83, 5.32,     0.04, 0.09, 0.24, 0.07, -0.44,     PASS
5.79, 6.14, 5.99, 5.99, 5.55,     -0.10, 0.25, 0.10, 0.10, -0.34,     PASS
6.14, 5.92, 6.27, 6.00, 6.01,     0.07, -0.15, 0.20, -0.07, -0.06,     PASS
6.12, 5.77, 6.30, 5.65, 5.64,     0.22, -0.13, 0.40, -0.25, -0.26,     PASS
5.63, 6.29, 5.76, 6.16, 5.67,     -0.27, 0.39, -0.14, 0.26, -0.23,     PASS
6.03, 5.93, 6.17, 5.75, 5.59,     0.14, 0.04, 0.28, -0.14, -0.30,     PASS
6.18, 5.86, 6.30, 5.85, 5.84,     0.17, -0.15, 0.29, -0.16, -0.17,     PASS
6.29, 5.92, 6.53, 6.01, 6.21,     0.10, -0.27, 0.34, -0.18, 0.02,     PASS
6.03, 6.19, 6.09, 6.21, 6.02,     -0.08, 0.08, -0.02, 0.10, -0.09,     PASS
5.46, 5.89, 5.72, 5.90, 5.04,     -0.14, 0.29, 0.12, 0.30, -0.56,     PASS
5.87, 5.66, 5.98, 5.74, 5.36,     0.15, -0.06, 0.26, 0.02, -0.36,     PASS
0.02, 0.00, 0.01, 0.03, 0.01,     0.01, -0.01, -0.00, 0.02, -0.00,     PASS
5.67, 5.97, 5.81, 5.84, 5.36,     -0.06, 0.24, 0.08, 0.11, -0.37,     PASS
5.95, 5.95, 6.17, 6.00, 5.70,     -0.00, -0.00, 0.22, 0.05, -0.25,     PASS
6.04, 6.48, 6.20, 6.45, 6.38,     -0.27, 0.17, -0.11, 0.14, 0.07,     PASS
5.94, 6.26, 6.03, 6.21, 5.89,     -0.13, 0.19, -0.04, 0.14, -0.18,     PASS
5.81, 5.74, 5.96, 5.63, 5.32,     0.12, 0.05, 0.27, -0.06, -0.37,     PASS
6.28, 5.99, 6.54, 5.95, 6.14,     0.10, -0.19, 0.36, -0.23, -0.04,     PASS
6.17, 6.03, 6.49, 5.96, 6.12,     0.02, -0.12, 0.34, -0.19, -0.03,     PASS
5.94, 6.50, 6.01, 6.57, 6.31,     -0.33, 0.23, -0.26, 0.30, 0.04,     PASS
5.93, 6.16, 5.98, 6.12, 5.72,     -0.05, 0.18, -0.00, 0.14, -0.26,     PASS
6.21, 6.17, 6.38, 6.07, 6.36,     -0.03, -0.07, 0.14, -0.17, 0.12,     PASS
5.85, 6.10, 6.04, 5.98, 5.69,     -0.08, 0.17, 0.11, 0.05, -0.24,     PASS
5.76, 5.77, 6.00, 5.87, 5.33,     0.01, 0.02, 0.25, 0.12, -0.42,     PASS
5.75, 6.00, 5.81, 6.07, 5.50,     -0.08, 0.17, -0.02, 0.24, -0.33,     PASS
6.12, 6.21, 6.26, 6.19, 6.02,     -0.04, 0.05, 0.10, 0.03, -0.14,     PASS
6.23, 6.03, 6.34, 6.14, 6.04,     0.07, -0.13, 0.18, -0.02, -0.12,     PASS
6.14, 6.44, 6.36, 6.35, 6.62,     -0.24, 0.06, -0.02, -0.03, 0.24,     PASS
6.64, 6.23, 6.65, 6.18, 6.72,     0.16, -0.25, 0.17, -0.30, 0.24,     PASS
6.25, 6.35, 6.36, 6.23, 6.43,     -0.07, 0.03, 0.04, -0.09, 0.11,     PASS
5.68, 5.76, 5.82, 5.80, 5.15,     0.04, 0.12, 0.18, 0.16, -0.49,     PASS
5.96, 6.06, 6.09, 5.87, 5.76,     0.01, 0.11, 0.14, -0.08, -0.19,     PASS
6.31, 6.12, 6.41, 5.98, 6.12,     0.12, -0.07, 0.22, -0.21, -0.07,     PASS
6.16, 6.65, 6.27, 6.61, 6.55,     -0.29, 0.20, -0.18, 0.16, 0.10,     PASS
6.32, 6.16, 6.48, 6.19, 6.21,     0.05, -0.11, 0.21, -0.08, -0.06,     PASS
6.00, 6.14, 6.05, 6.13, 5.94,     -0.05, 0.09, -0.00, 0.08, -0.11,     PASS
5.66, 6.16, 5.87, 6.10, 5.52,     -0.20, 0.30, 0.01, 0.24, -0.34,     PASS
5.94, 6.27, 6.04, 6.08, 5.92,     -0.11, 0.22, -0.01, 0.03, -0.13,     PASS
5.67, 6.14, 5.88, 6.13, 5.52,     -0.20, 0.27, 0.01, 0.26, -0.35,     PASS
5.69, 5.74, 5.82, 5.68, 5.04,     0.10, 0.15, 0.23, 0.09, -0.55,     PASS
5.88, 6.30, 6.05, 6.19, 5.84,     -0.17, 0.25, -0.00, 0.14, -0.21,     PASS
6.92, 6.26, 6.83, 6.26, 6.91,     0.28, -0.38, 0.19, -0.38, 0.27,     PASS
6.63, 6.37, 6.93, 6.27, 6.85,     0.02, -0.24, 0.32, -0.34, 0.24,     PASS
6.27, 5.99, 6.47, 5.86, 6.07,     0.14, -0.14, 0.34, -0.27, -0.06,     PASS
6.15, 6.00, 6.19, 6.07, 6.05,     0.06, -0.09, 0.10, -0.02, -0.04,     PASS
6.29, 6.10, 6.34, 6.05, 6.20,     0.09, -0.10, 0.14, -0.15, 0.00,     PASS
6.39, 5.90, 6.49, 5.89, 6.12,     0.23, -0.26, 0.33, -0.27, -0.04,     PASS
5.71, 6.11, 5.90, 6.01, 5.60,     -0.16, 0.24, 0.03, 0.14, -0.27,     PASS
6.14, 6.11, 6.42, 6.01, 6.17,     -0.03, -0.06, 0.25, -0.16, 0.00,     PASS
6.35, 6.22, 6.62, 6.30, 6.63,     -0.07, -0.20, 0.20, -0.12, 0.21,     PASS
6.06, 5.49, 6.20, 5.32, 5.34,     0.38, -0.19, 0.52, -0.36, -0.34,     FAIL
5.80, 6.16, 5.92, 6.22, 5.89,     -0.20, 0.16, -0.08, 0.22, -0.11,     PASS
5.98, 6.31, 6.13, 6.17, 6.06,     -0.15, 0.18, 0.00, 0.04, -0.07,     PASS
6.00, 6.10, 5.99, 6.17, 5.85,     -0.02, 0.08, -0.03, 0.15, -0.17,     PASS
6.01, 5.92, 6.06, 5.83, 5.62,     0.12, 0.03, 0.17, -0.06, -0.27,     PASS
6.40, 6.40, 6.46, 6.35, 6.59,     -0.04, -0.04, 0.02, -0.09, 0.15,     PASS
5.76, 6.36, 5.89, 6.41, 5.99,     -0.32, 0.28, -0.19, 0.33, -0.09,     PASS
6.22, 6.28, 6.13, 6.19, 6.28,     0.00, 0.06, -0.09, -0.03, 0.06,     PASS
5.95, 5.88, 6.17, 5.81, 5.48,     0.09, 0.02, 0.31, -0.05, -0.38,     PASS
6.00, 6.22, 6.26, 6.14, 6.04,     -0.13, 0.09, 0.13, 0.01, -0.09,     PASS
6.47, 6.43, 6.48, 6.40, 6.52,     0.01, -0.03, 0.02, -0.06, 0.06,     PASS
6.05, 6.17, 6.27, 6.25, 5.96,     -0.09, 0.03, 0.13, 0.11, -0.18,     PASS
6.13, 6.12, 6.29, 6.10, 6.04,     -0.01, -0.02, 0.15, -0.04, -0.10,     PASS
6.17, 6.02, 6.25, 5.97, 6.01,     0.09, -0.06, 0.17, -0.11, -0.07,     PASS
6.06, 5.92, 6.25, 5.95, 5.70,     0.08, -0.06, 0.27, -0.03, -0.28,     PASS
6.11, 6.12, 6.35, 6.22, 6.27,     -0.10, -0.09, 0.14, 0.01, 0.06,     PASS
5.64, 5.94, 5.88, 5.93, 5.30,     -0.10, 0.20, 0.14, 0.19, -0.44,     PASS
6.27, 6.15, 6.52, 6.14, 6.17,     0.02, -0.10, 0.27, -0.11, -0.08,     PASS
6.26, 5.95, 6.33, 5.83, 5.97,     0.19, -0.12, 0.26, -0.24, -0.10,     PASS
6.59, 6.07, 6.76, 6.10, 6.71,     0.14, -0.38, 0.31, -0.35, 0.26,     PASS
6.02, 5.98, 6.13, 5.81, 5.61,     0.11, 0.07, 0.22, -0.10, -0.30,     PASS
6.19, 5.86, 6.34, 5.90, 5.88,     0.16, -0.17, 0.31, -0.13, -0.15,     PASS
5.93, 5.98, 6.09, 5.99, 5.70,     -0.01, 0.04, 0.15, 0.05, -0.24,     PASS
6.30, 6.10, 6.38, 5.97, 6.13,     0.12, -0.08, 0.20, -0.21, -0.05,     PASS
6.20, 5.98, 6.45, 6.02, 5.98,     0.07, -0.15, 0.32, -0.11, -0.15,     PASS
5.82, 6.10, 6.14, 6.03, 5.68,     -0.13, 0.15, 0.19, 0.08, -0.27,     PASS
6.07, 5.77, 6.18, 5.75, 5.64,     0.19, -0.11, 0.30, -0.13, -0.24,     PASS
6.25, 6.21, 6.65, 6.22, 6.41,     -0.10, -0.14, 0.30, -0.13, 0.06,     PASS
6.21, 6.61, 6.45, 6.41, 6.66,     -0.26, 0.14, -0.02, -0.06, 0.19,     PASS
6.16, 6.10, 6.33, 6.09, 6.22,     -0.02, -0.08, 0.15, -0.09, 0.04,     PASS
6.15, 5.82, 6.24, 5.88, 5.61,     0.21, -0.12, 0.30, -0.06, -0.33,     PASS
6.07, 6.44, 6.31, 6.38, 6.20,     -0.21, 0.16, 0.03, 0.10, -0.08,     PASS
6.13, 6.33, 6.27, 6.32, 6.16,     -0.11, 0.09, 0.03, 0.08, -0.08,     PASS
6.25, 6.50, 6.25, 6.40, 6.50,     -0.13, 0.12, -0.13, 0.02, 0.12,     PASS
0.02, 0.00, 0.00, 0.03, 0.00,     0.01, -0.01, -0.01, 0.02, -0.01,     PASS
6.23, 5.97, 6.38, 6.10, 6.11,     0.07, -0.19, 0.22, -0.06, -0.05,     PASS
6.08, 5.99, 6.27, 5.90, 5.73,     0.09, -0.00, 0.28, -0.09, -0.26,     PASS
6.03, 5.80, 6.05, 5.79, 5.43,     0.21, -0.02, 0.23, -0.03, -0.39,     PASS
6.14, 6.20, 6.36, 6.16, 6.07,     -0.05, 0.01, 0.17, -0.03, -0.12,     PASS
6.03, 6.25, 6.27, 6.39, 6.12,     -0.18, 0.04, 0.06, 0.18, -0.09,     PASS
6.11, 6.22, 6.34, 6.25, 6.06,     -0.09, 0.02, 0.14, 0.05, -0.14,     PASS
6.09, 6.05, 6.22, 6.06, 5.88,     0.03, -0.01, 0.16, 0.00, -0.18,     PASS
6.31, 5.74, 6.46, 5.71, 5.96,     0.27, -0.30, 0.42, -0.33, -0.08,     PASS
6.45, 6.31, 6.39, 6.21, 6.48,     0.08, -0.06, 0.02, -0.16, 0.11,     PASS

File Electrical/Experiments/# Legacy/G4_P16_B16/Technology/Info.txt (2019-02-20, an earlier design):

Size:		100mm x 100mm
Thickness:	1.6mm

Material:	FR4

Layer count:	4 layer
Stackup:	See cross section images

Min. track:	6 mil
Min. space:	6 mil

Solder mask:	red
Silkscreen:	white

Surface finish:	Immersion Gold

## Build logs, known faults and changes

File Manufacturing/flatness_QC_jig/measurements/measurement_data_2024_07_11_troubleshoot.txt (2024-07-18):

=~=~=~=~=~=~=~=~=~=~=~= PuTTY log 2024.07.11 11:40:49 =~=~=~=~=~=~=~=~=~=~=~=
Jig started!
Jig started!
6.01, 5.42, 5.98, 5.76, 5.52,     0.27, -0.32, 0.24, 0.02, -0.22,     PASS
5.89, 5.95, 5.79, 6.17, 5.86,     -0.04, 0.02, -0.14, 0.24, -0.07,     PASS
5.77, 5.46, 5.75, 5.80, 5.22,     0.17, -0.14, 0.15, 0.20, -0.38,     PASS
5.56, 5.39, 5.59, 5.90, 5.03,     0.07, -0.10, 0.10, 0.41, -0.46,     PASS
5.55, 5.40, 5.59, 5.90, 5.03,     0.06, -0.09, 0.10, 0.41, -0.46,     PASS
5.73, 5.36, 5.77, 5.69, 5.05,     0.21, -0.16, 0.25, 0.17, -0.47,     PASS
5.52, 5.48, 5.65, 5.84, 5.03,     0.02, -0.02, 0.15, 0.34, -0.47,     PASS
-2.98, -3.62, 0.00, -2.68, -2.81,     -0.56, -1.20, 2.42, -0.26, -0.39,     FAIL
5.56, 5.44, 8.35, 5.90, 5.05,     -0.50, -0.62, 2.29, -0.16, -1.01,     FAIL
5.55, 5.43, 5.62, 5.89, 5.04,     0.04, -0.08, 0.11, 0.38, -0.47,     PASS
5.56, 5.44, 5.64, 5.90, 5.05,     0.04, -0.08, 0.12, 0.38, -0.47,     PASS
5.72, 5.34, 5.75, 5.68, 5.03,     0.22, -0.16, 0.25, 0.18, -0.47,     PASS
5.54, 5.51, 5.67, 5.84, 5.05,     0.02, -0.01, 0.15, 0.32, -0.47,     PASS
3.31, 3.13, 3.24, 3.66, 3.60,     -0.08, -0.26, -0.15, 0.27, 0.21,     PASS
3.55, 3.17, 3.46, 3.49, 3.62,     0.09, -0.29, 0.00, 0.03, 0.16,     PASS
3.42, 3.38, 3.40, 3.66, 3.67,     -0.09, -0.13, -0.11, 0.15, 0.16,     PASS
3.59, 3.23, 3.50, 3.50, 3.65,     0.10, -0.26, 0.01, 0.01, 0.16,     PASS
3.46, 3.33, 3.37, 3.73, 3.68,     -0.05, -0.18, -0.14, 0.22, 0.17,     PASS
3.46, 3.46, 3.44, 3.66, 3.71,     -0.09, -0.09, -0.11, 0.11, 0.16,     PASS
3.43, 3.27, 3.36, 3.72, 3.65,     -0.06, -0.22, -0.13, 0.23, 0.16,     PASS
3.40, 3.70, 3.31, 3.73, 3.31,     -0.09, 0.21, -0.18, 0.24, -0.18,     PASS
5.29, 5.23, 5.43, 5.69, 4.83,     -0.00, -0.06, 0.14, 0.40, -0.46,     PASS
5.41, 5.44, 5.55, 5.72, 4.95,     -0.00, 0.03, 0.14, 0.31, -0.46,     PASS
5.60, 5.84, 5.84, 5.85, 5.19,     -0.06, 0.18, 0.18, 0.19, -0.47,     PASS
5.57, 5.91, 5.86, 5.77, 5.20,     -0.09, 0.25, 0.20, 0.11, -0.46,     PASS
5.84, 5.89, 6.02, 5.78, 5.41,     0.05, 0.10, 0.23, -0.01, -0.38,     PASS
5.76, 5.84, 6.08, 5.84, 5.38,     -0.02, 0.06, 0.30, 0.06, -0.40,     PASS
5.73, 5.98, 6.00, 5.85, 5.41,     -0.06, 0.19, 0.21, 0.06, -0.38,     PASS

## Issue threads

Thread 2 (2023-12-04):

Threaded insert and screw models

SukuWc, 2023-12-04:
Create FreeCAD design files for the following BOM items.

grid-hardware/Mechanical/Design/SCREW-M1.6x16.FCStd

## SCREW-M1.6x16
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

## SCREW-M1.6x8
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

## INSERT-M1.6x2.5x3
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

## INSERT-M1.6x2.5x4
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

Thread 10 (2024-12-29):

PCB: Add more precise reference partnumber to components

SukuWc, 2024-12-29:
- EPS32-S3
- 40MHz resonator
- Reset/Boot0 button (VSNX screen button)

- Make CI check if latest library component is used in PCB

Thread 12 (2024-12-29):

Frontpanel: Use footprints for common drill patterns and add silkscreen to the inside

SukuWc, 2024-12-29:
## Common patterns:

- [ ] Button cap rounded rectangle hole
- [ ] Potentiometer/encoder shaft hole
- [ ] Endless shaft hole
- [ ] Fader slider oval hole
- [ ] LED lightpipe
- [ ] Screen cutout
- [ ] Screen button

## CI
- Make sure CI checks and fails if not the latest library component is used

## Silkscreen
- Add markings for traceability onto frontpanel
- [ ] barcode
- [ ] OSHWA logo
- [ ] ${DATE} and ${HASH} variables (File name as well)
- [ ] Optional Hello hacker welcome message (maybe monster)
- [ ] Placeholder for board house internal tracing codes
- [ ] PCB thickness marking

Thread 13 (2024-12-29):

K+F: Add complient mapmode replacment thant can be broken off (North)

SukuWc, 2024-12-29:
SMD component on the inside to set proper actuation height for the actual mechanical switch
SMD soldered testpoint or female pogo for the outside

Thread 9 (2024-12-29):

PCB: Update all 3D modeles to new supplyer's CAD files

SukuWc, 2024-12-29:
- [ ] Gateron hall effect baseds switch
- [ ] Song Huei encoder
- [ ] Song Huei potentiometer

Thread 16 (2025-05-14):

VSNX PCB fixes

SukuWc, 2025-05-14:
- [ ] Add pull-up resistor for endless encoder push switch
- [ ] Replace 8 Ohm speaker load with 3x 33 Ohms in parallel

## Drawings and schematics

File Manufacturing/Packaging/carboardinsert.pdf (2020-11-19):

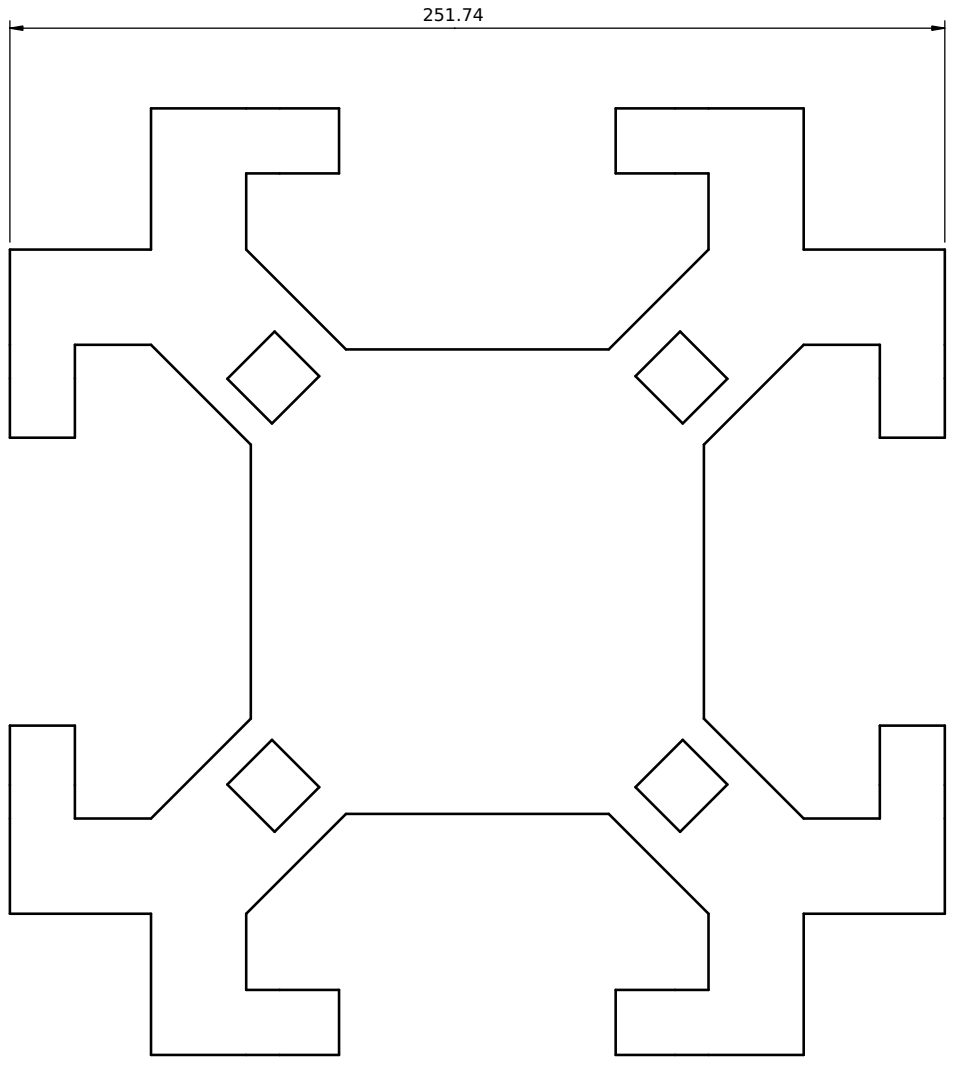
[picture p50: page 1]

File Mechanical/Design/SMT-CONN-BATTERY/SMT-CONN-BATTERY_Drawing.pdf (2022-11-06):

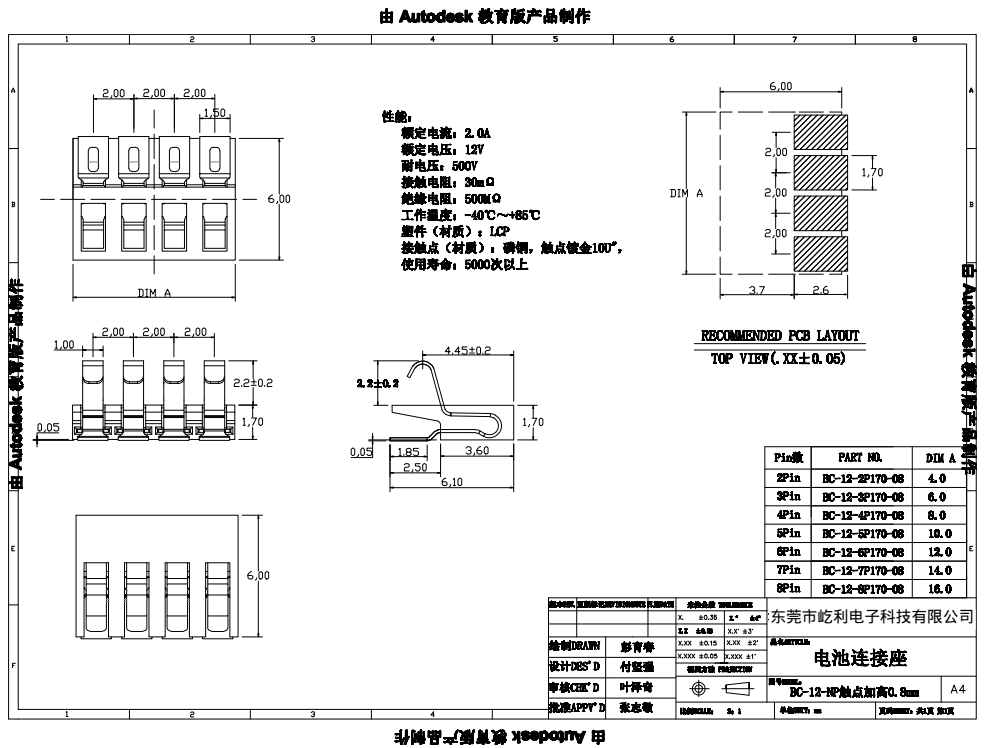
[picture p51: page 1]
东莞市屹利电子科技有限公司

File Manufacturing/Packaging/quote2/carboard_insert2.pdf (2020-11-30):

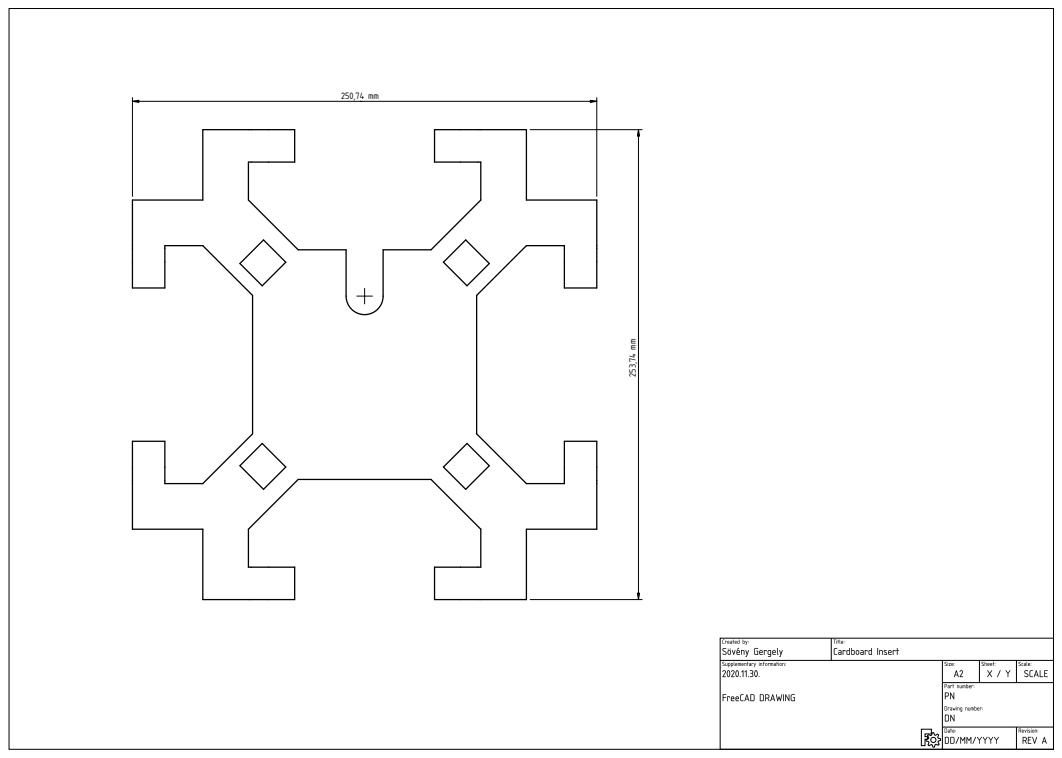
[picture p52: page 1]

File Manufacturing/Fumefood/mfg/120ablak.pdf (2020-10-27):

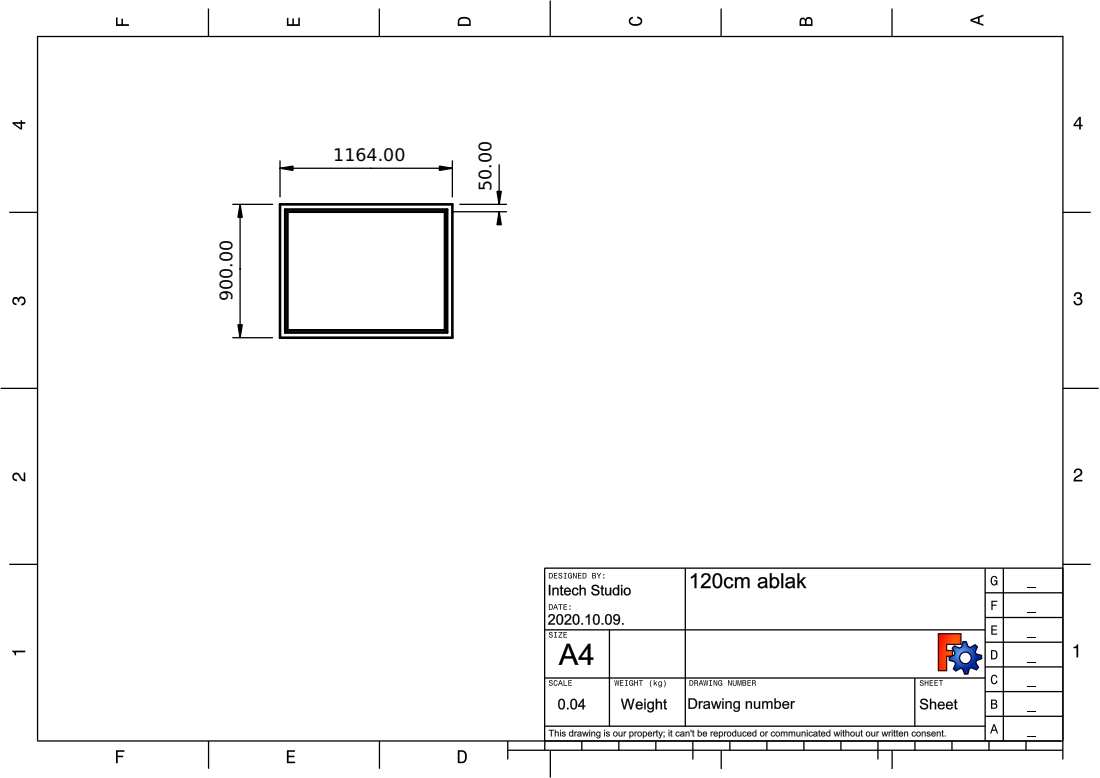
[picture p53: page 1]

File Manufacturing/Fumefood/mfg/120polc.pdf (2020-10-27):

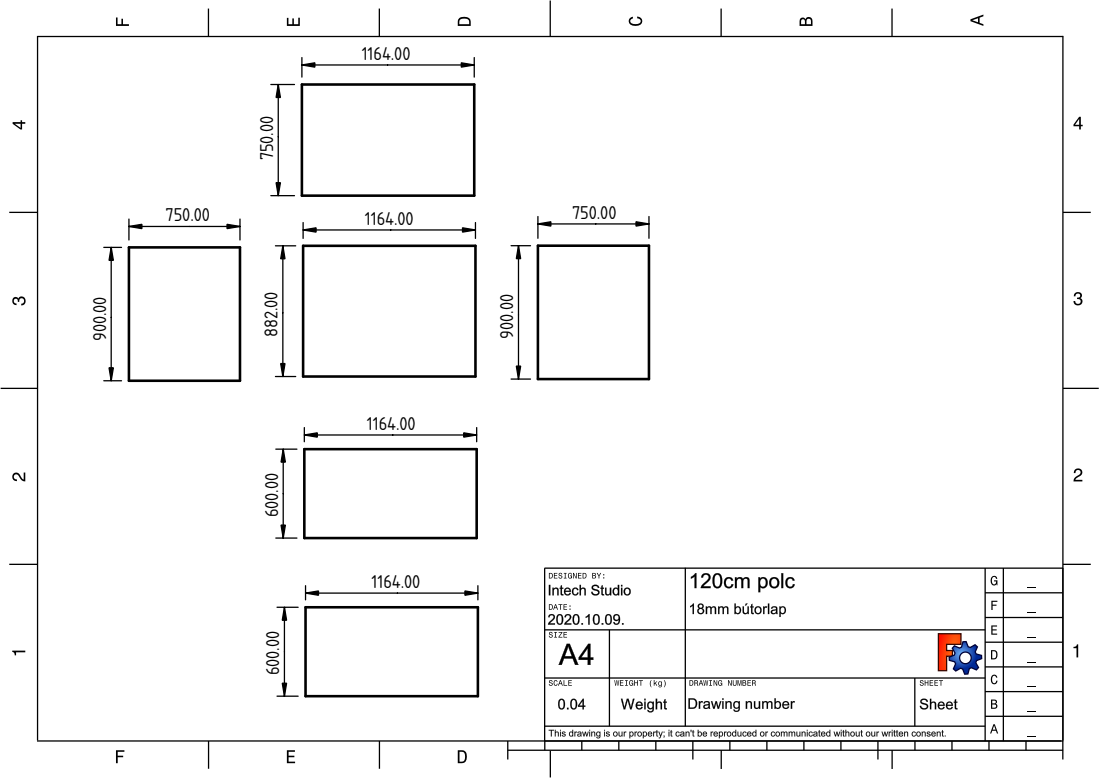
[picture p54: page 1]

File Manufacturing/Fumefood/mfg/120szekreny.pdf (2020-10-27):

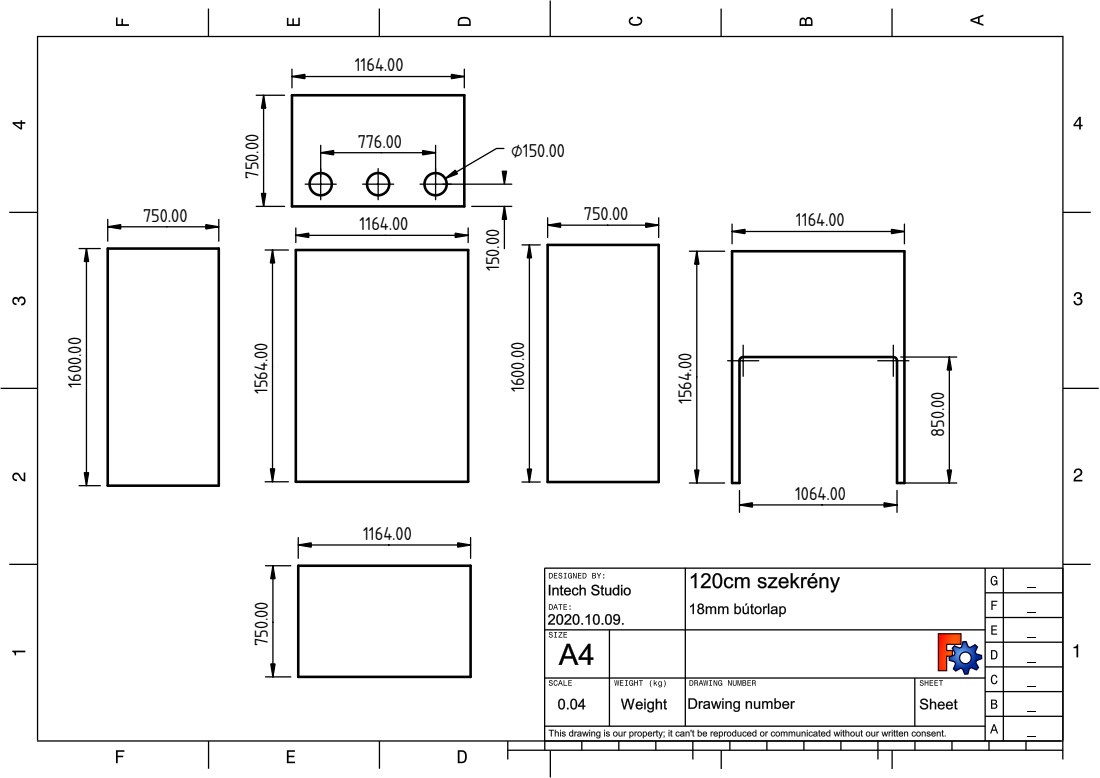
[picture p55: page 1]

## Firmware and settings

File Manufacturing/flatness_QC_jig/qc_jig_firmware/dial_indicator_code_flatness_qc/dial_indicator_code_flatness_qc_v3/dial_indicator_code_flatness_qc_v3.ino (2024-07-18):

int data_pin_array[5] = { 12, 10, 8, 6, 4 };
int clock_pin_array[5] = { 11, 9, 7, 5, 3 };
int readChar;

const int buttonPin = 2;

int buttonState = 0;
int lastButtonState = HIGH;
unsigned long lastDebounceTime = 0; // the last time the output pin was toggled
unsigned long debounceDelay = 50; // the debounce time; increase if the output flickers

unsigned long time_of_last_print = 0;
void setup()
{
  
  pinMode(buttonPin, INPUT_PULLUP);
  Serial.begin(2000000);
  Serial.println("Jig Started!");

  for (int i = 0; i<5; i++){

    pinMode(clock_pin_array[i], INPUT_PULLUP);
    pinMode(data_pin_array[i], INPUT_PULLUP);

  }

  time_of_last_print = micros();
}

uint32_t data_in[5] = {0};

int32_t data_out[5] = {9999,9999,9999,9999,9999};

uint8_t state[5] = {255, 255, 255, 255, 255}; // 255 means it is not initialized
uint8_t currentSensor = 0;
unsigned long time[5] = {0};

uint8_t printing = 0;

uint8_t active_index = 0;

void loop()
{

  uint8_t i = active_index;
    
  if (state[i] == 255){
    if (digitalRead(clock_pin_array[i]) == HIGH){
      //Serial.println("S255-H");
      time[i] = micros();
    }
    else if (micros()-time[i] > 1000*10){ // elapesd time since last high is more then 10ms
      state[i] = 0; 
    }
    else{
      //Serial.println("S255-L");
    }
  } else if (state[i] != 254) {
    
    if (state[i]%2 == 0){
      //Serial.println("S0-E");
      if (digitalRead(clock_pin_array[i]) == LOW && (micros()-time[i] > 100)){ //falling edge

        time[i] = micros();
        bitWrite(data_in[i], state[i]/2, (!digitalRead(data_pin_array[i]) & 0x1));
        state[i]++;
        if (state[i] > 24*2){
          data_in[i] = data_in[i]>>1;
          if (((data_in[i]>>20) & 0b1) == 1){ // check sign bit
            data_out[i] = (data_in[i]&0x0fffff);// invert the output
            data_out[i]*=-1;
          }
          else{
            data_out[i] = (data_in[i]&0x0fffff);
          }
          data_in[i] = 0;
          state[i] = 254;
          
          // data ready
          //Serial.print(i);
          //Serial.print(":");
          //Serial.println(data_out[i]);
          //Serial.flush();
          
          active_index = (active_index+1)%5;

        }
        
      }
    } else{
      //Serial.println("S0-O");
      if (digitalRead(clock_pin_array[i]) == HIGH && (micros()-time[i] > 400)){ //raising edge
        time[i] = micros();
        state[i]++;
      }
    }
  }


  if (state[0] == 254 && state[1] == 254 && state[2] == 254 && state[3] == 254 && state[4] == 254){

    float avg;
    avg=(data_out[0]+data_out[1]+data_out[2]+data_out[3]+data_out[4])/5;

    float data_out_avg[5] = {9999,9999,9999,9999,9999};
    data_out_avg[0]=data_out[0]-avg;
    data_out_avg[1]=data_out[1]-avg;
    data_out_avg[2]=data_out[2]-avg;
    data_out_avg[3]=data_out[3]-avg;
    data_out_avg[4]=data_out[4]-avg;
    int result_status = 0;
    int i, j, k;
    i=0;
    j=0;
    k=0;
    while (i<5){
      if (data_out_avg[i]>50){
        j++;
      }
      if (data_out_avg[i]>150 || data_out_avg[i]<-150 ){
        k++;
      }
      i++;
    }
    if (k>0) {
      result_status = 2;
    } else {
      if (j>0) {
        result_status = 1;
      } else {
        result_status = 0;
      }
    } 

      //readChar = Serial.read();
        //avg=0;
        /*Serial.print((data_out[0])/100);
        Serial.print(",");
        Serial.print((data_out[1])/100);
        Serial.print(",");
        Serial.print((data_out[2])/100);
        Serial.print(",");
        Serial.print((data_out[3])/100);
        Serial.print(",");
        Serial.print((data_out[4])/100);
        Serial.print(",");
        Serial.println(avg/100);*/
        Serial.print((data_out[0]));
        Serial.print(",");
        Serial.print((data_out[1]));
        Serial.print(",");
        Serial.print((data_out[2]));
        Serial.print(",");
        Serial.print((data_out[3]));
        Serial.print(",");
        Serial.print((data_out[4]));
        Serial.print(",");

        /*if (k>0) {
          Serial.println("INVALID MEASUREMENT");
        } else {*/
          if (result_status) {
            Serial.println("FAIL");
          } else {
            Serial.println("PASS");
          }
        //} 
        state[0] = 255;
        state[1] = 255;
        state[2] = 255;
        state[3] = 255;
        state[4] = 255;
        time[0] = 0;
        time[1] = 0;
        time[2] = 0;
        time[3] = 0;
        time[4] = 0;
        printing = 0;
        active_index=0;

        Serial.flush();
    
  }
}

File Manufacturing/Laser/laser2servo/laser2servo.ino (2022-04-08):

/*
 Controlling a servo position using a potentiometer (variable resistor)
 by Michal Rinott <http://people.interaction-ivrea.it/m.rinott>

 modified on 8 Nov 2013
 by Scott Fitzgerald
 http://www.arduino.cc/en/Tutorial/Knob
*/

#include <Servo.h>

Servo myservo;  // create servo object to control a servo


void setup() {
  myservo.attach(11);  // attaches the servo on pin 11 to the servo object
  pinMode(3, INPUT_PULLUP);
  pinMode(13, OUTPUT);
}

void loop() {

  int pinState = digitalRead(3);

  if (pinState){
    
    myservo.write(65);
    digitalWrite(13, HIGH);
    
  }
  else{
    
    myservo.write(90);
    digitalWrite(13, LOW);
  }

  delay(5);                           // waits for the servo to get there
}

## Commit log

2019-05-04 SUKU Canvas redesigned with support for Printing
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2019-09-02 SUKU pcb progress, MCU routing still missing
    [HWCFG_PO16_BU16_Rev3.sch, MCU.sch, PO16_BU16.kicad_pcb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]
2019-09-03 SUKU PO16_BU16 routing done, testpoints missing
    [MCU.sch, PO16_BU16.kicad_pcb]
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2019-09-06 SUKU potentiometer footprint fixed in PO16_BU16 PCB
    [PO16_BU16.kicad_pcb]
2019-09-06 SUKU potentiometer footprint fixed in PBF4 PCB. Shoud not effect production!
    [PBF4.kicad_pcb]
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2019-09-18 SUKU PO16_BU16 annotation fixed
    [GRID.sch, HWCFG.sch, MCU.sch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]
2019-09-18 SUKU PBF4 annotation fixed
    [MCU.sch, PBF4.kicad_pcb, UI_MUX.sch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]
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2019-09-22 SUKU PBF4 SYNC: USB routing, LED footprint, MAPMODE footprint & zone clearance
    [PBF4.kicad_pcb, UI_MUX.sch]
2019-09-22 SUKU PO16_BU16 SYNC: USB routing, LED footprint, MAPMODE footprint & zone clearance
    [GRID.sch, HWCFG.sch, MCU.sch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]
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2020-01-23 SUKU canvas37 screw tolerances, magnet tolerances,
    [feature_drill_pattern.FCStd, feature_magnet_cutout.FCStd, feature_magnet_hole.FCStd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]
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2020-02-28 SUKU FFC stiffner location fixed + GERBER
    [FFC-B_Cu.gbr, FFC-B_Mask.gbr, FFC-B_Paste.gbr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]
2020-03-04 SUKU PBF4 mapmode cap designator fixed
    [MCU.sch, PBF4.csv, PBF4.kicad_pcb]
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2020-04-06 SUKU Mapmode paste fixed on all models + GERBER
    [EN16-B_Cu.gbr, EN16-B_Mask.gbr, EN16-B_Paste.gbr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]
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2020-04-29 SUKU layout updated to avoid via-in-pad + updated FFC footprint
    [INTERFACE.kicad_pcb, INTERFACE.sch]
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2020-05-11 SUKU INTERFACE testpoints added for all pogo and ffc pins + panel outline update
    [INTERFACE.kicad_pcb, INTERFACE.sch]
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2020-05-25 SUKU PO16_BU16 mapmode debouncing cap anotation fix + ibom
    [PO16_BU16.kicad_pcb]
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2020-06-10 SUKU magnet hole depth tolerance added
    [feature_magnet_hole_2.FCStd]
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2020-09-11 SUKU 3D models are imported & updated in library, modules ready for PCBA
    [EN16-bom.csv, EN16.kicad_pcb, PBF4-bom.csv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]
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2020-12-01 SUKU hroparts c schematic symbol added + footprint fixed
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2021-02-26 SUKU EN16 updates routed, +5V_UI symbol fixed
    [EN16.kicad_pcb, MCU.sch, UI_ENC_FILTER.sch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]
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2021-03-21 SUKU headphone_amplifier schematic fix and simulation added
    [HEADPHONE_DRIVER.sch, INPUT_BUFFER.sch, STEPUP.sch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]
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2021-06-15 SUKU EN16 inner copper polygon fixed
    [EN16.kicad_pcb]
2021-06-15 SUKU inner copper poligons fixed
    [EN16.kicad_pcb, PBF4.kicad_pcb, PO16_BU16.kicad_pcb]
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2021-10-15 SUKU pbf4 2021-10 designator names fixed and mfg reexported
    [PBF4-2021-10-BOM.csv, PBF4.kicad_pcb, USB_POWER.sch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]
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2021-10-26 SUKU EF44 and YAML reverted to stable kicad
    [EF44.kicad_pcb]
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2021-11-22 SUKU EF44 build automation fixed for position files
    [EF44-B_Cu_.gbl, EF44-B_Cu_.gbr, EF44-B_Mask_.gbr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]
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2021-11-24 SUKU repo cleanup, EN16 DRC error fixed
    [526100872.stp, EN16.kicad_pcb, G4_Frontpanel.step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]
2021-11-24 SUKU PBF4 erc problems fixed
    [PBF4.kicad_pcb, PBF4.sch, UI_POT.sch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]
2021-11-24 SUKU flash footprint fixed
    [MCU.sch, PBF4.kicad_pcb, UI_MUX.sch]
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2021-12-03 SUKU component name leading spaces fixed
    [INTERFACE.kicad_pcb, INTERFACE.sch]
2021-12-03 SUKU ERC errors fixed
    [USB_POWER.sch]
2021-12-03 SUKU ef44 shiftregister pcb and schematic fixed
    [EF44.kicad_pcb, EF44.sch, UI_ENC.sch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]
2021-12-07 SUKU EF44 frontpanel LED position fixed
    [grid_frontpanel.FCStd]
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2021-12-22 SUKU pbf4 trace clearance eased
    [EF44.kicad_pcb]
2021-12-22 SUKU EF44 trace clearance eased
    [EF44.kicad_pcb]
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2022-01-10 SUKU print syntax fixed
2022-01-12 SUKU EF44 component values fixed, workflow synced
    [GRID.sch, HWCFG.sch, MCU.sch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]
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2022-01-12 SUKU PBF4 component values fixed, workflow updated
    [GRID.sch, HWCFG.sch, MCU.sch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]
2022-01-12 SUKU PO16_BU16 component values fixed, workflow updated
    [GRID.sch, HWCFG.sch, MCU.sch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]
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2022-04-14 SUKU schematic extension fixed in makefile MAN-29
2022-04-14 SUKU error print added to workflow
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2022-04-29 SUKU new potmeter insert designed MAN-12, PO16 and PBF4 frontpanels updated MAN-31
    [grid_frontpanel.FCStd, universal_insert.FCStd]
2022-05-04 SUKU port connector pinout fixed MAN-33
    [GRID.kicad_sch, MCU.kicad_sch, PBF4.kicad_pcb]
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2022-07-06 SUKU PBF4 panelization done MAN-37 and connector to edge clearance added
    [PBF4.kicad_pcb]
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2022-07-12 SUKU INTERFACE v6 migration done MAN-42 and analog switch replaced MAN-43
    [INTERFACE.kicad_sch]
2022-07-12 SUKU INTERFACE unconnected pins ERC fixed
    [INTERFACE.kicad_sch]
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2022-08-11 SUKU lip redesigned
    [canvas_injection.FCStd]
2022-08-11 SUKU pcb file was missing
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2022-10-13 SUKU pullup ERC fixed
    [HWCFG.kicad_sch, MCU.kicad_sch, PBF4.kicad_pcb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]
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2022-11-14 SUKU interface ERC fixed
    [INTERFACE.kicad_pcb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]
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2023-01-03 SUKU technical drawing fixed
    [IS_POGO_Rev3_SMT_latest.FCStd]
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2023-02-01 SUKU silders fully drafted, flow channel ribs added, moulded inserts added, wall thickness fixed
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2023-04-24 SUKU duplicated track on intertnal layer fixed
    [EF44.kicad_pcb]
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2023-05-22 SUKU EN16 erc fixed, rotation added
    [EN16.kicad_pcb]
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2023-07-11 SUKU redesigned pogopin and cap added
    [D18x25_THT.step, D18x25_THT_cap.step, IS_POGO_Rev3_SMT_latest.FCStd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]
2023-07-14 SUKU footprint rescue reverted to default library parts
    [INTERFACE.kicad_pcb, INTERFACE.kicad_sch]
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2023-08-14 SUKU erc exclude SPICE error
    [GRID.kicad_sch, HWCFG.kicad_sch, MCU.kicad_sch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]
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2023-08-14 SUKU endless potmeter 3D updated to shorter 15mm shaft
    [TEK2.kicad_pcb]
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2023-08-28 SUKU TEK2 endless potentiometer switch pullup resistor fixed
    [TEK2.kicad_pcb, UI_POT.kicad_sch]
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2023-09-12 SUKU designators fixed, date code updated
    [INTERFACE.kicad_pcb]
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2023-10-10 SUKU interface magnet hold feature longer, thickness adjusted back to 1mm, testpoint access improved
    [INTERFACE.kicad_pcb]
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2023-11-22 SUKU long fader 3d fixed
    [EF44.kicad_pcb]
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2023-11-29 SUKU spice error ignore added
    [EF44.kicad_pcb, MCU.kicad_sch]
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2023-11-29 SUKU png generation fixed
    [magnet.FCStd]
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2023-12-05 SUKU annotation and SPICE error fixed in EN16
    [MCU.kicad_sch, UI_ENC.kicad_sch, UI_ENC_FILTER.kicad_sch]
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2023-12-15 SUKU lightpipe naming fixed
    [LIGHTPIPE.FCStd]
2023-12-18 KLD lightipipe name correction
    [PLASTIC - LIGHTPIPE.FCStd, eurorack_adapter másolata.FCStd, eurorack_rail másolata.FCStd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]
2023-12-18 KLD lightpipe name correction 2.0
    [PLASTIC - LIGHTPIPE.FCStd, PLASTIC-LIGHTPIPE.FCStd]
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2024-01-02 SUKU endless pot replaced
    [PCBA-ENDLESSPOT.FCStd]
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2024-03-18 SUKU interface battery coonector symbol pin numbers fixed, hatched gnd added
    [PCBA-INTERFACE.kicad_pcb, PCBA-INTERFACE.kicad_sch]
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2024-03-20 SUKU schematic name fixed
    [PCBA-TEK1.kicad_sch]
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2024-03-25 SUKU lcd offset fixed
    [PCBA-TEK1.kicad_pcb]
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2024-03-27 SUKU erc fixed for coprocessor gpio routing
    [PCBA-TEK1.kicad_pcb]
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2024-04-24 SUKU grid mounting hole pads updated in library and on TEK1 and EN16
    [PCBA-TEK1.kicad_pcb, UI_DISPLAY.kicad_sch]
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2024-04-24 SUKU erc fix
    [UI_DISPLAY.kicad_sch]
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2024-05-29 SUKU reverse endless pot progress but not routed yet
    [PCBA-TEK1.kicad_pcb, UI_POT_BTN.kicad_sch]
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2024-06-18 SUKU switch replaced, make drc removed for TEK1
    [GRID.kicad_sch, PCBA-TEK1.kicad_pcb, UI_BUTTON.kicad_sch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]
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2024-06-24 SUKU tek1 reverted to omron design
    [GRID.kicad_sch, PCBA-TEK1.kicad_pcb, UI_BUTTON.kicad_sch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]
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2024-06-24 SUKU erc fixed
    [UI_POT_BTN.kicad_sch]
2024-06-24 SUKU key cap replaced
    [PCBA-TEK1-BTNGROUP.kicad_pcb]
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2024-06-26 SUKU FPC clearance fixed
    [PCBA-TEK1.kicad_pcb]
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2024-07-01 SUKU buttongroup drc fixed, zoom level reduced
    [PCBA-TEK1-BTNGROUP.kicad_pcb, PCBA-TEK1-BTNGROUP.kicad_sch]
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2024-07-05 SUKU erc severity for edge clearence fixed
    [GRID.kicad_sch, HWCFG.kicad_sch, MCU.kicad_sch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]
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2024-07-09 KLD mapmode origin reset
    [PLASTIC-MAPMODE.FCStd]
2024-07-09 KLD magnet cover origin reset
    [PLASTIC-MAGNET-COVER.FCStd]
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2024-07-11 KLD yml file typo fix
    [3D_printed_canvas.FCStd]
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2024-07-16 SUKU buttongroup modified for better clearance
    [PCBA-TEK1-BTNGROUP.kicad_pcb]
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2024-07-30 SUKU pogo and battery name fixed and export added
    [BATTERY_SPRING.FCStd, Ball_test.FCStd, CFE_BP109621.FCStd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]
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2024-08-13 SUKU inverted comperator logic and discreet p-fet implementation
    [PCBA-INTERFACE.kicad_pcb, PCBA-INTERFACE.kicad_sch]
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2024-08-16 SUKU interface export fix
    [PCBA-INTERFACE.kicad_pcb]
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2024-10-07 SUKU minor fixed
    [PCBA-VSNX-LCDMOUNT.kicad_pcb, PCBA-VSNX-LCDMOUNT.kicad_sch, PCBA-VSNX.kicad_pcb]
2024-10-07 SUKU try fix
    [PCBA-VSNX-LCDMOUNT.kicad_pcb]
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2024-11-27 KLD display interface v5 fixing
    [PLASTIC-VSN1-DISPLAY-INTERFACE_v5.FCStd]
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2024-12-26 SUKU renamed to fix workflow
    [PCBA-BU16-FRONTPANEL.kicad_pcb, PCBA-BU16-FRONTPANEL.kicad_sch]
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2025-01-07 SUKU all pcb frontpanels updated to use proper footprints, silkscreen variables and design rules
    [PCBA-BU16-FRONTPANEL.kicad_pcb, PCBA-BU16-FRONTPANEL.kicad_sch, PCBA-EF44-FRONTPANEL.kicad_pcb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]
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2025-01-17 SUKU powerflag added to fix erc
    [AUDIO.kicad_sch]
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2025-01-17 SUKU ESOP footprint rotation and 3d model fixed
    [PCBA-VSNX.kicad_pcb]
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2025-01-18 SUKU readme updated, erc fixed
    [PCBA-BU16-PLATE.kicad_sch]
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2025-02-06 SUKU name and erc fixed
    [PCBA-PBF4-SPACER.kicad_pcb, PCBA-PBF4-SPACER.kicad_sch, PCBA-VSNX-SPACER.kicad_pcb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]
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2025-02-11 SUKU encoder footprint created for songhuei and EN16 EF44 designs updated, potmeter and encoder 3D files updated
    [PCBA-EF44.kicad_pcb, PCBA-EN16.kicad_pcb, UI_ENC_FILTER.kicad_sch]
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2025-02-12 SUKU tek2 erc fixed, en16 debug mode layout done
    [MCU.kicad_sch, PCBA-EN16.kicad_pcb, PCBA-TEK2.kicad_pcb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]
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2025-02-13 SUKU erc fixed, design reannotated
    [PCBA-EN16.kicad_pcb, USB_POWER.kicad_sch]
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2025-02-25 SUKU tolerances updated
    [PLASTIC-BUSHING-POT.FCStd, PLASTIC-MAGNET-COVER.FCStd]
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2025-03-03 SUKU VSN1 button tolerance updated
    [PLASTIC-VSN1-BUTTON.FCStd]
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2025-03-03 SUKU spacer tolerances updated
    [PCBA-BU16-SPACER.kicad_pcb, PCBA-EF44.kicad_pcb, PCBA-VSNX-SPACER.kicad_pcb]
2025-03-10 SUKU PLASTIC-CANVAS modified for latest tool changes removing magnet cover and improving cube magnet fit
    [PLASTIC-MAGNET-COVER.FCStd]
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2025-03-23 SUKU menu button footprint pad size reduced to improve positioning tolerance
    [LCDBUTTON.kicad_sch, MCU.kicad_sch, PCBA-VSNX.kicad_pcb]
2025-03-23 SUKU mapmode 3d file path fixed
    [PCBA-VSNX.kicad_pcb]
2025-03-23 SUKU reset and boot button footprints updated
    [MCU.kicad_sch, PCBA-BU16.kicad_pcb, PCBA-EF44.kicad_pcb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]
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2025-03-31 SUKU snap fit tolerance modified
    [PLASTIC-VSN1-DISPLAY-INTERFACE.FCStd, PLASTIC-VSN1-DISPLAY-INTERFACE_v2.FCStd, PLASTIC-VSN1-DISPLAY-INTERFACE_v3.FCStd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]
2025-03-31 SUKU rp2040 rotation updated, bu16 missing smd nuts added
    [PCBA-BU16.kicad_pcb, PCBA-BU16.kicad_sch]
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2025-04-26 SUKU drawing fixed
    [RUBBER-FOOT.FCStd]
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2025-04-29 SUKU file name fixed
    [SCREW-M1.6x5-C.FCStd]
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2025-05-14 SUKU size fixed
    [PLASTIC-MAPMODE.FCStd]
2025-05-14 SUKU FP-XX16-TEST added to test drill sizes for lightpiupe and panle texture on front and back soldermask
    [FP-XX16-TEST.kicad_pcb, FP-XX16-TEST.kicad_sch]
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2025-05-30 SUKU mapmode tolerances updated
    [PLASTIC-MAPMODE.FCStd]
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2025-06-27 SUKU hwcfg center detent variant added for PO16 and PBF4 via solder jumper option
    [HWCFG.kicad_sch, PCBA-PBF4.kicad_pcb, PCBA-PO16.kicad_pcb]
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2025-07-25 BENB route CS0 and RESET around breakable tabs
    [PCBA-VSNX-LCDMOUNT.kicad_pcb]
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2025-10-04 SUKU pot filenames fixed
    [PLASTIC-KNOB-ENC.FCStd, PLASTIC-KNOB-POT.FCStd]
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2025-10-20 SUKU 3d file path fixed
    [PCBA-DEBUG-UART.kicad_pcb]
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2025-10-31 reverting to current designs
    [MAGNET-D3x14.FCStd, PLASTIC-KNOB-ENC.FCStd, PLASTIC-KNOB-POT.FCStd]
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2025-12-28 SUKU reverted to single opamps
    [PCBA-OCTV.kicad_pcb, PCBA-OCTV.kicad_sch, QUAD_INVERT_AND_OFFSET.kicad_sch]
2025-12-28 SUKU encoder schematic and layout imported from EN16, ERC fixed, annotation completed
    [ENCODER_8.kicad_sch, HWCFG.kicad_sch, PCBA-OCTV.kicad_pcb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]
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2026-01-05 SUKU mcu layout moved, inrow leds routed, all DRC errors fixed
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2026-01-12 SUKU spacer erc fixed, frontpanel added
    [FP-OCTV.kicad_pcb, FP-OCTV.kicad_sch, PCBA-OCTV-SPACER.kicad_pcb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]
2026-01-12 SUKU led and hall parts replaced due to suourcing
    [UI_LED.kicad_sch, UI_OCTAVE.kicad_sch]
2026-01-12 SUKU xtal footprint replaced
    [PCBA-DEBUG-UART.kicad_pcb, PCBA-DEBUG-UART.kicad_sch]
2026-01-12 SUKU led value fixed
    [UI_LED.kicad_sch]
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2026-02-25 SUKU debug accessory drc fixed
    [PCBA-DEBUG-ACCESSORY.kicad_pcb]
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2026-02-25 Fix duplicate body labels in PLASTIC-VSN1-DISPLAY-INTERFACE
    Renamed clashing PartDesign::Body labels that duplicated names from
    PLASTIC-VSN1-BUTTON.FCStd, causing the nightly mechanical release
    upload to fail with HTTP 404 on duplicate asset names.
    [PLASTIC-VSN1-DISPLAY-INTERFACE.FCStd]
2026-02-25 Reduce electrical release artifact count and update README previews
    Exclude CI-only files (drc/erc html, kibot log/filter) and redundant
    3D renders (top/bottom png) from release uploads, reducing asset count
    from 576 to 360 to avoid GitHub secondary rate limit on deploy.
    Update README to use blender-rendered previews for all electrical boards.
2026-02-25 Upgrade to action-gh-release@v2 and swap blender PNGs for standard renders
    - Switch to softprops/action-gh-release@v2 for sequential uploads and
    built-in rate limit retry, fixing recurring HTTP 403 on deploy
    - Exclude blender PNG renders in favour of smaller standard 3D top/bottom
    - Exclude PCB top/bottom PDFs from release uploads (324 assets total)
2026-02-25 Filter mechanical artifacts to component-prefixed files only
    Restrict upload glob to temp/<component>*.* so only files named after
    the matrix component are included, preventing generic FreeCAD body names
    (Clone1, Body, etc.) from leaking into the release.
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2026-02-25 Guard against missing files for FP- boards in workflow
    Position file conversion and PDF renames now skip gracefully when files
    are absent, since FP-GENERIC.kibot.yaml does not generate schematic,
    PCB PDFs or position files.
2026-02-26 Rename reference files to component-prefixed names and fix upload filter
    - Rename reference_COMPONENT*.* to COMPONENT_*.* so the upload filter
    temp/${{ matrix.component }}*.* correctly includes them in CI artifacts
    - Update copy step to use find with component prefix instead of reference_ prefix,
    excluding .FCStd and .FCBak files
    - Update README links to match new filenames
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2026-03-20 SUKU spacer updated, tolerance added
    [SPACER.FCStd]
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2026-03-30 SUKU XY structure reworked
    [PCBA-XY-LED.kicad_pcb, PCBA-XY-LED.kicad_sch, PCBA-XY-TOUCH.kicad_pcb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]
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2026-03-30 SUKU drawing name fixed to remove whitespace
    [PLASTIC-KNOB-POT.FCStd]
2026-03-30 SUKU xy fixes
    [FP-XY-SPACER.kicad_pcb, FP-XY.kicad_pcb, PCBA-XY-LED.kicad_pcb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]
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2026-03-31 SUKU rename to try to fix workflow
    [THT-ENC.step, THT-POT.step]
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2026-05-08 SUKU xy led layout redesigned
    [PCBA-XY-TOUCH.kicad_pcb, PCBA-XY-TOUCH.kicad_sch]
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2026-05-19 SUKU ci broken frontpanels migrated to kicad 10
    [FP-BU16-MIDIGRADE.kicad_pcb, FP-BU16.kicad_pcb, FP-EF44.kicad_pcb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]
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2026-07-08 fix CI: install zip in container for variant gerber packaging
2026-07-08 restructure FP-XY-DECOR-BOLD variants as separate projects with CI matrix entries
    Each variant (CROSS, DOT, MINICROSS, MIX) now lives in its own
    directory with its own schematic, project file, and Makefile.
    Each gets its own parallel CI job via the matrix.
    Removed the multi-variant Makefile magic and the Process variant
    outputs CI step. The only cross-board fix retained is the kibot
    ibom regression patch (unrelated to variants).
    [FP-XY-DECOR-BOLD-CROSS.kicad_pcb, FP-XY-DECOR-BOLD-CROSS.kicad_sch, FP-XY-DECOR-BOLD-DOT.kicad_pcb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]
2026-07-15 add FP-PBF4-DJ and FP-XX16-DJ front panel variants with CI matrix entries
    Relocate the loose DJ-FP-PBF4 and DJ-XX16 KiCad files into proper
    per-project folders following the repo convention, renamed to the
    FP-<base>-DJ scheme. Each gets a Makefile plus the schematic and
    footprint lib tables copied from its base project (FP-PBF4 / FP-XX16),
    since CI runs ERC on a schematic and the dropped files were PCB-only.
    Both boards are added to the electrical_boards CI matrix.
    [FP-PBF4-DJ.kicad_pcb, FP-PBF4-DJ.kicad_sch, FP-XX16-DJ.kicad_pcb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]
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2026-08-07 SUKU rp2350 fixes
    [GRID.kicad_sch, HWCFG.kicad_sch, INVERT_AND_OFFSET.kicad_sch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]
2026-08-07 SUKU library fixed, mapmode fixed layout done
    [MCU.kicad_sch, PCBA-BU16.kicad_pcb]
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2026-08-24 SUKU fail workflow if silkscreen is missing on any designs
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2026-08-25 SUKU silkscreen gate flags empty-marker layers with real content
    The ${LAYER}-is-intentionally-empty marker only makes sense as the sole
    item on its layer; a layer carrying it alongside real silkscreen now
    fails instead of silently passing. Passing marker-only layers are
    annotated in the report as "ok (front/back: empty marker detected)".
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2026-09-01 SUKU kibot gerber options trimmed to non-default overrides
    The gerber_options block in each kibot config restated several KiCad/
    KiBot defaults verbatim (exclude_edge_layer, plot_sheet_reference,
    plot_footprint_refs, force_plot_invisible_refs_vals, tent_vias,
    use_protel_extensions, gerber_precision, line_width); removed as noise.
    Also drops plot_footprint_values: false, which suppressed every
    footprint's Value text on export (including JP801's "ND" solder-jumper
    label on PCBA-EF44) — footprint values now plot to gerbers again,
    project-wide, matching KiBot's default.
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2026-09-01 SUKU schematic drift CI scriptt added, expect it to fail on BU16 MCU sheet
2026-09-01 SUKU schematic drift checker gets GitHub Actions job summary
    Mirrors check_silkscreen.sh's --github support: auto-enabled under
    GITHUB_ACTIONS=true, emits ::error annotations for drifted files, and
    writes a per-sheet markdown table to GITHUB_STEP_SUMMARY. Stdout output
    is unchanged either way.
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2026-09-02 SUKU DRC settings drift checker added, wired into CI
    Compares board.design_settings.{rules,rule_severities,drc_exclusions}
    between EF44 and BU16 — the DRC constraint thresholds, per-violation
    severities, and waived violations, which are the only design_settings
    keys directly tied to manufacturability (as opposed to editor
    defaults/presets/cosmetics, which are left alone). Same conventions as
    check_silkscreen.sh and check_schematic_drift.py: deterministic report,
    exit 0/1/2, --github auto-enabled under GITHUB_ACTIONS=true for error
    annotations + job summary.
    Wired up as a new "DRC settings gate" job in electrical_boards.yml,
    parallel to silkscreen-check and schematic-drift-check; generate-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
2026-09-02 SUKU BU16 DRC severities matched to EF44's stricter policy
    7 rule_severities had been downgraded on BU16 relative to EF44 (mostly
    footprint/library-consistency checks: duplicate_footprints,
    extra_footprint, footprint_symbol_field_mismatch,
    footprint_symbol_mismatch, missing_footprint, net_conflict error->warning;
    footprint_filters_mismatch warning->ignore). Restored to EF44's values.
    Verified with check_drc_settings_drift.py: rules, rule_severities, and
    drc_exclusions all match now.
2026-09-02 SUKU DRC/ERC drift checker merged, EF44 ERC severities tightened
    check_drc_settings_drift.py replaced by check_design_rules_drift.py,
    which covers both DRC (board.design_settings: rules, rule_severities,
    drc_exclusions) and ERC (erc: rule_severities, pin_map, erc_exclusions)
    in one pass, reported per-section. Wired into CI as "design-rules-check"
    / "design rules gate", generate-artifacts updated to depend on it.
    EF44's erc.rule_severities also tightened: 18 checks bumped from
    warning/ignore to error (labeling/connectivity hygiene — similar_labels,
    no_connect_dangling, unconnected_wire_endpoint, four_way_junction, etc).
    BU16 still has the old severities for these, which the new checker now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
2026-09-02 SUKU BU16 ERC severities matched to EF44's stricter policy
    18 erc.rule_severities had been left at warning/ignore on BU16 relative
    to EF44's tightened policy (labeling/connectivity hygiene checks:
    similar_labels, no_connect_dangling, unconnected_wire_endpoint,
    four_way_junction, single_global_label, etc). Bumped to EF44's values.
    Verified with check_design_rules_drift.py: DRC and ERC both identical now.
2026-09-02 SUKU EF44/BU16 register suku_basics symbol library
    fp-lib-table already registered suku_basics footprints per-project, but
    no project ever had a matching sym-lib-table for the symbol library.
    CI's KiCad has no personal global library config, so ERC has always
    flagged every suku_basics symbol as lib_symbol_issues — silently
    tolerated while that rule was "warning", now fatal since we bumped it
    to "error" to match EF44's stricter ERC policy. Verified locally with
    an isolated KICAD_CONFIG_HOME: the suku_basics complaint is gone.
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2026-09-02 SUKU preflight checks refactored into a matrixed, baseline-driven gate
    schematic-drift-check, design-rules-check, and annotation-check merged
    into one preflight-check job, matrixed over design: [PCBA-EF44,
    PCBA-BU16]. The golden-standard baseline (PCBA-EF44) is now set once via
    env.BASELINE_DESIGN in the workflow, not hardcoded into the checker
    scripts — both comparative checks (schematic drift, DRC/ERC settings)
    run as baseline-vs-matrix-leg; annotation stays non-comparative (checks
    a design's own reference-designator strategy, not agreement with
    another design). Adding a design to the matrix brings it under every
    comparative check automatically.
    preflight-check now needs silkscreen-chec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
2026-09-02 SUKU preflight checkers' GitHub summaries shortened to a single line
    All four checkers (silkscreen, schematic drift, design rules, annotation)
    now write one line to GITHUB_STEP_SUMMARY on success (tick emoji, test
    description, baseline named where the check is comparative), and only
    emit the detailed per-item table when there's an actual finding. Keeps
    the job summary scannable across the whole matrix instead of always
    printing a table, empty rows and all, even when everything passed.
2026-09-02 SUKU layout and hwcfg fixed
    [HWCFG.kicad_sch, INVERT_AND_OFFSET.kicad_sch, PCBA-BU16.kicad_pcb]
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2026-09-07 SUKU netlist updated to fix schematic parity
    [PCBA-BU16.kicad_pcb, PCBA-EF44.kicad_pcb, PCBA-PO16.kicad_pcb]
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2026-09-08 SUKU po16 silkscreen deisgnators around HWCFG fixed
    [PCBA-PO16.kicad_pcb]
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2026-10-02 BENB fix unconnected pad on zona touch
    [PCBA-ZONA-TOUCH.kicad_pcb, PCBA-ZONA-TOUCH.kicad_sch]
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2026-10-07 BENB rework zona led/touch dimensions
    [FP-ZONA.kicad_pcb, PCBA-ZONA-LED.kicad_pcb, PCBA-ZONA-LED.kicad_sch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]
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2026-10-08 SUKU touch connector symbol and component value fixed
    [PCBA-ZONA-TOUCH.kicad_pcb, PCBA-ZONA-TOUCH.kicad_sch]
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2026-10-15 SUKU PCBA-ZONA connector orientation fixed
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2026-11-03 Add missing PLASTIC-ZONA-ARCH and RUBBER-SPACER FreeCAD source files (#59)
    CI matrix and README referenced these designs but the .FCStd files were
    never pushed to main, so the export job silently produced no artifacts.
    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
2026-11-07 Consolidate and rename RGB LED symbols/footprints across projects (#60)
    - Rename UI_XL-1010RGBC-2812B -> UI_LED_RGB_1010 (PCBA-ZONA-LED)
    - Rename UI_WS2812C-2020 -> UI_LED_RGB_2020, including footprint
    (PCBA-KB25, PBF4, TEK2, EN16, VSNX, OCTV)
    - Merge duplicate UI_XL-0807RGBC-2812B-S into UI_LED_RGB_2020
    (PCBA-BU16, PO16, EF44), removing the now-orphaned symbol/footprint
    - Fix stale per-instance Value overrides to match the canonical part
    value in each family
    - Remove unused PCBA-ZONA-TOUCH/LED.kicad_sch sheet
    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
